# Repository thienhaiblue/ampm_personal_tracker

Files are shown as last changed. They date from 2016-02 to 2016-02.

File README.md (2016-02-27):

# ampm_personal_tracker
Security and safety is an essential feature for this product.Hence, it is extremely
critical to ensure the unit is able to make the SOS call and send the timely and
accurate GPS location to the dedicated party.
.
The GPS tracker shall be able to send GPS location, making emergency voice call
by pressing SOS button. In order to provide quick and accurate GPS location, cell
ID and AGPS technology is incorporated in this device. The data (GPS location,
remaining battery capacity etc.) shall be sent by both GPRS and SMS (the choice
will be determined in the detail logic flow and MMI document).
GSM frequency. Quad band 850/900/1800/1900.
GPRS type – Class 10, TCP/IP build in
GPS sensitivity - 159 dBm

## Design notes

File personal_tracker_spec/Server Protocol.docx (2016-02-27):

Protocol

Command first byte is D, like DRPT / DOPT mean is Device sent data to Server

Command first byte is S, like SRPT / SOPT mean is Server sent data to Device

Command Table

Comment | Description | Remarks
DLGI | Device send “LOG IN” request to Server
DRPT | Tracker Log with GPS / AGPS fixed | Status Report (GPS / AGPS fixed)
SRPT | Server responses, confirms Tracker log in, setup Report frequency & Power Saving Mode
DDPT | Tracker responses, confirms log in OK, wait for OTA
SOPT | Server set out OTA comment to Tracker
DOPT | Tracker confirms receipt of OTA comment
DLBS | Status Report | Status Report (GPS / AGPS not fixed)
DCHK | Tracker Log without GPS / AGPS fixed, Send out Cell ID location
SNOW | Find Device Command | Tracker sent out Status Report after receipt of command
SSVR | Server inform Device to change IP / TCP setting
DSVR | Device responses IP / TCP port to Server
SGFS | Geofence Set up to Device
DGFS | Device responses Geofence Setting
SFLO | Forced Device to Logout
SMDS | Man down setting
DMDS | Device responses Man down setting
DFLO | Device Layout responses | Server Maintenance Purpose

Format:ASCLL code

LEAD CODE | COMMAND CODE | CONNECTING SESSION | Total byte check | Parameter
@ 1 byte | CCCC 4 byte | CCC (0..999) 3 byte *Server to Device: An odd accumulation *Device to Server: An even accumulation | Ccc(000..999) 3 byte | (command string ) Please refer to every command.

Function | | Command | Description
Log In Request | Device Power ON / Initialize (Device → Server) | DLGI
| | | e.g. | @DLGI008045352352025153767MPERS_FamilyPal_2053_CMNET_209 @ is LEAD code DIGI is command code 008 is connecting session 045 is Total 85 byte 352352025153767 is IMEI MPERS_FamilyPal_2053_CMNET_209 is firmware Version
Status & GPS Location Report | Status Report Format (Device → Server) | DRPT
| | | e.g. | @DRPT00808535235202515376711120802541222.320729N111.3560030E32100000A000000000000000 @ is LEAD code DRPT is command code 008 is connecting session 085 is Total 85 byte 352352025153767 is IMEI 111208 = 2008/12/11 025412 = UTC time 2:54:12 22.320729N = GPS Latitude 113.560030E = GPS Longitude 000.0 = Speed Over Ground is 0 321 = Course Over Ground ( direction 321°) 00000 = Reserve A = GPS status 000000000000000 = 15 bytes reserve Refers to “Status Report Format”

Function | | Command | Description
| Status Report Format (Server →Device ) | SRPT | HH MM SS Reporting Frequency: Type0-9, Hour(0-99), Minutes (0-59), seconds(0-59)
| | | e.g. | @SRPT009007000030 @ is LEAD code SRPT is command code 009 is connecting session 007 is Total 7 byte 000030 is Report Frequency 30 sec
| Status Report Format (Device → Server) | DDPT | HH MM SS Reporting Frequency: Type0-9, Hour(0-99), Minutes (0-59), seconds(0-59)
| | | e.g. | @DDPT009007352352025153767000030 @ is LEAD code DDPT is command code 009 is connecting session 007 is Total 7 byte 352352025153767 is IMEI 000030 is Report Frequency 30 sec

Function | | Command | Description
Parameter setup | Device Initialization OTA setting (Server →Device ) | SOPT | SMS Setting Password , if you want use SMS to setting any parameter, you must use this password, the password set in Webs Type 0-9, Length = 4 Lone worker 0: OFF 1: ON (default 30 min) Lone worker Active (Min.) 0001~1000 Lone work countdown time 01-30 (Min) No Movement 0: OFF 1: ON (default 720 min) No Movement Active (HR.) 001~720 Auto-answer 0: OFF 1: ON Language 00-08 Mobile Number Type 0-9; Length = no control; Separate by “,”; use “,” to separate; Max. 6 Group
| | | e.g. | @SOPT014069000010030301720100+886289673211,+886289672515,+886968123456,+886,+886,+886 @ is LEAD code SOPT is command code 014 is connecting session 069 is Total 69 byte 0000 is SMS Setting Password 1 is Lone worker on 0030 is Lone worker Active at 30 min. 30 is Lone work countdown time (1-30min) 1 is No Movement on 720 is No Movement Active at 720 HR. 1 is auto answer on 00 is voice Language English Mobile phone number is +886289673211,+886289672515,+886968123456,+886,+886,+886,

Function | | Command | Description
Parameter setup | Device Initialization OTA setting (Device → Server) | DOPT | SMS Setting Password , if you want use SMS to setting any parameter, you must use this password, the password set in Webs Type 0-9, Length = 4 Lone worker 0: OFF 1: ON (default 30 min) Lone worker Active (Min.) 0001~1000 Lone work countdown time 01-30 (Min) No Movement 0: OFF 1: ON (default 720 min) No Movement Active (HR.) 001~720 Auto-answer 0: OFF 1: ON Language 00-08 Mobile Number Type 0-9; Length = no control; Separate by “,”; use “,” to separate; Max. 6 Group
| | | e.g. | @DOPT014069352352025153767000010030301720100+886289673211,+886289672515,+886968123456,+886,+886,+886 @ is LEAD code SOPT is command code 014 is connecting session 069 is Total 69 byte 352352025153767 is IMEI 0000 is SMS Setting Password 1 is Lone worker on 0030 is Lone worker Active at 30 min. 30 is Lone work countdown time (1-30min) 1 is No Movement on 720 is No Movement Active at 720 hr. 1 is auto answer on 00 is voice Language English Mobile phone number is +886289673211,+886289672515,+886968123456,+886,+886,+886,

Function | | Command | Description
Status & Cell ID Location Report (GPS no fix) | Status Report Format (Device → Server) | DLBS
| | | e.g. | @DLBS00808535235202515376711120802541222.320729N113.560030E000.032100000V000000000000000 @ is LEAD code DLBS is command code 008 is connecting session 085 is Total 85 byte 352352025153767 is IMEI 111208 =2008/12/11 025412= UTC time 2:54:12 22.320729N = Cell ID Latitude 113.560030E = Cell ID Longitude 000.0 = Speed Over Ground is 0 321 = Course Over Ground ( direction 321°) 00000 = Reserve V = without =GPS 000000000000000 = 15 bytes reserve Refers to “Status Report Format”
| Check Connection (Device → Server) | DCHK | IMEI NO. Type 0-9 , Length 15
| | | e.g. | @DCHK004015352352025153767 @ is LEAD code DCHK is command code 004 is connecting session 015 is Total 15 byte 352352025153767 is IMEI

Function | | Command | Description
| Find Device (Server -> Device) | SNOW | IMEI No. Type 0-9, Length 15
| | | e.g. | @SNOW004015352352025153767 @ is LEAD code SNOW is command code 004 is connecting session 015 is Total 15 byte 352352025153767 is IME
| Server Domain / Port Setup (Server -> Device) | SSVR | Change Server Domain & Port
| | | e.g. | @SSVR018016seniorcare.vicp.hk:6868 @ is LEAD code SSVR is command code 018 is connecting session 016 is total 16 byte seniorcare.vicp.hk is Domain 686 8 is Port
| Server Domain / Port Responses (Device -> Server) | DSVR | Server Domain & Port
| | | e.g. | @DSVR018016352352025153767seniorcare.vicp.hk:6868 @ is LEAD code DSVR is command code 018 is connecting session 016 is total 16 byte 352352025153767 is IME seniorcare.vicp.hk is Domain 686 8 is Port

Function | | Command | Description
| Geo fence Setup (Server → Device) | SGFS | Geo fence Center point / Longitude / Latitude / Radius (Meter)/Time(Min) All “Zero” if the Geo fence is turn OFF. Time : 00 ~ 59 Min.
| | | e.g. | @SGFS01901825.040701,121.815928,50,10 @ is LEAD code SGFS is command code 019 is connecting session 018 is total 18 byte 25.040701 is Latitude 121.815928 is Longitude 50 is radius (Meter) 10 is time (Min)
| Geo fence Setup Format (Device → Server) | DGFS | Geo fence Center point / Longitude / Latitude / Radius (Meter)/Time(Min) All “Zero” if the Geo fence is turn OFF. Time : 00 ~ 59 Min.
| | | e.g. | @DGFS01901835235202515376725.040701,121.815928,50,10 @ is LEAD code SGFS is command code 019 is connecting session 018 is total 18 byte 352352025153767 is IME 25.040701 is Latitude 121.815928 is Longitude 50 is radius (Meter) 10 is time (Min)

Function | | Command | Description
| Man down Setup (Server → Device) | SMDS | Man down 0 : OFF 1: ON Man down time 00~59 (min)
| | | e.g. | @SMDS020003001 @ is LEAD code SMDS is command code 020 is connecting session 018 is total 18 byte 0 is Man down off 01 is time (Min)
| Man down Setup Format (Device → Server) | DMDS | Man down 0 : OFF 1: ON Man down time 00~59 (min)
| | | e.g. | @SMDS020003352352025153767001 @ is LEAD code SMDS is command code 020 is connecting session 018 is total 18 byte 352352025153767 is IME 0 is Man down off 01 is time (Min)

Function | | Command | Description
| Forced Logout (Server → Device) | SFLO | IMEI No. Type 0-9, Length 15 This command to be used when Server Maintenance or abnormal operation was found
| | | e.g. | @SFLO004015352352025153767 @ is LEAD code SFLO is command code 004 is connecting session 015 is Total 15 byte 352352025153767 is IMEI
| Logout Responses (Device → Server) | DFLO | IMEI No. Type 0-9, Length 15 This command to be used when Power off device.
| | | e.g. | @DFLO004015352352025153767 @ is LEAD code DFLO is command code 004 is connecting session 015 is Total 15 byte 352352025153767 is IMEI

Status Report Format : (Total 70 Characters)

IMEI | Greenwich Date | Greenwich Time | Latitude | N/S | Longitude | E/W | Speed | Direction | Distance | GPS Fix | Status Alert
Xxxxxxxxx xxxxx | nnnnnn | nnnnnn | nn.nnnnnn | C | nn.nnnnnn | C | nnn.n | nnn | nnnnn | C | CCCCCCCCCCCCCCC
| DDMMYY | HHMMSS | nn.nnnnnn degree | N:NL S:SL | nn.nnnnnn degree | E:EL W:WL | (NM) | (degree) | (Meter) | Realtime: A:Fix OK V:Fix NG | Format refers to (P1)
15 | 6 | 6 | 9 | 1 | 10 | 1 | 5 | 3 | 5 | 1 | 15

(P1) Status Alert

Column | 1 | 2 | 3/4 | 5/6/7 | 8 | 9 | 10 | 11 | 12 | 13 | 14 | 15
Content | 0 | 0 | 00 | 000 | 0 | 0 | 0 | 0 | 0 | 0 | 0 | 0
Status | Check | Geo fence Check | GSM signal Check | Battery Voltage Check | Charging Check | Battery Low Check | Reserved | Man Down Check | Lone worker Check | No Movement Check | Reserved | Reserved

Status Alert Details

[1] 1st byte Detection SOS button
Value | Description
0 | Default, ( SOS off )
1 | SOS Key on
2 | SOS Key off
3 | Lone worker SOS
4 | Man Down

[2] Geo fence Check
Value | Description
0 | Default, No report on Geo fence
1 | Exclusion zone
2 | Inclusion zone

[3/4] GPRS Check
Value | Description
0~99 | CSQ : 0~99
| 4> CSQ = 99 | No signal
| 4 < CSQ <10 | Level 1
| 10 < CSQ <16 | Level 2
| 16 <CSQ <22 | Level 3
| 22 < CSQ <28 | Level 4
| 28 < CSQ | Level 5

[5/6/7] Battery Voltage Check
Value | Description
000~999 | Voltage with 2 decimal points (e,g. 4.15V >> 415)

[2] Geo fence Check
Value | Description
0 | Default, No report on Geo fence
1 | Exclusion zone
2 | Inclusion zone

[8] Charging Check
Value | Description
0 | Default, Not under Charging
1 | Under Charging

[9] Low Battery Check
Value | Description
0 | Default, Battery normal
1 | Low Battery, below 25%
2 | No Battery, 5% remained

[10] Reserved

[11] Man Down Check
Value | Description
0 | Default, No report
1 | Man down Active

[12] Lone worker Check
Value | Description
0 | Default, no report
1 | Lone worker Alert Active (Server set time reached)

[13] No Movement Check
Value | Description
0 | Default, no report
1 | No Movement Alert Active (Server set time reached)

[14] Reserved

[15] Reserved

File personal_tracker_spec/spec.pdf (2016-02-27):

Product Features

Security and safety is an essential feature for this product. Hence, it is extremely critical to ensure the unit is able to make the SOS call and send the timely and accurate GPS location to the dedicated party.
The GPS tracker shall be able to send GPS location, making emergency voice call by pressing SOS button. In order to provide quick and accurate GPS location, cell ID and AGPS technology is incorporated in this device. The data (GPS location, remaining battery capacity etc.) shall be sent by both GPRS and SMS (the choice will be determined in the detail logic flow and MMI document).

GSM frequency. Quad band 850/900/1800/1900.
GPRS type – Class 10, TCP/IP build in
GPS sensitivity - 159 dBm

## Industrial Design

## Physical Specifications

Item | Description | Specifications
Dimension ( Products) | Length | 66 mm
| Width | 43mm
| Thickness | 20 mm
Antenna | GPS | Internal
| GSM/GPRS | Internal

## Handset

Item | Description | Specification
Case Material | | PC
Dimensions | Handset | 66x43x20mm.
Weight | Handset | < 60 g
Water Resistance | Handset | IP57

## Environmental Specifications

Item | Description | Specification
Temperature | Operating range | -10 °C to 55 °C
| Storage range | -20 °C to 80 °C

Humidity | up to 95%

## Charging Cradle Specifications

Item | Description | Specification
Charging Cradle | SentryPal Speaker and Logo must be visible when in charging cradle. We have a concern that the base needs to have a bigger size so that it will not tip over easily when the person is putting the hand-held unit into the charger. | Uses standard AC Wall adaptor.
AC Adaptor | Standard AC Wall Adaptor | Tip _____ 110/220 Volts at 500 mA
Battery Charging | Via two metal prongs that make contact to Charging Station
Charging time – estimated from dead battery | | 2 hours

## Detail feature list

Physical dimension
1. Size (outside dimension include plastic) : 66x43x20mm (maximum)
2. Water proof and dust proof standard: IP57. The unit shall be robust enough for sudden impact (fall down action by end customer).
3. 4 pin connector for data
4. 1 button for SOS call, and 1 small button for other functions (e.g. power on/off, cancel)
5. Separate standalone charger for device.

Volume level. The device shall be set at maximum level. Speakerphone mode is automatic when the device is connected. It shall be over 90dB at 0.1m from speaker.

LED indication
1 for battery, 1 for GSM, 1 for
GPS Power specification
1. Talk time : continuous not less than 2 hours (base on 700mAH Li-Polymer or Li-ION battery. We continuously finding higher capacity battery e.g. 800mAH Li-Ion)
2. Battery life for GPS sending data (location / battery level) every 15 mins. : not less than 4 days in sleeping mode. Not less than 1 day in standby mode.
3. GPRS Data amount in 30 days base on GPS sending data (location / battery level) every 15 mins. : not more than 5M byte
4. Total charging time : 2 hours

5. Charging circuit. Protection circuit for battery and for the device shall be included. This is to ensure that there will not be over-charging, or not able to charge when the device is not charged for long period of time.

GPS
1. GPS Time to first fix – cold start (autonomous) 36 sec, warm start (autonomous) 36 sec, hot start (autonomous) < 1 sec.
2. Cell ID and AGPS technology shall also be integrated. During in-door condition where GPS is not obtainable, the last valid GPS location or cell ID location (whichever is more accurate) will be sent.
3. Geo-fencing

Voice prompt
1. Voice prompt provided for different application
2. DTMF detection for answering machine

User case / server control
1. During SOS emergency call, when connected, the device will be in speakerphone mode automatically. Sound level for speakerphone : 90dB in 0.1m from device
2. OTA command from dedicated server and dedicated SMS number, in particular sending configuration.
3. Motion sensor (3 axis accelerometer) is employed for detecting no motion in order to save power, as well as man down detection

Initial set up

See MMI below.

Appendix 5 Technical specification

## GSM/GPRS Specifications

Item | Description | specification
Air Interface | GSM or GPRS Quad Band | GSM 850 / 900 / 1800 / 1900 MHz class 4 (2 W) for 850/900 bands class 1 (1 W) for 1800/1900 bands
| GPRS | Class 10 (4 downlink, 2 uplink, max. 5) Mobile Station Class B PBCCH supported CS 1…CS 4 supported
| Power Consumption | Power Off - < 90 μA Idle Mode - <1.6 mA

| | Telephony GSM - < 300mA GPRS class 10 - 410 mA
GSM Sensitivity | 850/900 MHz | -110 dBm
| 1800/1900 MHz | -109 dBm
Messaging | SMS | PDU / Text mode / Cell broadcast
| AT Commands | 3GPP 27.005, 3GPP 27.007 3GPP 27.010 MUX Protocol

## GPS Specifications

Parameter | Description | Specification
GPS Tracking | Tracking location | Handset MUST be ON in order to be tracked (MCU and GSM must be ON in order to receive OTA command from server)
| Tracking ON/OFF Factory setting OFF | Controlled by Web Dashboard/User
Time between Pings | This is the time between each ping of the location. | This is a variable set by the user on the web dashboard. The web dashboard will send the variable minutes between pings.
Chipset | U-blox | AMY-6M
Receiver type | 50 Channels GPS L1 frequency, C/A Code SBAS: WAAS, EGNOS, MSAS
Time-To-First-Fix2 | Cold Start (Autonomous) | <36 sec.
| Hot Start (Autonomous) | <36 sec.
Data packet size - GPS update | | 128 bytes of data per transmission re: eo-locating
Sensitivity4 | Tracking & Navigation | -159 dBm
| Reacquisition | -159 dBm
| Cold Start (Autonomous) | -146 dBm
Maximum Navigation update rate | | 5Hz
Accuracy | Position | 2.5 m CEP - Circular Error Probability
| SBAS - Satellite-Based Augmentation Systems | 2.0 m CEP - Circular Error Probability
Time pulse frequency range | Configurable | 0.1 Hz to 1 kHz
Operational Limits | Dynamics | ≤ 4 g
| Altitude6 | 50,000 m
| Velocity6 | 500 m/s

Appendix 6 MMI

## Input

Item | Description | Specification
Mic
4 pin connector | Update firmware Debug message
EMERGENCY button Recessed into case to help prevent accidental pushes | Hold for 1 second SentryPal must be ON to initiate EMERGENCY call | Initiate Emergency call: Voice Prompt [EMERGENCY call is being placed - please stand by] prompt 3.1, 3.2 Prompt played 1 time
| Hold for 1 second during incoming call/ringing. | Answering Incoming Call
Small Dark Gray button | Hold for 1 second – during an active call | Ends call and resets the handset Voice Prompt [Hanging UP] prompt 3.3
| Hold for 4 seconds – when phone is ON Hold for 4 sec. – when phone is OFF | Turn SentryPal OFF Voice prompt [Power OFF] prompt 1.2 Turn SentryPal ON Voice prompt [Power ON] prompt 1.1
Hold for 1-4 seconds – when | System Check:
phone is ON | Announce battery status
| [Battery OK] prompt 2.1
| > 25% battery capacity
| [Recharge Battery Soon]
| prompt 2.2
| < 25% battery capacity
| [Lone Worker ON]
| prompt 5.3
| IF - Lone Worker option is
| set (This option is
| controlled via the web and
| OTA programming)
| [No Service Coverage]
| prompt 2.4
| IF - No GSM Service
| Signal
| [No Current GPS Fix]
| prompt 2.5
| If - Not able to track GPS
| satellites [Version # X]
| prompt 6.7

To announce software
version during system
check
Hold for 1 second | Reset Lone Worker Alarm
| Lone Worker is a special use
Lone Worker is a feature used | feature that uses the 3 axis
when someone is working in a | accelerometer to measure NO
remote area by themselves. The | movement. If movement is not
handset watches for movement | detected in n period of time, an
(normal activity of the person), if | alarm in the handset sounds – if
no movement is detected in some | the alarm is not reset with the Test
period of time an alarm is | button ( How many sec.? n period
sounded. If the person does not | is selected via the web dashboard
manually reset the alarm, it is | and OTA programming )
assumed an accident has | the SentryPal will automatically
happened and the handset | initiate an EMERGENCY call and
automatically places an | reporting current position via
Emergency call. The Lone | SMS.
Worker feature is controlled via | During charging? same
the Web dashboard then settings
are OTA to the handset

## LED Outputs

Item | Description | Specification
| BATTERY - RED LED | Off: When battery is > 25% capacity Blinking: 0.3 seconds On – 2 seconds off When battery is < 25% capacity Charging – when in cradle: Sinusoidal Pattern - On/Off/On (1 second from Off to Full Brightness, 1 second from Full Brightness to Off): Solid– when in cradle: When battery is fully charged
| GPS - BLUE LED Only ON during: During Emergency call | Solid: SOS to activate GPS, and GPS signal is OK Blinking: 0.3 seconds On – 0.3 seconds Off When SentryPal is

acquiring GPS signal or
NO GPS signal is
available.
GPS will be sent via SMS during Emergency Call
Handset will send last
known position right away, then send current position as soon as it is updated
GSM – GREEN / yellow LED | Flashing Green (0.3 sec. ON + 0.3
| sec. OFF) x 2 cycles for every 5
GSM LED will be on anytime the | sec:
phone is powered ON. This will | Anytime the SentryPal has a GSM
allow the user to know that they | connection
have GSM service coverage with
just a quick glance | Flashing Yellow (0.3 sec. ON + 0.3
| sec. OFF) x 2 cycles for every 5
| sec:
| When SentryPal is acquiring GSM
| service signal or NO GSM service
| available

## SPEAKER - Voice Announcements

Item | Description | Specification
Speaker | RING TONE | We will supply WAV file. Will be more a traditional mechanical ring sound rather than electronic
| Speaker Volume | Always set to maximum
| Voice Announcements: Power: 1.1 - Power ON 1.2 - Power OFF 1.3 - Version X 1.4 - Lone Worker ON System Check: 2.1 - Battery OK | The handset will have flash memory large enough to store 4 minutes of voice prompts –this will include Spanish and French languages Languages will be selected via Web and OTA Turning SentryPal On Turning SentryPal OFF Announces software version Confirms Lone Worker features is ON Battery > than 25% capacity

2.2 -Rech arg e Batt ery
| Soon | Battery < than 25% capacity
2.3 - Warning Tone | #1 | Low battery alarm?
2.4 - No Service Coverage | No GSM Service/Signal
2.5 - No current GPS Fix | Not able to track GPS satellites

EMERGENCY SentryPal Call:
3.1 - EMERGENCY call is being placed | Unit is starting the EMERGENCY call
3.2 - Please stand by | Standby
3.3 - Hanging Up | Ending the call process
3.4 - Hanging up & dialing next number | Call was not successful, moving to next
EMERGENCY FamilyPal Call: | number
3.1 - EMERGENCY call is being placed | Unit is starting the EMERGENCY call
3.2 - Please stand by | Standby
3.3 - Hanging Up | Ending the call process
4.5 - Dialing 911 | Dialing local 911
4.6 - Please wait for call back | Prompt played during wait for call back

Lone Worker:
5.1 - Are you OK? – Press test button | Lone Worker timer expiration warning
5.2 - Warning Tone #1 | Tone played between warning voice
| prompts
5.3 Lone Worker ON | Announces the Lone Worker feature is ON

Misc:
6.1 - . - Point | Point to separate numbers
6.2 - Ringing tone | Ring for incoming tone – Will be a
| traditional mechanical ring sound rather
6.3 - Beep tone #1 | than electronic
6.4 - Failed to connect – trying again
6.5 - Call unsuccessful
6.6 – Dialing
6.7 – Version # | The version number is the software revision
| that is currently installed in the handset.
Numbers: | The number is manually increased each
1A – One | time the software is changed – to help tech
2A – Two | support differentiate different software
3A – Three | versions in the field.
4A – Four | During system check.
5A – Five
6A – Six
7A – Seven
8A – Eight
9A – Nine
0A - Zero

## Power Specifications

Item | Description | Specification
Battery | Replaceable Industry | 3.7 V, 700 mAh Li-Ion
| Standard
Battery Charging | Via two metal prongs that
| make contact to Charging
| Station on bottom side so that
| logo is facing up.
Power consumption | Operation mode (GSM) | 130mA~ 270mA
| Standby mode (GPS On) | 70±5mA
| Power saving mode (GPS | 7mA
| Off)
Talk Time | Around 2 Hours talk time on | GPS off
| full charge (GPS off)
Standby Time | In Sleep mode – with | Handset standby time when
| everything off. How many | GPS is transmitting every:
Sleeping mode = MCU ON, GSM OFF, | days will battery life be? | (GSM OFF)
GPS OFF
| Please tell us the wake-up | 10 minutes = ?
| | 15 minutes = target 1 day
Standby mode = MCU ON, GSM ON, | time for the GSM system? | 30 minutes = ?
GPS OFF | Shall be few sec. | 60 minutes = ?
| Wake up the system from | In sleeping mode,
| sleep mode: | (GSM ON).
| EMERGENCY button? | 10 minutes = ?
| Test button? | 15 minutes = ? ~ 4 days
| Shall be few sec. | 30 minutes = ?
| | 60 minutes = ?
Low Battery Alerts | When Battery < 25%. | Announce battery status -Voice prompt 1 time: [Recharge Battery Soon] prompt 2.2 RED LED starts Blinking Low battery message is sent via GPRS

## 3-Axis Accelerometer Specifications

Parameter | Description | Specification
Fall Detector | Not in this generation
We will use the accelerometer sensor to detect movement. | Unit has not moved at – accelerometer detects NO motion SentryPal MUST be ON for it to monitor motion. If SentryPal is OFF – NO inactivity messages will be sent | If more than X hours of no movement - an inactivity message is sent via GPRS. X hours interval is set through the web dashboard. If Lone Worker feature is set: If movement is not detected in n minutes of time, an alarm in the handset sounds – if the alarm is not reset with the Test button the SentryPal will automatically initiate an EMERGENCY call and reporting current position via GPRS or SMS.
| Accelerometer has detected movement but GPS has not | No inactivity messages are sent

## Programmable Phone Variables & Features

## (Programmed via the Web Dashboard)

Parameter | Description | Specification
Time Between GPS Pings | The user can customize how often the unit will wake-up and get a new location and send it out. | Can be set to as low as 1 minute -will typically be 15 minute or 30
No Movement -Accelerometer | The user will be able to set X time of “no movement at all” before the phone will then send an inactivity message via GPRS | Can be set to as low as 1 minute -will typically be 12 hours.
| EMERGENCY call Lone Worker factory setting is OFF but selectable via OTA

mi
nut
e
int
erv
al. | RC command
Lone Worker | This is a variation on the No Movement | When Lone Worker alarm is
| feature. When n time (1-1000 minutes – | triggered for x minutes (1-30 minutes
| controlled on Dashboard) of inactivity is | controlled on Dashboard), the unit
| reached – the phone will beep for x minutes | stops the beeping and an
| (1-30 minutes controlled on Dashboard) – | EMERGENCY call is initiated –
| and if the user has not pushed the gray test | location being sent via GPRS or
| to reset – the phone will initiate an | SMS.
GSM ON or | The user will have the choice of having the | Set via the Web Dashboard.
STANDBY | GSM be off – and only come on when the
| EMERGENCY button is pushed. Or, of | Each time the handset is put into the
| having the GSM on all the time to take | charging cradle, the GSM will
| incoming calls as well. | automatically turn ON to check for
| When EMERGENCY button is pushed – | OTA changes and updates
| with GSM either ON or in Standby, the
| EMERGENCY call is initiated
SentryPal – Central | The Central Station will use the Caller ID | The SentryPal will have 2 telephone
Station version: | information from the SentryPal to access the | numbers (The second number is a
Telephone Numbers | customer profile and account information. It | back-up number in case the call
& Account Code | will be a variation of the Elevator Line. | cannot go through to the first
| | number).
| | May be preset in factory?
| | No, Controlled via web and OTA
| | All IP address, port no., APN no.,
| | mobile carrier network must be
| | preset in the device at factory.
FamilyPa | The user can program the telephone | The Friends & Family product can
Different software | numbers to be used by the phone via the | learn up to 5 numbers. (4 friends’
versionl | web based dashboard. | numbers and the 911 number).

Programmable via dashboard

## Communication Software Features

1. GPS Communication Protocol: The wireless service providers and others are pass-through networks; they just send packets in any format, they store nothing. The UDP protocol is likely best for accepting the packets. Key point is we get location data via what amounts to an internal LAN with the wireless service providers except when the voice channel is engaged, in which case we send location data as a text message. TCP/IP
2. Alerts & Notifications: These are sent via GPRS or SMS.

## WEB Software Features

This web software is handled by customer. You need to ensure the device can communicate with the server and the server can make all such communication. Format prefer to be XML.

1. WEB Dashboard: Each SentryPal/FamilyPal account has a secure web log-in for the Account Owner where the account ID is an email, and password. Account owner can manage (including change) his name, physical mailing address, email address, office/home/cell phone number, etc.
test account (user name, password, IP address and port no.) will
be provided for testing and development.
2. Account Owner can add his email address(es), and cell phone number(s) for alerts & notifications. Text messages sent to cell phones are sent as SMS
3. Account Owner can add/change/delete other users in the same manner, to receive alerts & notifications.
4. Battery Status: Notifications relating to device battery status go to the Account Owner via SMS
5. Power-on Status: Notifications relating to power On/Off go to the Account Owner via SMS,
6. Device Not Moved Status: Notifications if the handset has not moved substantially (device has a 3-axis accelerometer) go to the Account Owner, via GPRS or SMS, times are customizable on the web dashboard.
7. Lone Worker: This feature is to monitor the activity of the person carrying the device. If the device not having been moved substantially (device has a 3-axis accelerometer) in n minutes/hours, the device sounds an alarm. The user must push the Test button within x (1-30) minutes of the alarm sounding – selectable in the web dashboard. If the alarm is not reset, the device automatically places an EMERGENCY call and reports current position via GPRS or SMS. The length of the n activity timer is selectable in the customers web based dashboard
Lone Worker is controlled via Web and OTA
8. Bread-Crumb Trail. Account Owner can see where the device is based on the most recent successful ping, on a Google Map, date & time-stamped. The last 1,000 data points are stored and visible on the web dashboard. Below the Google Map that displays the ‘dots’ on the screen is a slider that goes from the left at 0 to the right at 14 days. Sliding the slider along this screen will display only those points that are up to that point in time on the slider. Also – the ‘dots’ colored depending on age. The most current dot is the biggest and bright red with a blue ring around it. The other dots have no blue ring – and fade from bright red to gray as time gets older. Holding the mouse over any Dot give the Date and Time stamp as well as the Latitude and Longitude.

The web designer will figure this out

9. Geofences. 1 Geofence can be created and each given an associated label; alerts go to the Account Owner (and any others as listed in the web dashboard) when a boundary has been crossed.
We need to be careful to avoid rapid boundary alerts being sent when the person is traveling close or parallel to a boundary. Messages are to be sent via GPRS
10. Geofence Design & Granularity: Down to | ¼ mile radius | if possible, ideally
circle/square/rectangle or “Draw Your Own.”
Web designer will figure this out and will make it as simple as possible. Handset sends GPS location to web server and the web dashboard makes the boundary calculations and then sends our notification messages.
11. Alerts: Alerts are sent out for the following reasons:
i. Geo-fence boundary crossings. This is only possible when GSM is ON and GPS is ON. When
ii. EMERGENCY button pushed.
12. Notifications: Notifications are sent out for the following reasons:
i. Powered OFF
ii. No Movement in X hours GPS/Accelerometer iii. Battery < 25%
13. FamilyPal: Account Owner can configure a call flow – call a list of 4 friends or family members and/or 911, depending on software set-up on the web dashboard.
14. SentryPal: This model always calls a central station, it is 2-way voice communication between the SentryPal and central station and the central station uses the Caller ID, IMEI or SIM card no. (IMSI) information to access the customers account and profile information. This will be up to the central station to receive this information from the incoming call and access the customer account information.
15. Find Device Now: Account owner can “find device now” which pings without regard to the every “n” minutes ping factory setting, and see a resulting Google map image with a thumbtack saying “device here now” or “cannot get a fix on the device, but it was last here” [show last successful ping, time & date-stamped]. GSM MUST be ON for the “find device now” feature to work.
Find Device feature factory setting is ON – but selectable via OTA programming Factory setting to update position is every 15 minutes.

If the handset is POWER OFF and / or the battery capacity is <25%, the handset will send the GPS location and low battery status message via GPRS. This same message will also be sent when the handset is powered OFF - turning off with the power button or if the battery is completely exhausted. This will help find a misplaced handset as well as notify the user of the low battery status.

## Emergency Call Flow

Answering incoming calls – SentryPal and FamilyPal:
a. The ability to answer incoming calls is controlled on the user’s dashboard. The factory setting will be NO INCOMING calls – as it increases the customer’s monthly costs dramatically. OTA ability to turn incoming calls ON and OFF
b. If the answer feature is enabled there will be 2 answer modes;
i. Automatic Mode – this allows the phone to automatically answer the incoming call without pushing any button. This will be helpful for the family or caregiver to listen in to
what the user is doing without any interaction from them ii. Manual Mode – Incoming calls are allowed but the user will have to manually answer any incoming calls by pushing the Emergency button while the phone is ringing. OTA ability to turn incoming calls On and Off

## SentryPal

(Handset MUST be powered ON before an Emergency Call can be placed)

1. Emergency Button is pushed - voice prompt [Emergency Call is being placed, Please standby] prompt 3.1,3.2
2. SentryPal sends GPS location via GPRS, (if it does not have current location fix, handset will send GPS information via SMS during the Emergency call. The last valid position is sent and then as soon as the current position is fixed, a second SMS GPS location message is sent).
3. SentryPal calls central station via GSM network – Central station phone numbers are programmed via OTA
a. This is a continuous call cycle until one of the 2 numbers
is connected or a total to 9 cycles is completed
4. Central Station receives call – central station receives call and uses Caller ID info to identify customer account and profile. Caller Id information is what the central stations are currently using to identify the incoming call.
5. Central Station operator receives GPS location information – via customer’s server
6. Central Station operator talks with customer – half duplex
(same communication that current mobile phones use)
7. Call is ended by Central Station operator hanging up – SentryPal and the GSM network will automatically detect the call has ended and the handset automatically hangs up and resets
8. SentryPal hangs up and announces the Battery Status – voice prompts [Battery OK or Recharge Battery Soon] prompts 2.1 or 2.2 and returns to standby mode - this is very important for the customer to be reminded what the battery status is every time they use the phone.

## FamilyPal:

(Separate software from SentryPal and E911 compliant) (Handset MUST be powered ON before an Emergency Call can be placed

There are 3 modes of the same FamilyPal version:
1. Friends Only – where is only contacts people on the “friends” list – created on the web dashboard and OTA to the handset
2. Friends + 911 – where all of the friends are contacted via SMS but if no one calls back within 3 minutes the handset automatically calls 911– created on the web dashboard and OTA to the handset
3. 911 Only – where the handset calls 911 immediately after the Emergency button push.
1. Emergency Button is pushed- voice prompt [Emergency Call is being placed, Please standby] prompt 3.1,3.2
2. FamilyPal send an Emergency Text message via SMS “There is an Emergency – Please call xxx-xxx-xxxx immediately” (xxx-xxx-xxxx is the FamilyPal mobile number) to all members on the Contact List – up to 4 contacts. All contacts on this list MUST have the ability to receive Text – SMS messages
3. FamilyPal sends GPS location via GPRS (not SMS) The message is being sent to the customer’s server – both the GPS location and the text messages to be sent to the “friends” list so the “friends” can call back. (if it does not have current location fix, handset will send GPS information via SMS during the Emergency call) to all members on the Contact List. When SOS button is pressed, the device will send the Last valid position to server via SMS. When location is fix, it will send to server via SMS
4. FamilyPal has 3 modes – Friends Only, Friends + 911 and 911 Only (Controlled by the users dashboard):
a. Friends Only
i. The Emergency button is pushed – voice prompt
[Emergency | call | is | being | placed, | Please
standby] prompts 3.1, 3.2
ii. The FamilyPal send out text messages to all numbers on the call list
iii. The handset plays the voice prompt [Please wait for call back] prompt 4.6 every 10 seconds
iv. The handset waits 3 minutes for the call to be returned.
v. If the call is not returned within the 3 minute period another text message is sent to all numbers on the call list – it will make a total of 9 attempts (3 minutes apart) to send text messages to the numbers on the call list
vi. When the call is returned, the handset will automatically answer the incoming call – there is a normal 2-way voice conversation between the caller and the FamilyPal user
vii. As soon as the FamilyPal answers the next incoming call, it sends out SMS messages to all on the Contact List “Emergency Call responded by xxx-xxx-xxxx” (xxx is the phone number of person that first called back)

viii. Call is ended by detecting the far end hanging up, the handset and the GSM network will automatically detect the call has ended, automatically hanging up the handset. The handset performs a the Battery Status – voice prompts [Battery OK or Recharge Battery Soon] prompts 2.1 or

### 2.2 and returns to standby mode

b. Friends + 911
i. The Emergency button is pushed – voice prompt
[Emergency | call | is | being | placed, | Please
standby] prompts 3.1, 3.2
ii. The FamilyPal send out text messages to all numbers on the call list (No text message is sent to 911)
iii. The handset plays the voice prompt [Please wait for call back] prompt 4.6 every 10 seconds
iv. The handset waits 3 minutes for the call to be returned
1. If the call is returned within the 3 minute period, the handset will automatically answer the incoming call – there is a normal 2-way voice conversation between the caller and the FamilyPal user.
2. If the call is not returned within the 3 minute period, the phone automatically calls 911– GPS information is automatically sent during a call to 911 (this is done through cell ID via mobile carrier). Do you want the GPS location also sent to the preset no. by SMS? That means the device will only call the preset no. once, if no answer, it will go straight to 911. This is correct! – it sends the emergency Text message, waits 3 mintues for a call back. If call back is NOT received within 3 minutes, the handset calls 911 directly. The FamilyDial will remain on the 911 call until the handset detects that 911 has hung up.
v. As soon as the FamilyPal answers the incoming call or calls 911, it sends out SMS messages to all on the Contact List “Emergency Call responded by xxx-xxx-xxxx or 911” (xxx is the phone number of person that first called back or 911). vi. Call is ended by detecting the far end hanging up, the handset and the GSM network will automatically detect the call has ended, automatically hanging up the handset. The handset performs a the Battery Status – voice prompts [Battery OK or Recharge Battery Soon] prompts 2.1 or

### 2.2 and returns to standby mode

c. 911 Only
i. The Emergency button is pushed – voice prompt
[Emergency | call | is | being | placed, | Please
standby] prompts 3.1, 3.2.
ii. The FamilyPal calls 911– GPS information is automatically sent during a call to 911 – E911 format (this will be done through cell ID via mobile carrier)
iii. There is a normal 2-way voice conversation between the 911 operator and the FamilyPal user
iv. Call is ended by detecting the far end hanging up, the handset and the GSM network will automatically detect the call has ended, automatically hanging up the handset. The handset performs a the Battery Status – voice prompts [Battery OK or Recharge Battery Soon] prompts 2.1 or 2.2 and returns to standby mode

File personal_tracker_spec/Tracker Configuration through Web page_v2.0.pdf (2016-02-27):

AMBOVN | Dec 8th 2013

# Tracker Configuration through Web page

### 1. Login

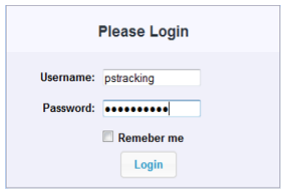
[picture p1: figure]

### 2. Navigate to “Manage” page, select “Manage Devices”

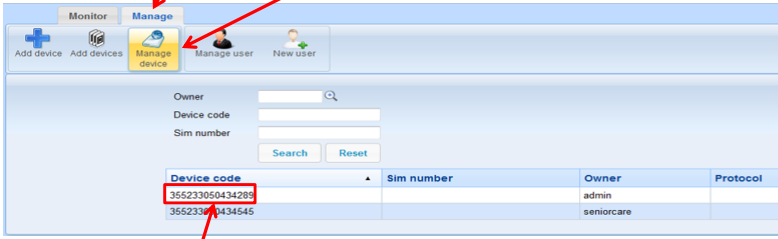
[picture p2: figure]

### 3. Select device IMEI to open Configuration UI

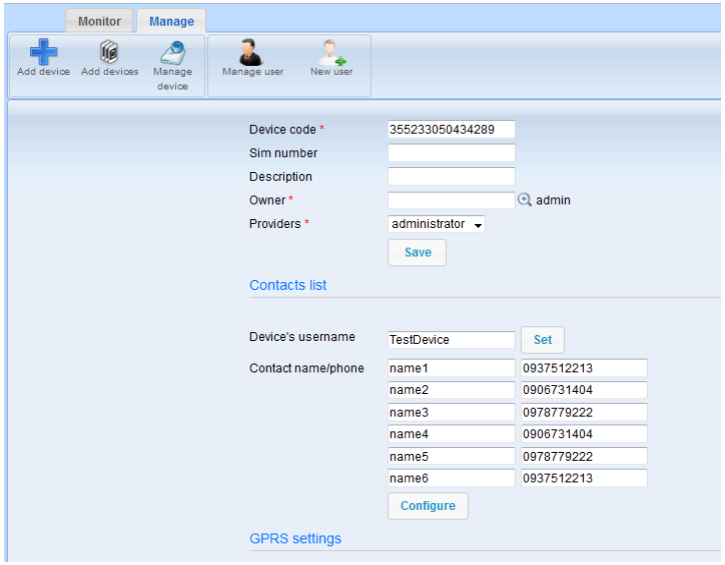
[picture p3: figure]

### 4. Enter the device SIM number/phone number. This is necessary for the web to remote wake up a device, making the device responds for web

commands immediately.

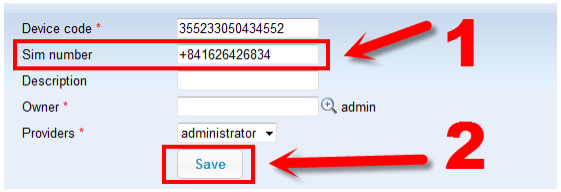
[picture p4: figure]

### 5. Configuration items

### a. Contact list

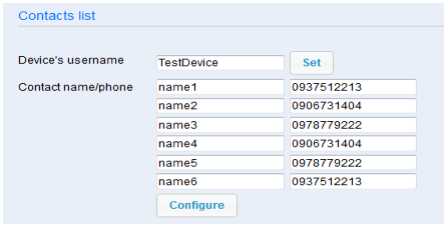
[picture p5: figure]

### b. GPRS settings

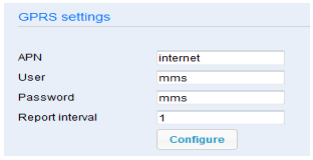
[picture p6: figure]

Report interval unit is minute. Range: [1, 30]

### c. Emergency settings

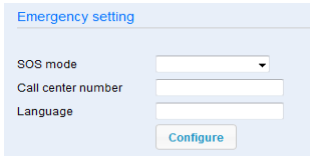
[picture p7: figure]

Language: enter 0 for English, 2 for Chinese

### d. Server parameters

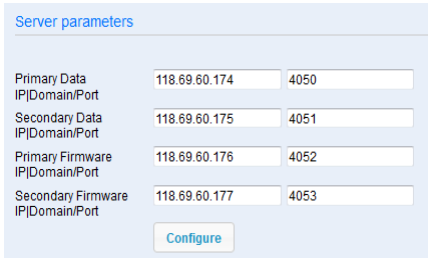
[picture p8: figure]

Each server is configured via 2 text boxes in each row:

- 1

st box: server’s IP or domain
- 2

nd box: port number. Range: [1, 65535]

Primary & secondary servers have to use the same type of address: IP for both, or domain for both. It is impossible to set primary server uses IP & secondary server uses domain (or vice versa).

### e. Feature set

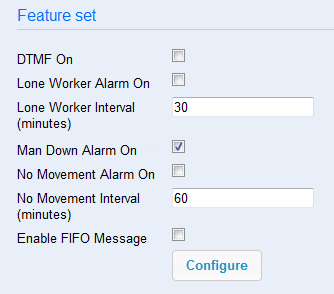
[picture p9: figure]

Lone Worker Interval unit is minute. Range: [1, 1000]

Lone Worker Countdown Time unit is minute. Range: [1, 30]

No Movement Interval unit is minute. Range: [1, 1000]

### f. GEO Fence settings

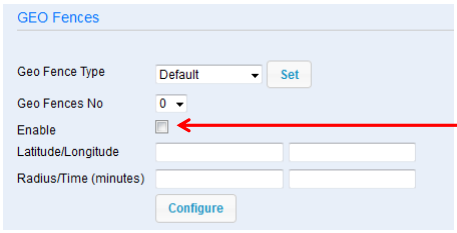
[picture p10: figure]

Radius unit is meter.

Time unit is minutes. Range: [1, 1000]

Select from 0 -> 9

### 6. Upload device configuration to Web page

This section will help you to understand how the device configuration is synchronized with Web page configuration. The configuration synchronization happens in the direction from the device to the Web page.

When the device is connect to a PC through USB cable and Parameter Setup software opened. You can configure any settings of the device through USB interface.

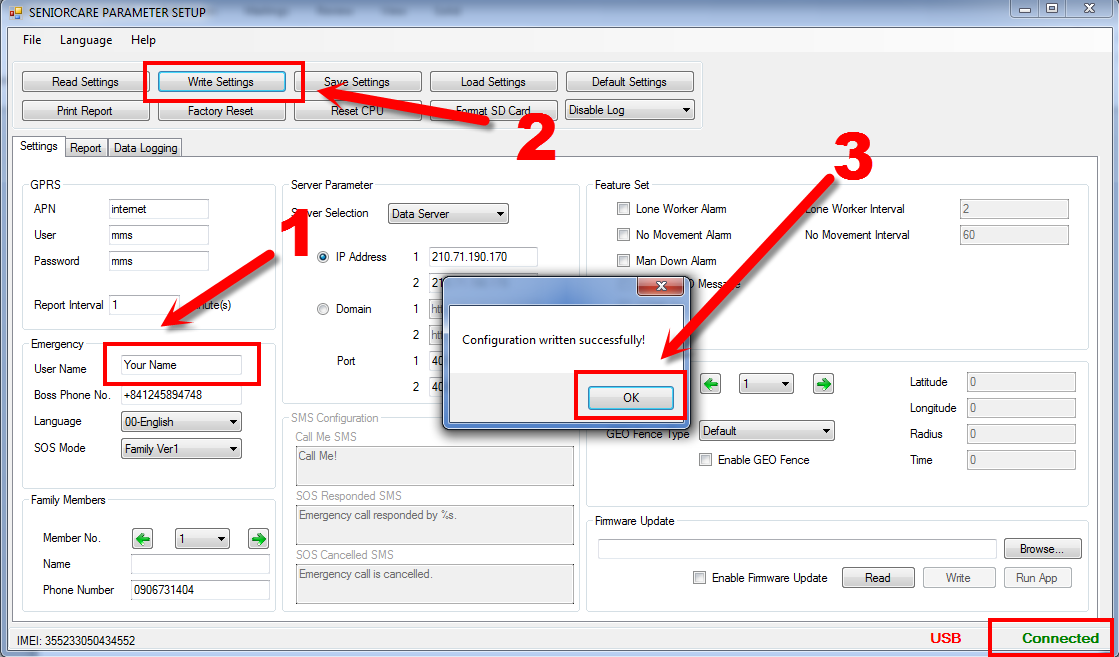
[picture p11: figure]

The device then will try to upload it’s configuration to Web server using GPRS connection. After 3-5 mins, go to Web page, in the Device Configuration, you would see the changes.

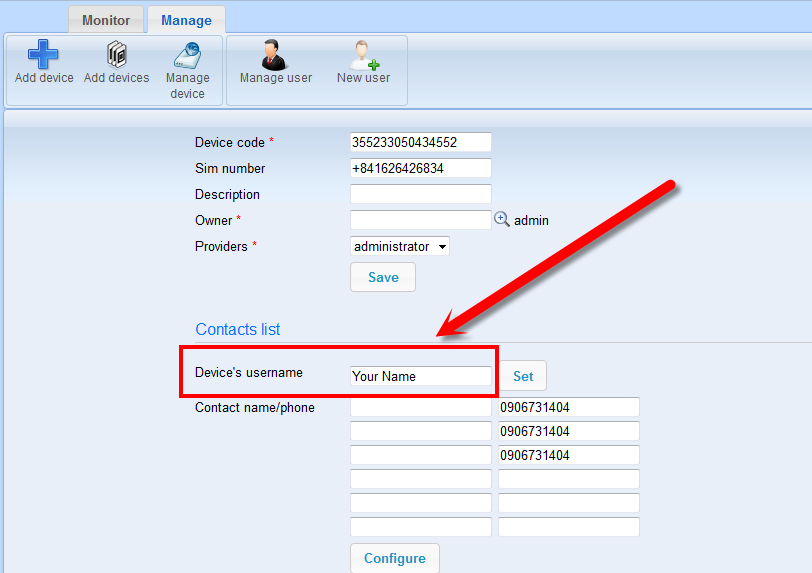
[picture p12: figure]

The synchronization process will be aborted if while uploading, user uses Web page to configure the device (in the previous section).

Only one configuration method is supported at a time.

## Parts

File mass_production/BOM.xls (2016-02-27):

Comment | Designator | Description | Digi-Key Part Number | Footprint | Manufacturer | Manufacturer Part Number | Quantity | Unit Price | Total
100nF-16V-20% | C3, C5, C16, C20, C21, C22, C23, C24, C25 , C26, C27, C28, C37, C38, C40, C73, C74, C75 | CAP CER 0.1UF 16V Y5V 0402 | 311-1047-1-ND | C0402 | Yageo | CC0402ZRY5V7BB104 | 18 | 0.00250 | 0.0450
10uF-6V3-20% | C6 | CAP CER 10UF 6.3V 20% X5R 0603 | 490-3896-1-ND | C0603 | Murata Electronics North America | GRM188R60J106ME47D | 1 | 0.07873 | 0.0787
1uF-6V3-20% | C7, C10, C31, C36, C41, C42, C43, C70 | CAP CER 1UF 6.3V Y5V 0402 | 311-1377-2-ND | C0402 | Yageo | CC0402ZRY5V5BB105 | 8 | 0.00465 | 0.0372
15p-50V-5% | C8 | CAP CER 15PF 50V 5% NPO 0402 | 311-1017-1-ND | C0402 | Yageo | CC0402JRNPO9BN150 | 1 | 0.00270 | 0.0027
33p-50V-5% | C9 | CAP CER 33PF 50V 5% NPO 0402 | 311-1020-1-ND | C0402 | Yageo | CC0402JRNPO9BN330 | 1 | 0.00270 | 0.0027
100u, ceramic | C11 | CAP CER 100UF 10V 20% X5R 1812 | 445-7743-2-ND | C1210 | TDK Corporation | C4532X5R1A107M | 1 | 0.55800 | 0.5580
47p-50V-5% | C12, C13, C17, C18, C19 | CAP CER 47PF 50V 5% NPO 0402 | 311-1021-1-ND | C0402 | Yageo | CC0402JRNPO9BN470 | 5 | 0.00270 | 0.0135
27p-50V-5% | C14, C15 | CAP CER 27PF 50V 5% NPO 0402 | 311-1019-2-ND | C0402 | Yageo | CC0402JRNPO9BN270 | 2 | 0.00270 | 0.0054
22p-50V-5% | C29, C34 | CAP CER 22PF 50V 5% NPO 0402 | 311-1018-2-ND | C0402 | Yageo | CC0402JRNPO9BN220 | 2 | 0.00270 | 0.0054
100p-50V-5% | C35 | CAP CER 100PF 50V 5% NPO 0402 | 311-1024-2-ND | C0402 | Yageo | CC0402JRNPO9BN101 | 1 | 0.00270 | 0.0027
10uF-6V3-20% | C39 | CAP CER 10UF 6.3V 20% X5R 0603 | 311-1448-1-ND | C0402 | Yageo | CC0603MRX5R5BB106 | 1 | 0.06176 | 0.0618
LED BLUE | D1 | LED BLUE CLEAR THIN 0603 SMD | 160-1446-2-ND | LED0603-G | Lite-On Inc | LTST-C191KGKT | 1 | 0.03780 | 0.0378
LED RED | D2 | LED RED CLEAR THIN 0603 SMD | 160-1446-2-ND | LED0603-G | Lite-On Inc | LTST-C191KGKT | 1 | 0.03780 | 0.0378
LED GREEN | D3 | LED GREEN CLEAR THIN 0603 SMD | 160-1446-2-ND | LED0603-G | Lite-On Inc | LTST-C191KGKT | 1 | 0.03780 | 0.0378
BAT43XV2 | D4, D5, D10, D11 | Diode Type SMD | BAT43XV2CT-ND | SOD-523F | Fairchild Semiconductor | BAT43XV2 | 4 | 0.01822 | 0.0729
GSM Antena conecter | E2 | Header, 5-Pin |  | A10343-GSM850/900/1800/1900/WCDMA |  |  | 1 | 0.02 | 0.0200
touch_pin | J4, J5 | Socket |  | TOUCH_PIN |  |  | 2 | 0.01 | 0.0200
12nH-5% | L2 | INDUCTOR 12NH 300MA 0402 | 490-2624-2-ND | R0402 | Murata Electronics North America | LQG15HS12NJ02D | 1 | 0.01872 | 0.0187
1uH | L3 | INDUCTOR 1.0UH 150MA 0603 | 490-4022-2-ND | L0603 | Murata Electronics North America | LQM18FN1R0M00D | 1 | 0.03756 | 0.0376
SIM CARD HOLDER | P3 | SIM _CONNECTOR_410108105011-2LF |  | MICRO_SIM_SOCKET |  |  | 1 | 0.5 | 0.5000
Spk | P6 | Header, 2-Pin |  | SPEAKER-S12A28 |  |  | 1 | 0.3 | 0.3000
Header 3 | P7 | Header, 3-Pin |  | BAT_CON |  |  | 1 | 0.1 | 0.1000
GPS Antena Connecter(NA) | P22 | GPS Antena |  | IPX SMD PCB Plug |  |  | 1 | 0.25 | 0.2500
BSS138 | Q1, Q3, Q8 | MOSFET N-CH 50V 200MA SOT23-3 | BSS138-FDICT-ND | SOT23-3 | Diodes Inc | BSS138-7-F | 3 | 0.06575 | 0.1973
AO3401A | Q2 | MOSFET P-CH -30V -4.3A SOT23 | 785-1001-1-ND | SOT23-3 | Alpha & Omega Semiconductor Inc | AO3401A | 1 | 0.12400 | 0.1240
4k7-5% | R1, R2, R9, R10, R20, R21, R23, R24, R25, R26, R27, R72, R73, R74 | RES 4.7K OHM 1/16W 5% 0402 SMD | 311-4.7KJRCT-ND | R0402 | Yageo | RC0402JR-074K7L | 14 | 0.00178 | 0.0249
10k-5% | R3, R4, R11, R17, R28, R70, R71 | RES 10K OHM 1/16W 5% 0402 SMD | 311-10KJRCT-ND | R0402 | Yageo | RC0402JR-0710KL | 7 | 0.00178 | 0.0125
1k-5% | R5, R6, R7 | RES 1.0K OHM 1/16W 5% 0402 SMD | 311-1.0KJRCT-ND | R0402 | Yageo | RC0402JR-071KL | 3 | 0.00178 | 0.0053
100k-5% | R8, R12, R15, R29, R31, R32 | RES 100K OHM 1/16W 5% 0402 SMD | 311-100KJRCT-ND | R0402 | Yageo | RC0402JR-07100KL | 6 | 0.00171 | 0.0103
22-5% | R13, R14, R16 | RES 22 OHM 1/16W 5% 0402 SMD | 311-22JRCT-ND | R0402 | Yageo | RC0402JR-0722RL | 3 | 0.00178 | 0.0053
47k-5% | R18, R19 | RES 47K OHM 1/16W 5% 0402 SMD | 311-47KJRCT-ND | R0402 | Yageo | RC0402JR-0747KL | 2 | 0.00178 | 0.0036
1k1-5% | R30 | RES 1.1K OHM 1/16W 5% 0402 SMD | 311-1.1KJRCT-ND | R0402 | Yageo | RC0402JR-071K1L | 1 | 0.00207 | 0.0021
SW-DPST | S1, S2 | Double-Pole, Single-Throw Switch |  | BUTTON-TVAF11-025B-R |  |  | 5 | 0.05 | 0.2500
GT1612 | U1 |  |  | GT1612 |  |  | 1 | 6 | 6.0000
XC6209B332MRN_SOT-25 | U2, U9 | XC6209B332MRN_SOT-25 |  | SOT23-5 |  |  | 2 | 0.1 | 0.2000
LEON G100 | U3 |  |  | U-BLOX-G100 |  |  | 1 | 12 | 12.0000
MX25L8005MC-15G_SOP-8L | U4 | MX25L8005MC-15G_SOP-8L |  | SO8-150mil |  |  | 1 | 0.4 | 0.4000
MMA7660FC | U5 | ACCELEROMETER 3X3 DGTL 10-DFN | MMA7660FCT-ND | MMA7660FC | Freescale Semiconductor | MMA7660FCT | 1 | 0.67000 | 0.6700
MKL25Z128VFT4 | U6 | IC ARM CORTEX MCU 128KB 48QFN | MKL25Z128VFT4-ND |  | Freescale Semiconductor | MKL25Z128VFT4 | 1 | 2.14920 | 2.1492
TPA6203A1_DRB_8 | U7 | IC AMP AUDIO PWR 1.25W MONO 8SON | 296-34561-5-ND | DRB8_1P75X1P5 | Texas Instruments | TPA6203A1DRB | 1 | 0.37248 | 0.3725
LCD |  |  |  |  |  |  | 1 | 3 | 3.0000
8.000 MHZ | Y1 | CRYSTAL 8.000 MHZ 18PF SMD | 887-1452-2-ND | SMD CRYSTAL 4 x 2.5 | TXC CORPORATION | 7B-8.000MAAJ-T | 1 | 0.39000 | 0.3900
 |  |  |  |  |  |  |  | PCBA | 1.2000
 |  |  |  |  |  |  |  | housing | 1.0000
 |  |  |  |  |  |  |  |  | 30.2625

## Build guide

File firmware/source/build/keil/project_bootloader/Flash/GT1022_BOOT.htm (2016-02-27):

# Static Call Graph for image .\Flash\GT1022_BOOT.axf

#<CALLGRAPH># ARM Linker, 5.03 [Build 76]: Last Updated: Sun Jul 13 23:26:10 2014

### Maximum Stack Usage = 128 bytes + Unknown(Cycles, Untraceable Function Pointers)

### Call chain for Maximum Stack Depth:

USB_EndPoint2 ⇒ MSC_BulkOut ⇒ MSC_MemoryWrite ⇒ SST25_Write ⇒ _SST25_Write ⇒ SST25__WriteEnable ⇒ SST25__Status ⇒ halSpiWriteByte

### Mutually Recursive functions

- NMI_Handler ⇒ NMI_Handler
- SVC_Handler ⇒ SVC_Handler
- PendSV_Handler ⇒ PendSV_Handler
- SysTick_Handler ⇒ SysTick_Handler
- ADC0_IRQHandler ⇒ ADC0_IRQHandler

### Function Pointers

- ADC0_IRQHandler from startup_mkl25z4.o(.text) referenced from startup_mkl25z4.o(RESET)
- CMP0_IRQHandler from startup_mkl25z4.o(.text) referenced from startup_mkl25z4.o(RESET)
- DAC0_IRQHandler from startup_mkl25z4.o(.text) referenced from startup_mkl25z4.o(RESET)
- DMA0_IRQHandler from startup_mkl25z4.o(.text) referenced from startup_mkl25z4.o(RESET)
- DMA1_IRQHandler from startup_mkl25z4.o(.text) referenced from startup_mkl25z4.o(RESET)
- DMA2_IRQHandler from startup_mkl25z4.o(.text) referenced from startup_mkl25z4.o(RESET)
- DMA3_IRQHandler from startup_mkl25z4.o(.text) referenced from startup_mkl25z4.o(RESET)
- FTFA_IRQHandler from startup_mkl25z4.o(.text) referenced from startup_mkl25z4.o(RESET)
- HardFault_Handler from project_bootloader.o(.text) referenced from startup_mkl25z4.o(RESET)
- I2C0_IRQHandler from startup_mkl25z4.o(.text) referenced from startup_mkl25z4.o(RESET)
- I2C1_IRQHandler from startup_mkl25z4.o(.text) referenced from startup_mkl25z4.o(RESET)
- LLW_IRQHandler from startup_mkl25z4.o(.text) referenced from startup_mkl25z4.o(RESET)
- LPTimer_IRQHandler from project_bootloader.o(.text) referenced from startup_mkl25z4.o(RESET)
- LVD_LVW_IRQHandler from startup_mkl25z4.o(.text) referenced from startup_mkl25z4.o(RESET)
- MCG_IRQHandler from startup_mkl25z4.o(.text) referenced from startup_mkl25z4.o(RESET)
- NMI_Handler from startup_mkl25z4.o(.text) referenced from startup_mkl25z4.o(RESET)
- PIT_IRQHandler from startup_mkl25z4.o(.text) referenced from startup_mkl25z4.o(RESET)
- PORTA_IRQHandler from startup_mkl25z4.o(.text) referenced from startup_mkl25z4.o(RESET)
- PORTD_IRQHandler from startup_mkl25z4.o(.text) referenced from startup_mkl25z4.o(RESET)
- PendSV_Handler from startup_mkl25z4.o(.text) referenced from startup_mkl25z4.o(RESET)
- RTC_IRQHandler from startup_mkl25z4.o(.text) referenced from startup_mkl25z4.o(RESET)
- RTC_Seconds_IRQHandler from startup_mkl25z4.o(.text) referenced from startup_mkl25z4.o(RESET)
- Reserved20_IRQHandler from startup_mkl25z4.o(.text) referenced from startup_mkl25z4.o(RESET)
- Reserved39_IRQHandler from startup_mkl25z4.o(.text) referenced from startup_mkl25z4.o(RESET)
- Reserved45_IRQHandler from startup_mkl25z4.o(.text) referenced from startup_mkl25z4.o(RESET)
- Reset_Handler from startup_mkl25z4.o(.text) referenced from startup_mkl25z4.o(RESET)
- SPI0_IRQHandler from startup_mkl25z4.o(.text) referenced from startup_mkl25z4.o(RESET)
- SPI1_IRQHandler from startup_mkl25z4.o(.text) referenced from startup_mkl25z4.o(RESET)
- SVC_Handler from startup_mkl25z4.o(.text) referenced from startup_mkl25z4.o(RESET)
- SysTick_Handler from startup_mkl25z4.o(.text) referenced from startup_mkl25z4.o(RESET)
- SystemInit from system_mkl25z4.o(.text) referenced from startup_mkl25z4.o(.text)
- TPM0_IRQHandler from startup_mkl25z4.o(.text) referenced from startup_mkl25z4.o(RESET)
- TPM1_IRQHandler from startup_mkl25z4.o(.text) referenced from startup_mkl25z4.o(RESET)
- TPM2_IRQHandler from startup_mkl25z4.o(.text) referenced from startup_mkl25z4.o(RESET)
- TSI0_IRQHandler from startup_mkl25z4.o(.text) referenced from startup_mkl25z4.o(RESET)
- UART0_IRQHandler from startup_mkl25z4.o(.text) referenced from startup_mkl25z4.o(RESET)
- UART1_IRQHandler from startup_mkl25z4.o(.text) referenced from startup_mkl25z4.o(RESET)
- UART2_IRQHandler from startup_mkl25z4.o(.text) referenced from startup_mkl25z4.o(RESET)
- USB0_IRQHandler from usbhw.o(.text) referenced from startup_mkl25z4.o(RESET)
- USB_EndPoint0 from usbcore.o(.text) referenced from usbuser.o(.constdata)
- USB_EndPoint1 from usbuser.o(.text) referenced from usbuser.o(.constdata)
- USB_EndPoint2 from usbuser.o(.text) referenced from usbuser.o(.constdata)
- USB_EndPoint3 from usbuser.o(.text) referenced from usbuser.o(.constdata)
- USB_EndPoint4 from usbuser.o(.text) referenced from usbuser.o(.constdata)
- USB_EndPoint5 from usbuser.o(.text) referenced from usbuser.o(.constdata)
- __main from entry.o(.ARM.Collect$$$$00000000) referenced from startup_mkl25z4.o(.text)
- main from project_bootloader.o(.text) referenced from entry9a.o(.ARM.Collect$$$$0000000B)

### Global Symbols

__main (Thumb, 0 bytes, Stack size unknown bytes, entry.o(.ARM.Collect$$$$00000000))
[Address Reference Count : 1]

- startup_mkl25z4.o(.text)

_main_stk (Thumb, 0 bytes, Stack size unknown bytes, entry2.o(.ARM.Collect$$$$00000001))

_main_scatterload (Thumb, 0 bytes, Stack size unknown bytes, entry5.o(.ARM.Collect$$$$00000004))

[Calls]

- >> __scatterload

__main_after_scatterload (Thumb, 0 bytes, Stack size unknown bytes, entry5.o(.ARM.Collect$$$$00000004))

[Called By]

- >> __scatterload

_main_clock (Thumb, 0 bytes, Stack size unknown bytes, entry7b.o(.ARM.Collect$$$$00000008))

_main_cpp_init (Thumb, 0 bytes, Stack size unknown bytes, entry8b.o(.ARM.Collect$$$$0000000A))

_main_init (Thumb, 0 bytes, Stack size unknown bytes, entry9a.o(.ARM.Collect$$$$0000000B))

__rt_final_cpp (Thumb, 0 bytes, Stack size unknown bytes, entry10a.o(.ARM.Collect$$$$0000000D))

__rt_final_exit (Thumb, 0 bytes, Stack size unknown bytes, entry11a.o(.ARM.Collect$$$$0000000F))

myFMC_Erase (Thumb, 24 bytes, Stack size 8 bytes, flashprog.o(.text))

[Stack]

- Max Depth = 24
- Call Chain = myFMC_Erase ⇒ Flash_SectorErase

[Calls]

- >> Flash_SectorErase
- >> NVIC_SystemReset

[Called By]

- >> main

FMC_ProgramPage (Thumb, 58 bytes, Stack size 16 bytes, flashprog.o(.text))

[Stack]

- Max Depth = 48
- Call Chain = FMC_ProgramPage ⇒ Flash_ByteProgram

[Calls]

- >> Flash_ByteProgram
- >> NVIC_SystemReset

[Called By]

- >> main

HardFault_Handler (Thumb, 4 bytes, Stack size 0 bytes, project_bootloader.o(.text))

[Calls]

- >> NVIC_SystemReset

[Address Reference Count : 1]

- startup_mkl25z4.o(RESET)

SetOutReport (Thumb, 8 bytes, Stack size 0 bytes, project_bootloader.o(.text))

[Called By]

- >> USB_EndPoint3
- >> HID_SetReport

GetInReport (Thumb, 2 bytes, Stack size 0 bytes, project_bootloader.o(.text))

[Called By]

- >> USB_EndPoint3
- >> USB_Configure_Event
- >> HID_GetReport

CfgCalcCheckSum (Thumb, 26 bytes, Stack size 8 bytes, project_bootloader.o(.text))

[Stack]

- Max Depth = 8
- Call Chain = CfgCalcCheckSum

[Called By]

- >> main

execute_user_code (Thumb, 72 bytes, Stack size 8 bytes, project_bootloader.o(.text))

[Stack]

- Max Depth = 8
- Call Chain = execute_user_code

[Calls]

- >> USB_Connect

[Called By]

- >> main

load_boot_code (Thumb, 40 bytes, Stack size 8 bytes, project_bootloader.o(.text), UNUSED)

LPTMR_init (Thumb, 72 bytes, Stack size 16 bytes, project_bootloader.o(.text))

[Stack]

- Max Depth = 24
- Call Chain = LPTMR_init ⇒ NVIC_SetPriority

[Calls]

- >> NVIC_SetPriority

[Called By]

- >> SysInit

LPTimerTask (Thumb, 86 bytes, Stack size 8 bytes, project_bootloader.o(.text))

[Stack]

- Max Depth = 8
- Call Chain = LPTimerTask

[Calls]

- >> NVIC_SystemReset

[Called By]

- >> LPTimer_IRQHandler

LPTimer_IRQHandler (Thumb, 8 bytes, Stack size 8 bytes, project_bootloader.o(.text))

[Stack]

- Max Depth = 16
- Call Chain = LPTimer_IRQHandler ⇒ LPTimerTask

[Calls]

- >> LPTimerTask

[Address Reference Count : 1]

- startup_mkl25z4.o(RESET)

SysInit (Thumb, 34 bytes, Stack size 8 bytes, project_bootloader.o(.text))

[Stack]

- Max Depth = 44
- Call Chain = SysInit ⇒ sysinit ⇒ __aeabi_idivmod ⇒ __aeabi_uidivmod

[Calls]

- >> sysinit
- >> USB_Init
- >> USB_Connect
- >> SST25_Init
- >> LPTMR_init

[Called By]

- >> main

Delay (Thumb, 12 bytes, Stack size 0 bytes, project_bootloader.o(.text), UNUSED)

main (Thumb, 846 bytes, Stack size 16 bytes, project_bootloader.o(.text))

[Stack]

- Max Depth = 64
- Call Chain = main ⇒ FMC_ProgramPage ⇒ Flash_ByteProgram

[Calls]

- >> VCOM_Serial2Usb
- >> VCOM_CheckSerialState
- >> USB_WriteEP
- >> USB_ReadEP
- >> RINGBUF_Init
- >> RINGBUF_Get
- >> Flash_Init
- >> SysInit
- >> execute_user_code
- >> CfgCalcCheckSum
- >> FMC_ProgramPage
- >> myFMC_Erase

[Address Reference Count : 1]

- entry9a.o(.ARM.Collect$$$$0000000B)

SystemInit (Thumb, 170 bytes, Stack size 0 bytes, system_mkl25z4.o(.text))
[Address Reference Count : 1]

- startup_mkl25z4.o(.text)

SystemCoreClockUpdate (Thumb, 310 bytes, Stack size 16 bytes, system_mkl25z4.o(.text), UNUSED)

[Calls]

- >> __ARM_common_switch8
- >> __aeabi_uidivmod

clk_out_init (Thumb, 22 bytes, Stack size 0 bytes, sysinit.o(.text))

[Called By]

- >> sysinit

sysinit (Thumb, 168 bytes, Stack size 8 bytes, sysinit.o(.text))

[Stack]

- Max Depth = 36
- Call Chain = sysinit ⇒ __aeabi_idivmod ⇒ __aeabi_uidivmod

[Calls]

- >> clk_out_init
- >> __aeabi_idivmod
- >> __aeabi_uidivmod

[Called By]

- >> SysInit

enable_abort_button (Thumb, 36 bytes, Stack size 0 bytes, sysinit.o(.text), UNUSED)

Reset_Handler (Thumb, 8 bytes, Stack size 0 bytes, startup_mkl25z4.o(.text))
[Address Reference Count : 1]

- startup_mkl25z4.o(RESET)

NMI_Handler (Thumb, 2 bytes, Stack size 0 bytes, startup_mkl25z4.o(.text))

[Calls]

- >> NMI_Handler

[Called By]

- >> NMI_Handler

[Address Reference Count : 1]

- startup_mkl25z4.o(RESET)

SVC_Handler (Thumb, 2 bytes, Stack size 0 bytes, startup_mkl25z4.o(.text))

[Calls]

- >> SVC_Handler

[Called By]

- >> SVC_Handler

[Address Reference Count : 1]

- startup_mkl25z4.o(RESET)

PendSV_Handler (Thumb, 2 bytes, Stack size 0 bytes, startup_mkl25z4.o(.text))

[Calls]

- >> PendSV_Handler

[Called By]

- >> PendSV_Handler

[Address Reference Count : 1]

- startup_mkl25z4.o(RESET)

SysTick_Handler (Thumb, 2 bytes, Stack size 0 bytes, startup_mkl25z4.o(.text))

[Calls]

- >> SysTick_Handler

[Called By]

- >> SysTick_Handler

[Address Reference Count : 1]

- startup_mkl25z4.o(RESET)

ADC0_IRQHandler (Thumb, 0 bytes, Stack size 0 bytes, startup_mkl25z4.o(.text))

[Calls]

- >> ADC0_IRQHandler

[Called By]

- >> ADC0_IRQHandler

[Address Reference Count : 1]

- startup_mkl25z4.o(RESET)

CMP0_IRQHandler (Thumb, 0 bytes, Stack size 0 bytes, startup_mkl25z4.o(.text))
[Address Reference Count : 1]

- startup_mkl25z4.o(RESET)

DAC0_IRQHandler (Thumb, 0 bytes, Stack size 0 bytes, startup_mkl25z4.o(.text))
[Address Reference Count : 1]

- startup_mkl25z4.o(RESET)

DMA0_IRQHandler (Thumb, 0 bytes, Stack size 0 bytes, startup_mkl25z4.o(.text))
[Address Reference Count : 1]

- startup_mkl25z4.o(RESET)

DMA1_IRQHandler (Thumb, 0 bytes, Stack size 0 bytes, startup_mkl25z4.o(.text))
[Address Reference Count : 1]

- startup_mkl25z4.o(RESET)

DMA2_IRQHandler (Thumb, 0 bytes, Stack size 0 bytes, startup_mkl25z4.o(.text))
[Address Reference Count : 1]

- startup_mkl25z4.o(RESET)

DMA3_IRQHandler (Thumb, 0 bytes, Stack size 0 bytes, startup_mkl25z4.o(.text))
[Address Reference Count : 1]

- startup_mkl25z4.o(RESET)

DefaultISR (Thumb, 0 bytes, Stack size 0 bytes, startup_mkl25z4.o(.text), UNUSED)

FTFA_IRQHandler (Thumb, 0 bytes, Stack size 0 bytes, startup_mkl25z4.o(.text))
[Address Reference Count : 1]

- startup_mkl25z4.o(RESET)

I2C0_IRQHandler (Thumb, 0 bytes, Stack size 0 bytes, startup_mkl25z4.o(.text))
[Address Reference Count : 1]

- startup_mkl25z4.o(RESET)

I2C1_IRQHandler (Thumb, 0 bytes, Stack size 0 bytes, startup_mkl25z4.o(.text))
[Address Reference Count : 1]

- startup_mkl25z4.o(RESET)

LLW_IRQHandler (Thumb, 0 bytes, Stack size 0 bytes, startup_mkl25z4.o(.text))
[Address Reference Count : 1]

- startup_mkl25z4.o(RESET)

LVD_LVW_IRQHandler (Thumb, 0 bytes, Stack size 0 bytes, startup_mkl25z4.o(.text))
[Address Reference Count : 1]

- startup_mkl25z4.o(RESET)

MCG_IRQHandler (Thumb, 0 bytes, Stack size 0 bytes, startup_mkl25z4.o(.text))
[Address Reference Count : 1]

- startup_mkl25z4.o(RESET)

PIT_IRQHandler (Thumb, 0 bytes, Stack size 0 bytes, startup_mkl25z4.o(.text))
[Address Reference Count : 1]

- startup_mkl25z4.o(RESET)

PORTA_IRQHandler (Thumb, 0 bytes, Stack size 0 bytes, startup_mkl25z4.o(.text))
[Address Reference Count : 1]

- startup_mkl25z4.o(RESET)

PORTD_IRQHandler (Thumb, 0 bytes, Stack size 0 bytes, startup_mkl25z4.o(.text))
[Address Reference Count : 1]

- startup_mkl25z4.o(RESET)

RTC_IRQHandler (Thumb, 0 bytes, Stack size 0 bytes, startup_mkl25z4.o(.text))
[Address Reference Count : 1]

- startup_mkl25z4.o(RESET)

RTC_Seconds_IRQHandler (Thumb, 0 bytes, Stack size 0 bytes, startup_mkl25z4.o(.text))
[Address Reference Count : 1]

- startup_mkl25z4.o(RESET)

Reserved20_IRQHandler (Thumb, 0 bytes, Stack size 0 bytes, startup_mkl25z4.o(.text))
[Address Reference Count : 1]

- startup_mkl25z4.o(RESET)

Reserved39_IRQHandler (Thumb, 0 bytes, Stack size 0 bytes, startup_mkl25z4.o(.text))
[Address Reference Count : 1]

- startup_mkl25z4.o(RESET)

Reserved45_IRQHandler (Thumb, 0 bytes, Stack size 0 bytes, startup_mkl25z4.o(.text))
[Address Reference Count : 1]

- startup_mkl25z4.o(RESET)

SPI0_IRQHandler (Thumb, 0 bytes, Stack size 0 bytes, startup_mkl25z4.o(.text))
[Address Reference Count : 1]

- startup_mkl25z4.o(RESET)

SPI1_IRQHandler (Thumb, 0 bytes, Stack size 0 bytes, startup_mkl25z4.o(.text))
[Address Reference Count : 1]

- startup_mkl25z4.o(RESET)

TPM0_IRQHandler (Thumb, 0 bytes, Stack size 0 bytes, startup_mkl25z4.o(.text))
[Address Reference Count : 1]

- startup_mkl25z4.o(RESET)

TPM1_IRQHandler (Thumb, 0 bytes, Stack size 0 bytes, startup_mkl25z4.o(.text))
[Address Reference Count : 1]

- startup_mkl25z4.o(RESET)

TPM2_IRQHandler (Thumb, 0 bytes, Stack size 0 bytes, startup_mkl25z4.o(.text))
[Address Reference Count : 1]

- startup_mkl25z4.o(RESET)

TSI0_IRQHandler (Thumb, 0 bytes, Stack size 0 bytes, startup_mkl25z4.o(.text))
[Address Reference Count : 1]

- startup_mkl25z4.o(RESET)

UART0_IRQHandler (Thumb, 0 bytes, Stack size 0 bytes, startup_mkl25z4.o(.text))
[Address Reference Count : 1]

- startup_mkl25z4.o(RESET)

UART1_IRQHandler (Thumb, 0 bytes, Stack size 0 bytes, startup_mkl25z4.o(.text))
[Address Reference Count : 1]

- startup_mkl25z4.o(RESET)

UART2_IRQHandler (Thumb, 0 bytes, Stack size 0 bytes, startup_mkl25z4.o(.text))
[Address Reference Count : 1]

- startup_mkl25z4.o(RESET)

SPI_Init (Thumb, 146 bytes, Stack size 0 bytes, spi.o(.text))

[Called By]

- >> SST25_Init

halSpiWriteByte (Thumb, 66 bytes, Stack size 8 bytes, spi.o(.text))

[Stack]

- Max Depth = 8
- Call Chain = halSpiWriteByte

[Called By]

- >> SST25_Read
- >> _SST25_Write
- >> SST25_Erase
- >> SST25__GlobalProtect
- >> SST25__WriteEnable
- >> SST25__Status

RINGBUF_Init (Thumb, 34 bytes, Stack size 0 bytes, ringbuf.o(.text))

[Called By]

- >> main

RINGBUF_Put (Thumb, 42 bytes, Stack size 8 bytes, ringbuf.o(.text))

[Stack]

- Max Depth = 8
- Call Chain = RINGBUF_Put

[Called By]

- >> CDC_BulkOut

RINGBUF_Get (Thumb, 46 bytes, Stack size 0 bytes, ringbuf.o(.text))

[Called By]

- >> CDC_BulkIn
- >> main

RINGBUF_GetFill (Thumb, 30 bytes, Stack size 0 bytes, ringbuf.o(.text), UNUSED)

Flash_Init (Thumb, 78 bytes, Stack size 0 bytes, flash_ftfa.o(.text))

[Called By]

- >> main

Flash_SectorErase (Thumb, 138 bytes, Stack size 16 bytes, flash_ftfa.o(.text))

[Stack]

- Max Depth = 16
- Call Chain = Flash_SectorErase

[Calls]

- >> SpSub (via Veneer)

[Called By]

- >> myFMC_Erase

Flash_ByteProgram (Thumb, 190 bytes, Stack size 32 bytes, flash_ftfa.o(.text))

[Stack]

- Max Depth = 32
- Call Chain = Flash_ByteProgram

[Calls]

- >> SpSub (via Veneer)

[Called By]

- >> FMC_ProgramPage

HID_GetReport (Thumb, 40 bytes, Stack size 8 bytes, hiduser.o(.text))

[Stack]

- Max Depth = 8
- Call Chain = HID_GetReport

[Calls]

- >> GetInReport

[Called By]

- >> USB_EndPoint0

HID_SetReport (Thumb, 40 bytes, Stack size 8 bytes, hiduser.o(.text))

[Stack]

- Max Depth = 8
- Call Chain = HID_SetReport

[Calls]

- >> SetOutReport

[Called By]

- >> USB_EndPoint0

HID_GetIdle (Thumb, 16 bytes, Stack size 0 bytes, hiduser.o(.text))

[Called By]

- >> USB_EndPoint0

HID_SetIdle (Thumb, 16 bytes, Stack size 0 bytes, hiduser.o(.text))

[Called By]

- >> USB_EndPoint0

HID_GetProtocol (Thumb, 12 bytes, Stack size 0 bytes, hiduser.o(.text))

[Called By]

- >> USB_EndPoint0

HID_SetProtocol (Thumb, 12 bytes, Stack size 0 bytes, hiduser.o(.text))

[Called By]

- >> USB_EndPoint0

USB_ResetCore (Thumb, 32 bytes, Stack size 0 bytes, usbcore.o(.text))

[Called By]

- >> USB_Suspend_Event
- >> USB_Reset_Event

USB_SetupStage (Thumb, 12 bytes, Stack size 8 bytes, usbcore.o(.text))

[Stack]

- Max Depth = 32
- Call Chain = USB_SetupStage ⇒ USB_ReadEP

[Calls]

- >> USB_ReadEP

[Called By]

- >> USB_EndPoint0

USB_DataInStage (Thumb, 52 bytes, Stack size 8 bytes, usbcore.o(.text))

[Stack]

- Max Depth = 28
- Call Chain = USB_DataInStage ⇒ USB_WriteEP

[Calls]

- >> USB_WriteEP

[Called By]

- >> USB_EndPoint0

USB_DataOutStage (Thumb, 34 bytes, Stack size 8 bytes, usbcore.o(.text))

[Stack]

- Max Depth = 32
- Call Chain = USB_DataOutStage ⇒ USB_ReadEP

[Calls]

- >> USB_ReadEP

[Called By]

- >> USB_EndPoint0

USB_StatusInStage (Thumb, 14 bytes, Stack size 8 bytes, usbcore.o(.text))

[Stack]

- Max Depth = 28
- Call Chain = USB_StatusInStage ⇒ USB_WriteEP

[Calls]

- >> USB_WriteEP

[Called By]

- >> USB_EndPoint0

USB_StatusOutStage (Thumb, 12 bytes, Stack size 8 bytes, usbcore.o(.text))

[Stack]

- Max Depth = 32
- Call Chain = USB_StatusOutStage ⇒ USB_ReadEP

[Calls]

- >> USB_ReadEP

[Called By]

- >> USB_EndPoint0

USB_EndPoint0 (Thumb, 1206 bytes, Stack size 8 bytes, usbcore.o(.text))

[Stack]

- Max Depth = 64
- Call Chain = USB_EndPoint0 ⇒ USB_ReqSetInterface ⇒ USB_ConfigEP

[Calls]

- >> USB_SetStallEP
- >> USB_SetAddress
- >> USB_DirCtrlEP
- >> USB_Configure_Event
- >> USB_ClrStallEP
- >> MSC_Reset
- >> MSC_GetMaxLUN
- >> CDC_SetLineCoding
- >> CDC_SetControlLineState
- >> CDC_SetCommFeature
- >> CDC_SendEncapsulatedCommand
- >> CDC_SendBreak
- >> CDC_GetLineCoding
- >> CDC_GetEncapsulatedResponse
- >> CDC_GetCommFeature
- >> CDC_ClearCommFeature
- >> USB_ReqSetInterface
- >> USB_ReqSetConfiguration
- >> USB_ReqSetClrFeature
- >> USB_ReqGetStatus
- >> USB_ReqGetDescriptor
- >> USB_StatusOutStage
- >> USB_StatusInStage
- >> USB_DataOutStage
- >> USB_DataInStage
- >> USB_SetupStage
- >> HID_SetProtocol
- >> HID_GetProtocol
- >> HID_SetIdle
- >> HID_GetIdle
- >> HID_SetReport
- >> HID_GetReport
- >> __ARM_common_switch8

[Address Reference Count : 1]

- usbuser.o(.constdata)

USB_IntrEna (Thumb, 24 bytes, Stack size 8 bytes, usbhw.o(.text))

[Stack]

- Max Depth = 16
- Call Chain = USB_IntrEna ⇒ NVIC_SetPriority

[Calls]

- >> NVIC_SetPriority

[Called By]

- >> USB_Init

USB_Init (Thumb, 168 bytes, Stack size 8 bytes, usbhw.o(.text))

[Stack]

- Max Depth = 24
- Call Chain = USB_Init ⇒ USB_IntrEna ⇒ NVIC_SetPriority

[Calls]

- >> USB_IntrEna

[Called By]

- >> SysInit

USB_Connect (Thumb, 58 bytes, Stack size 0 bytes, usbhw.o(.text))

[Called By]

- >> SysInit
- >> execute_user_code

USB_Reset (Thumb, 94 bytes, Stack size 0 bytes, usbhw.o(.text))

[Called By]

- >> USB0_IRQHandler

USB_Suspend (Thumb, 18 bytes, Stack size 0 bytes, usbhw.o(.text))

[Called By]

- >> USB0_IRQHandler

USB_Resume (Thumb, 18 bytes, Stack size 0 bytes, usbhw.o(.text))

[Called By]

- >> USB0_IRQHandler

USB_WakeUp (Thumb, 58 bytes, Stack size 0 bytes, usbhw.o(.text), UNUSED)

USB_WakeUpCfg (Thumb, 2 bytes, Stack size 0 bytes, usbhw.o(.text))

[Called By]

- >> USB_ReqSetClrFeature

USB_SetAddress (Thumb, 12 bytes, Stack size 0 bytes, usbhw.o(.text))

[Called By]

- >> USB_EndPoint0

USB_Configure (Thumb, 2 bytes, Stack size 0 bytes, usbhw.o(.text))

[Called By]

- >> USB_ReqSetConfiguration

USB_ResetEP (Thumb, 140 bytes, Stack size 0 bytes, usbhw.o(.text))

[Called By]

- >> USB_ConfigEP
- >> USB_ClrStallEP
- >> USB_ReqSetInterface
- >> USB_ReqSetConfiguration

USB_ConfigEP (Thumb, 36 bytes, Stack size 16 bytes, usbhw.o(.text))

[Stack]

- Max Depth = 16
- Call Chain = USB_ConfigEP

[Calls]

- >> USB_ResetEP

[Called By]

- >> USB_ReqSetInterface
- >> USB_ReqSetConfiguration

USB_DirCtrlEP (Thumb, 2 bytes, Stack size 0 bytes, usbhw.o(.text))

[Called By]

- >> USB_EndPoint0

USB_EnableEP (Thumb, 54 bytes, Stack size 0 bytes, usbhw.o(.text))

[Called By]

- >> USB_ReqSetInterface
- >> USB_ReqSetConfiguration

USB_DisableEP (Thumb, 54 bytes, Stack size 0 bytes, usbhw.o(.text))

[Called By]

- >> USB_ReqSetInterface
- >> USB_ReqSetConfiguration

USB_SetStallEP (Thumb, 26 bytes, Stack size 0 bytes, usbhw.o(.text))

[Called By]

- >> MSC_GetCBW
- >> MSC_TestUnitReady
- >> DataInFormat
- >> MSC_RWSetup
- >> MSC_MemoryVerify
- >> MSC_MemoryWrite
- >> MSC_BulkOut
- >> MSC_BulkIn
- >> USB_ReqSetClrFeature
- >> USB_EndPoint0

USB_ClrStallEP (Thumb, 36 bytes, Stack size 8 bytes, usbhw.o(.text))

[Stack]

- Max Depth = 8
- Call Chain = USB_ClrStallEP

[Calls]

- >> USB_ResetEP

[Called By]

- >> USB_ReqSetClrFeature
- >> USB_EndPoint0

USB_ClearEPBuf (Thumb, 2 bytes, Stack size 0 bytes, usbhw.o(.text), UNUSED)

USB_ReadEP (Thumb, 260 bytes, Stack size 24 bytes, usbhw.o(.text))

[Stack]

- Max Depth = 24
- Call Chain = USB_ReadEP

[Called By]

- >> MSC_BulkOut
- >> CDC_BulkOut
- >> USB_StatusOutStage
- >> USB_DataOutStage
- >> USB_SetupStage
- >> main

USB_WriteEP (Thumb, 94 bytes, Stack size 20 bytes, usbhw.o(.text))

[Stack]

- Max Depth = 20
- Call Chain = USB_WriteEP

[Called By]

- >> DataInTransfer
- >> MSC_SetCSW
- >> MSC_MemoryRead
- >> CDC_NotificationIn
- >> CDC_BulkIn
- >> USB_ReqSetClrFeature
- >> USB_StatusInStage
- >> USB_DataInStage
- >> VCOM_Serial2Usb
- >> main

USB_GetFrame (Thumb, 16 bytes, Stack size 0 bytes, usbhw.o(.text), UNUSED)

USB0_IRQHandler (Thumb, 350 bytes, Stack size 24 bytes, usbhw.o(.text))

[Stack]

- Max Depth = 32
- Call Chain = USB0_IRQHandler ⇒ USB_Reset_Event

[Calls]

- >> USB_Resume_Event
- >> USB_Reset_Event
- >> USB_Resume
- >> USB_Suspend
- >> USB_Reset

[Address Reference Count : 1]

- startup_mkl25z4.o(RESET)

USB_Reset_Event (Thumb, 8 bytes, Stack size 8 bytes, usbuser.o(.text))

[Stack]

- Max Depth = 8
- Call Chain = USB_Reset_Event

[Calls]

- >> USB_ResetCore

[Called By]

- >> USB0_IRQHandler

USB_Suspend_Event (Thumb, 8 bytes, Stack size 8 bytes, usbuser.o(.text), UNUSED)

[Calls]

- >> USB_ResetCore

USB_Resume_Event (Thumb, 2 bytes, Stack size 0 bytes, usbuser.o(.text))

[Called By]

- >> USB0_IRQHandler

USB_Configure_Event (Thumb, 16 bytes, Stack size 8 bytes, usbuser.o(.text))

[Stack]

- Max Depth = 8
- Call Chain = USB_Configure_Event

[Calls]

- >> GetInReport

[Called By]

- >> USB_EndPoint0

USB_EndPoint3 (Thumb, 30 bytes, Stack size 8 bytes, usbuser.o(.text))

[Stack]

- Max Depth = 8
- Call Chain = USB_EndPoint3

[Calls]

- >> GetInReport
- >> SetOutReport

[Address Reference Count : 1]

- usbuser.o(.constdata)

USB_EndPoint2 (Thumb, 30 bytes, Stack size 8 bytes, usbuser.o(.text))

[Stack]

- Max Depth = 128
- Call Chain = USB_EndPoint2 ⇒ MSC_BulkOut ⇒ MSC_MemoryWrite ⇒ SST25_Write ⇒ _SST25_Write ⇒ SST25__WriteEnable ⇒ SST25__Status ⇒ halSpiWriteByte

[Calls]

- >> MSC_BulkOut
- >> MSC_BulkIn

[Address Reference Count : 1]

- usbuser.o(.constdata)

USB_EndPoint1 (Thumb, 36 bytes, Stack size 16 bytes, usbuser.o(.text))

[Stack]

- Max Depth = 44
- Call Chain = USB_EndPoint1 ⇒ CDC_NotificationIn ⇒ USB_WriteEP

[Calls]

- >> CDC_NotificationIn
- >> CDC_GetSerialState

[Address Reference Count : 1]

- usbuser.o(.constdata)

USB_EndPoint4 (Thumb, 30 bytes, Stack size 8 bytes, usbuser.o(.text))

[Stack]

- Max Depth = 128
- Call Chain = USB_EndPoint4 ⇒ MSC_BulkOut ⇒ MSC_MemoryWrite ⇒ SST25_Write ⇒ _SST25_Write ⇒ SST25__WriteEnable ⇒ SST25__Status ⇒ halSpiWriteByte

[Calls]

- >> MSC_BulkOut
- >> MSC_BulkIn

[Address Reference Count : 1]

- usbuser.o(.constdata)

USB_EndPoint5 (Thumb, 30 bytes, Stack size 8 bytes, usbuser.o(.text))

[Stack]

- Max Depth = 48
- Call Chain = USB_EndPoint5 ⇒ CDC_BulkOut ⇒ USB_ReadEP

[Calls]

- >> CDC_BulkOut
- >> CDC_BulkIn

[Address Reference Count : 1]

- usbuser.o(.constdata)

MSC_Reset (Thumb, 10 bytes, Stack size 0 bytes, mscuser.o(.text))

[Called By]

- >> USB_EndPoint0

MSC_GetMaxLUN (Thumb, 10 bytes, Stack size 0 bytes, mscuser.o(.text))

[Called By]

- >> USB_EndPoint0

MSC_MemoryRead (Thumb, 184 bytes, Stack size 8 bytes, mscuser.o(.text))

[Stack]

- Max Depth = 48
- Call Chain = MSC_MemoryRead ⇒ SST25_Read ⇒ SST25__Status ⇒ halSpiWriteByte

[Calls]

- >> SST25_Read
- >> USB_WriteEP
- >> __aeabi_uwrite4
- >> __aeabi_uread4

[Called By]

- >> MSC_GetCBW
- >> MSC_BulkIn

MSC_SetCSW (Thumb, 32 bytes, Stack size 8 bytes, mscuser.o(.text))

[Stack]

- Max Depth = 28
- Call Chain = MSC_SetCSW ⇒ USB_WriteEP

[Calls]

- >> USB_WriteEP
- >> __aeabi_uwrite4

[Called By]

- >> MSC_GetCBW
- >> MSC_TestUnitReady
- >> DataInFormat
- >> MSC_RWSetup
- >> MSC_MemoryVerify
- >> MSC_MemoryWrite
- >> MSC_BulkOut
- >> MSC_BulkIn

MSC_MemoryWrite (Thumb, 580 bytes, Stack size 24 bytes, mscuser.o(.text))

[Stack]

- Max Depth = 112
- Call Chain = MSC_MemoryWrite ⇒ SST25_Write ⇒ _SST25_Write ⇒ SST25__WriteEnable ⇒ SST25__Status ⇒ halSpiWriteByte

[Calls]

- >> SST25_Write
- >> SST25_Read
- >> MSC_SetCSW
- >> USB_SetStallEP
- >> __aeabi_uwrite4
- >> __aeabi_uread4

[Called By]

- >> MSC_BulkOut

MSC_MemoryVerify (Thumb, 160 bytes, Stack size 16 bytes, mscuser.o(.text))

[Stack]

- Max Depth = 44
- Call Chain = MSC_MemoryVerify ⇒ MSC_SetCSW ⇒ USB_WriteEP

[Calls]

- >> MSC_SetCSW
- >> USB_SetStallEP
- >> __aeabi_uwrite4
- >> __aeabi_uread4

[Called By]

- >> MSC_BulkOut

MSC_RWSetup (Thumb, 192 bytes, Stack size 8 bytes, mscuser.o(.text))

[Stack]

- Max Depth = 36
- Call Chain = MSC_RWSetup ⇒ MSC_SetCSW ⇒ USB_WriteEP

[Calls]

- >> MSC_SetCSW
- >> USB_SetStallEP
- >> __aeabi_uread4

[Called By]

- >> MSC_GetCBW

DataInFormat (Thumb, 62 bytes, Stack size 8 bytes, mscuser.o(.text))

[Stack]

- Max Depth = 36
- Call Chain = DataInFormat ⇒ MSC_SetCSW ⇒ USB_WriteEP

[Calls]

- >> MSC_SetCSW
- >> USB_SetStallEP
- >> __aeabi_uread4

[Called By]

- >> MSC_ReadFormatCapacity
- >> MSC_ReadCapacity
- >> MSC_ModeSense10
- >> MSC_ModeSense6
- >> MSC_Inquiry
- >> MSC_RequestSense

DataInTransfer (Thumb, 76 bytes, Stack size 8 bytes, mscuser.o(.text))

[Stack]

- Max Depth = 28
- Call Chain = DataInTransfer ⇒ USB_WriteEP

[Calls]

- >> USB_WriteEP
- >> __aeabi_uwrite4
- >> __aeabi_uread4

[Called By]

- >> MSC_ReadFormatCapacity
- >> MSC_ReadCapacity
- >> MSC_ModeSense10
- >> MSC_ModeSense6
- >> MSC_Inquiry
- >> MSC_RequestSense

MSC_TestUnitReady (Thumb, 50 bytes, Stack size 8 bytes, mscuser.o(.text))

[Stack]

- Max Depth = 36
- Call Chain = MSC_TestUnitReady ⇒ MSC_SetCSW ⇒ USB_WriteEP

[Calls]

- >> MSC_SetCSW
- >> USB_SetStallEP
- >> __aeabi_uread4

[Called By]

- >> MSC_GetCBW

MSC_RequestSense (Thumb, 80 bytes, Stack size 8 bytes, mscuser.o(.text))

[Stack]

- Max Depth = 44
- Call Chain = MSC_RequestSense ⇒ DataInFormat ⇒ MSC_SetCSW ⇒ USB_WriteEP

[Calls]

- >> DataInTransfer
- >> DataInFormat

[Called By]

- >> MSC_GetCBW

MSC_Inquiry (Thumb, 164 bytes, Stack size 8 bytes, mscuser.o(.text))

[Stack]

- Max Depth = 44
- Call Chain = MSC_Inquiry ⇒ DataInFormat ⇒ MSC_SetCSW ⇒ USB_WriteEP

[Calls]

- >> DataInTransfer
- >> DataInFormat

[Called By]

- >> MSC_GetCBW

MSC_ModeSense6 (Thumb, 40 bytes, Stack size 8 bytes, mscuser.o(.text))

[Stack]

- Max Depth = 44
- Call Chain = MSC_ModeSense6 ⇒ DataInFormat ⇒ MSC_SetCSW ⇒ USB_WriteEP

[Calls]

- >> DataInTransfer
- >> DataInFormat

[Called By]

- >> MSC_GetCBW

MSC_ModeSense10 (Thumb, 50 bytes, Stack size 8 bytes, mscuser.o(.text))

[Stack]

- Max Depth = 44
- Call Chain = MSC_ModeSense10 ⇒ DataInFormat ⇒ MSC_SetCSW ⇒ USB_WriteEP

[Calls]

- >> DataInTransfer
- >> DataInFormat

[Called By]

- >> MSC_GetCBW

MSC_ReadCapacity (Thumb, 56 bytes, Stack size 8 bytes, mscuser.o(.text))

[Stack]

- Max Depth = 44
- Call Chain = MSC_ReadCapacity ⇒ DataInFormat ⇒ MSC_SetCSW ⇒ USB_WriteEP

[Calls]

- >> DataInTransfer
- >> DataInFormat

[Called By]

- >> MSC_GetCBW

MSC_ReadFormatCapacity (Thumb, 94 bytes, Stack size 8 bytes, mscuser.o(.text))

[Stack]

- Max Depth = 44
- Call Chain = MSC_ReadFormatCapacity ⇒ DataInFormat ⇒ MSC_SetCSW ⇒ USB_WriteEP

[Calls]

- >> DataInTransfer
- >> DataInFormat

[Called By]

- >> MSC_GetCBW

MSC_GetCBW (Thumb, 462 bytes, Stack size 16 bytes, mscuser.o(.text))

[Stack]

- Max Depth = 64
- Call Chain = MSC_GetCBW ⇒ MSC_MemoryRead ⇒ SST25_Read ⇒ SST25__Status ⇒ halSpiWriteByte

[Calls]

- >> MSC_ReadFormatCapacity
- >> MSC_ReadCapacity
- >> MSC_ModeSense10
- >> MSC_ModeSense6
- >> MSC_Inquiry
- >> MSC_RequestSense
- >> MSC_TestUnitReady
- >> MSC_RWSetup
- >> MSC_SetCSW
- >> MSC_MemoryRead
- >> USB_SetStallEP
- >> __aeabi_uwrite4
- >> __aeabi_uread4

[Called By]

- >> MSC_BulkOut

MSC_BulkIn (Thumb, 72 bytes, Stack size 8 bytes, mscuser.o(.text))

[Stack]

- Max Depth = 56
- Call Chain = MSC_BulkIn ⇒ MSC_MemoryRead ⇒ SST25_Read ⇒ SST25__Status ⇒ halSpiWriteByte

[Calls]

- >> MSC_SetCSW
- >> MSC_MemoryRead
- >> USB_SetStallEP

[Called By]

- >> USB_EndPoint4
- >> USB_EndPoint2

MSC_BulkOut (Thumb, 86 bytes, Stack size 8 bytes, mscuser.o(.text))

[Stack]

- Max Depth = 120
- Call Chain = MSC_BulkOut ⇒ MSC_MemoryWrite ⇒ SST25_Write ⇒ _SST25_Write ⇒ SST25__WriteEnable ⇒ SST25__Status ⇒ halSpiWriteByte

[Calls]

- >> MSC_GetCBW
- >> MSC_MemoryVerify
- >> MSC_MemoryWrite
- >> MSC_SetCSW
- >> USB_SetStallEP
- >> USB_ReadEP

[Called By]

- >> USB_EndPoint4
- >> USB_EndPoint2

CDC_RdOutBuf (Thumb, 58 bytes, Stack size 16 bytes, cdcuser.o(.text), UNUSED)

[Called By]

- >> VCOM_Usb2Serial

CDC_WrOutBuf (Thumb, 44 bytes, Stack size 20 bytes, cdcuser.o(.text), UNUSED)

CDC_OutBufAvailChar (Thumb, 22 bytes, Stack size 0 bytes, cdcuser.o(.text), UNUSED)

[Called By]

- >> VCOM_Usb2Serial

CDC_GetSerialState (Thumb, 146 bytes, Stack size 0 bytes, cdcuser.o(.text))

[Called By]

- >> CDC_Init
- >> USB_EndPoint1
- >> VCOM_CheckSerialState

CDC_Init (Thumb, 28 bytes, Stack size 4 bytes, cdcuser.o(.text), UNUSED)

[Calls]

- >> CDC_GetSerialState

CDC_SendEncapsulatedCommand (Thumb, 4 bytes, Stack size 0 bytes, cdcuser.o(.text))

[Called By]

- >> USB_EndPoint0

CDC_GetEncapsulatedResponse (Thumb, 4 bytes, Stack size 0 bytes, cdcuser.o(.text))

[Called By]

- >> USB_EndPoint0

CDC_SetCommFeature (Thumb, 6 bytes, Stack size 0 bytes, cdcuser.o(.text))

[Called By]

- >> USB_EndPoint0

CDC_GetCommFeature (Thumb, 6 bytes, Stack size 0 bytes, cdcuser.o(.text))

[Called By]

- >> USB_EndPoint0

CDC_ClearCommFeature (Thumb, 6 bytes, Stack size 0 bytes, cdcuser.o(.text))

[Called By]

- >> USB_EndPoint0

CDC_SetLineCoding (Thumb, 116 bytes, Stack size 8 bytes, cdcuser.o(.text))

[Stack]

- Max Depth = 8
- Call Chain = CDC_SetLineCoding

[Calls]

- >> __aeabi_uwrite4

[Called By]

- >> USB_EndPoint0

CDC_GetLineCoding (Thumb, 74 bytes, Stack size 8 bytes, cdcuser.o(.text))

[Stack]

- Max Depth = 8
- Call Chain = CDC_GetLineCoding

[Calls]

- >> __aeabi_uread4

[Called By]

- >> USB_EndPoint0

CDC_SetControlLineState (Thumb, 6 bytes, Stack size 0 bytes, cdcuser.o(.text))

[Called By]

- >> USB_EndPoint0

CDC_SendBreak (Thumb, 6 bytes, Stack size 0 bytes, cdcuser.o(.text))

[Called By]

- >> USB_EndPoint0

CDC_BulkIn (Thumb, 60 bytes, Stack size 16 bytes, cdcuser.o(.text))

[Stack]

- Max Depth = 36
- Call Chain = CDC_BulkIn ⇒ USB_WriteEP

[Calls]

- >> USB_WriteEP
- >> RINGBUF_Get

[Called By]

- >> USB_EndPoint5

CDC_BulkOut (Thumb, 34 bytes, Stack size 16 bytes, cdcuser.o(.text))

[Stack]

- Max Depth = 40
- Call Chain = CDC_BulkOut ⇒ USB_ReadEP

[Calls]

- >> RINGBUF_Put
- >> USB_ReadEP

[Called By]

- >> USB_EndPoint5

CDC_NotificationIn (Thumb, 54 bytes, Stack size 8 bytes, cdcuser.o(.text))

[Stack]

- Max Depth = 28
- Call Chain = CDC_NotificationIn ⇒ USB_WriteEP

[Calls]

- >> USB_WriteEP

[Called By]

- >> USB_EndPoint1
- >> VCOM_CheckSerialState

VCOM_Serial2Usb (Thumb, 30 bytes, Stack size 8 bytes, cdcuser.o(.text))

[Stack]

- Max Depth = 28
- Call Chain = VCOM_Serial2Usb ⇒ USB_WriteEP

[Calls]

- >> USB_WriteEP

[Called By]

- >> main

VCOM_Usb2Serial (Thumb, 48 bytes, Stack size 20 bytes, cdcuser.o(.text), UNUSED)

[Calls]

- >> CDC_OutBufAvailChar
- >> CDC_RdOutBuf

VCOM_CheckSerialState (Thumb, 26 bytes, Stack size 8 bytes, cdcuser.o(.text))

[Stack]

- Max Depth = 36
- Call Chain = VCOM_CheckSerialState ⇒ CDC_NotificationIn ⇒ USB_WriteEP

[Calls]

- >> CDC_NotificationIn
- >> CDC_GetSerialState

[Called By]

- >> main

SST25_Init (Thumb, 10 bytes, Stack size 8 bytes, sst25.o(.text))

[Stack]

- Max Depth = 8
- Call Chain = SST25_Init

[Calls]

- >> SPI_Init

[Called By]

- >> SysInit

SST25_Erase (Thumb, 126 bytes, Stack size 16 bytes, sst25.o(.text))

[Stack]

- Max Depth = 48
- Call Chain = SST25_Erase ⇒ SST25__WriteEnable ⇒ SST25__Status ⇒ halSpiWriteByte

[Calls]

- >> halSpiWriteByte
- >> SST25__WriteEnable

[Called By]

- >> SST25_Write

_SST25_Write (Thumb, 128 bytes, Stack size 32 bytes, sst25.o(.text))

[Stack]

- Max Depth = 64
- Call Chain = _SST25_Write ⇒ SST25__WriteEnable ⇒ SST25__Status ⇒ halSpiWriteByte

[Calls]

- >> halSpiWriteByte
- >> SST25__WriteEnable
- >> SST25__Status

[Called By]

- >> SST25_Write

SST25_Write (Thumb, 82 bytes, Stack size 24 bytes, sst25.o(.text))

[Stack]

- Max Depth = 88
- Call Chain = SST25_Write ⇒ _SST25_Write ⇒ SST25__WriteEnable ⇒ SST25__Status ⇒ halSpiWriteByte

[Calls]

- >> _SST25_Write
- >> SST25_Erase

[Called By]

- >> MSC_MemoryWrite

SST25_Read (Thumb, 112 bytes, Stack size 24 bytes, sst25.o(.text))

[Stack]

- Max Depth = 40
- Call Chain = SST25_Read ⇒ SST25__Status ⇒ halSpiWriteByte

[Calls]

- >> halSpiWriteByte
- >> SST25__Status

[Called By]

- >> MSC_MemoryWrite
- >> MSC_MemoryRead

__aeabi_uidiv (Thumb, 0 bytes, Stack size 12 bytes, uidiv.o(.text), UNUSED)

__aeabi_uidivmod (Thumb, 44 bytes, Stack size 12 bytes, uidiv.o(.text))

[Stack]

- Max Depth = 12
- Call Chain = __aeabi_uidivmod

[Called By]

- >> SystemCoreClockUpdate
- >> sysinit
- >> __aeabi_idivmod

__aeabi_idiv (Thumb, 0 bytes, Stack size 16 bytes, idiv.o(.text), UNUSED)

__aeabi_idivmod (Thumb, 40 bytes, Stack size 16 bytes, idiv.o(.text))

[Stack]

- Max Depth = 28
- Call Chain = __aeabi_idivmod ⇒ __aeabi_uidivmod

[Calls]

- >> __aeabi_uidivmod

[Called By]

- >> sysinit

__aeabi_uread4 (Thumb, 20 bytes, Stack size 0 bytes, uread4.o(.text))

[Called By]

- >> MSC_GetCBW
- >> MSC_TestUnitReady
- >> DataInTransfer
- >> DataInFormat
- >> MSC_RWSetup
- >> MSC_MemoryVerify
- >> MSC_MemoryWrite
- >> MSC_MemoryRead
- >> CDC_GetLineCoding
- >> USB_ReqSetClrFeature

__rt_uread4 (Thumb, 0 bytes, Stack size 0 bytes, uread4.o(.text), UNUSED)

_uread4 (Thumb, 0 bytes, Stack size 0 bytes, uread4.o(.text), UNUSED)

__aeabi_uwrite4 (Thumb, 18 bytes, Stack size 0 bytes, uwrite4.o(.text))

[Called By]

- >> MSC_GetCBW
- >> DataInTransfer
- >> MSC_MemoryVerify
- >> MSC_MemoryWrite
- >> MSC_SetCSW
- >> MSC_MemoryRead
- >> CDC_SetLineCoding

__rt_uwrite4 (Thumb, 0 bytes, Stack size 0 bytes, uwrite4.o(.text), UNUSED)

_uwrite4 (Thumb, 0 bytes, Stack size 0 bytes, uwrite4.o(.text), UNUSED)

__scatterload (Thumb, 28 bytes, Stack size 0 bytes, init.o(.text))

[Calls]

- >> __main_after_scatterload

[Called By]

- >> _main_scatterload

__scatterload_rt2 (Thumb, 0 bytes, Stack size 0 bytes, init.o(.text), UNUSED)

USB_ReqGetDescriptor (Thumb, 252 bytes, Stack size 8 bytes, usbcore.o(i.USB_ReqGetDescriptor))

[Stack]

- Max Depth = 8
- Call Chain = USB_ReqGetDescriptor

[Called By]

- >> USB_EndPoint0

USB_ReqGetStatus (Thumb, 164 bytes, Stack size 0 bytes, usbcore.o(i.USB_ReqGetStatus))

[Called By]

- >> USB_EndPoint0

USB_ReqSetClrFeature (Thumb, 250 bytes, Stack size 16 bytes, usbcore.o(i.USB_ReqSetClrFeature))

[Stack]

- Max Depth = 36
- Call Chain = USB_ReqSetClrFeature ⇒ USB_WriteEP

[Calls]

- >> USB_WakeUpCfg
- >> USB_SetStallEP
- >> USB_ClrStallEP
- >> USB_WriteEP
- >> __aeabi_uread4

[Called By]

- >> USB_EndPoint0

USB_ReqSetConfiguration (Thumb, 402 bytes, Stack size 24 bytes, usbcore.o(i.USB_ReqSetConfiguration))

[Stack]

- Max Depth = 40
- Call Chain = USB_ReqSetConfiguration ⇒ USB_ConfigEP

[Calls]

- >> USB_ResetEP
- >> USB_EnableEP
- >> USB_DisableEP
- >> USB_Configure
- >> USB_ConfigEP

[Called By]

- >> USB_EndPoint0

USB_ReqSetInterface (Thumb, 296 bytes, Stack size 40 bytes, usbcore.o(i.USB_ReqSetInterface))

[Stack]

- Max Depth = 56
- Call Chain = USB_ReqSetInterface ⇒ USB_ConfigEP

[Calls]

- >> USB_ResetEP
- >> USB_EnableEP
- >> USB_DisableEP
- >> USB_ConfigEP

[Called By]

- >> USB_EndPoint0

__ARM_common_switch8 (Thumb, 28 bytes, Stack size 8 bytes, system_mkl25z4.o(i.__ARM_common_switch8))

[Stack]

- Max Depth = 8
- Call Chain = __ARM_common_switch8

[Called By]

- >> USB_EndPoint0
- >> SystemCoreClockUpdate

__scatterload_copy (Thumb, 14 bytes, Stack size unknown bytes, handlers.o(i.__scatterload_copy), UNUSED)

__scatterload_null (Thumb, 2 bytes, Stack size unknown bytes, handlers.o(i.__scatterload_null), UNUSED)

__scatterload_zeroinit (Thumb, 14 bytes, Stack size unknown bytes, handlers.o(i.__scatterload_zeroinit), UNUSED)

SpSub (Thumb, 26 bytes, Stack size 0 bytes, flash_ramfunc.o(.text))

[Called By]

- >> Flash_SectorErase (via Veneer)
- >> Flash_ByteProgram (via Veneer)

### Local Symbols

NVIC_SystemReset (Thumb, 18 bytes, Stack size 0 bytes, flashprog.o(.text))

[Called By]

- >> FMC_ProgramPage
- >> myFMC_Erase

NVIC_SetPriority (Thumb, 110 bytes, Stack size 8 bytes, project_bootloader.o(.text))

[Stack]

- Max Depth = 8
- Call Chain = NVIC_SetPriority

[Called By]

- >> LPTMR_init

NVIC_SystemReset (Thumb, 20 bytes, Stack size 0 bytes, project_bootloader.o(.text))

[Called By]

- >> LPTimerTask
- >> HardFault_Handler

NVIC_SetPriority (Thumb, 110 bytes, Stack size 8 bytes, usbhw.o(.text))

[Stack]

- Max Depth = 8
- Call Chain = NVIC_SetPriority

[Called By]

- >> USB_IntrEna

SST25__Status (Thumb, 44 bytes, Stack size 8 bytes, sst25.o(.text))

[Stack]

- Max Depth = 16
- Call Chain = SST25__Status ⇒ halSpiWriteByte

[Calls]

- >> halSpiWriteByte

[Called By]

- >> SST25_Read
- >> _SST25_Write
- >> SST25__GlobalProtect
- >> SST25__WriteEnable

SST25__WriteEnable (Thumb, 88 bytes, Stack size 16 bytes, sst25.o(.text))

[Stack]

- Max Depth = 32
- Call Chain = SST25__WriteEnable ⇒ SST25__Status ⇒ halSpiWriteByte

[Calls]

- >> halSpiWriteByte
- >> SST25__Status

[Called By]

- >> _SST25_Write
- >> SST25_Erase

SST25__GlobalProtect (Thumb, 106 bytes, Stack size 16 bytes, sst25.o(.text), UNUSED)

[Calls]

- >> halSpiWriteByte
- >> SST25__Status

### Undefined Global Symbols

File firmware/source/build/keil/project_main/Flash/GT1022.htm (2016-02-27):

# Static Call Graph for image .\Flash\GT1022.axf

#<CALLGRAPH># ARM Linker, 5.03 [Build 76]: Last Updated: Sat Feb 27 15:37:38 2016

### Maximum Stack Usage = 776 bytes + Unknown(Cycles, Untraceable Function Pointers)

### Call chain for Maximum Stack Depth:

main ⇒ AppRun ⇒ SysSleep ⇒ TrackerTask ⇒ PedometerTask ⇒ ambo_step_detect ⇒ b2_filter

### Mutually Recursive functions

- UploadConfigTask_WaitRetry ⇒ GprsTask_Stop
- UploadConfigTask_Retry ⇒ GprsTask_Stop
- UploadConfig_Task ⇒ GprsTask_Stop
- SendPowerCmdTask_Retry ⇒ GprsTask_Stop
- SendPowerCmd_GprsTask ⇒ GprsTask_Stop
- SendGpsDataTask_Retry ⇒ GprsTask_Stop
- SendGpsData_GprsTask ⇒ GprsTask_Stop
- Gprs_Task ⇒ GprsTask_Stop
- SVC_Handler ⇒ SVC_Handler
- PendSV_Handler ⇒ PendSV_Handler
- ADC0_IRQHandler ⇒ ADC0_IRQHandler

### Function Pointers

- ADC0_IRQHandler from startup_mkl25z4.o(.text) referenced from startup_mkl25z4.o(RESET)
- CMP0_IRQHandler from startup_mkl25z4.o(.text) referenced from startup_mkl25z4.o(RESET)
- CallBusy from at_command_parser.o(.text) referenced from at_command_parser.o(.constdata)
- CallCancel from at_command_parser.o(.text) referenced from at_command_parser.o(.constdata)
- CallErrorReport from at_command_parser.o(.text) referenced from at_command_parser.o(.constdata)
- CallNoAnswer from at_command_parser.o(.text) referenced from at_command_parser.o(.constdata)
- CallOutProcess from at_command_parser.o(.text) referenced from at_command_parser.o(.constdata)
- CellLocateParser from at_command_parser.o(.text) referenced from at_command_parser.o(.constdata)
- DAC0_IRQHandler from startup_mkl25z4.o(.text) referenced from startup_mkl25z4.o(RESET)
- DMA0_IRQHandler from startup_mkl25z4.o(.text) referenced from startup_mkl25z4.o(RESET)
- DMA1_IRQHandler from startup_mkl25z4.o(.text) referenced from startup_mkl25z4.o(RESET)
- DMA2_IRQHandler from startup_mkl25z4.o(.text) referenced from startup_mkl25z4.o(RESET)
- DMA3_IRQHandler from startup_mkl25z4.o(.text) referenced from startup_mkl25z4.o(RESET)
- FTFA_IRQHandler from startup_mkl25z4.o(.text) referenced from startup_mkl25z4.o(RESET)
- GPGGA_Process from gps.o(.text) referenced from gps.o(.constdata)
- GPGSA_Process from gps.o(.text) referenced from gps.o(.constdata)
- GPGSV_Process from gps.o(.text) referenced from gps.o(.constdata)
- GPRMC_Process from gps.o(.text) referenced from gps.o(.constdata)
- GPRS_CloseSocket from at_command_parser.o(.text) referenced from at_command_parser.o(.constdata)
- GPRS_CloseSocket1 from at_command_parser.o(.text) referenced from at_command_parser.o(.constdata)
- GPRS_CreateSocket from at_command_parser.o(.text) referenced from at_command_parser.o(.constdata)
- GPRS_Deactivation from at_command_parser.o(.text) referenced from at_command_parser.o(.constdata)
- GPRS_GetDNS from at_command_parser.o(.text) referenced from at_command_parser.o(.constdata)
- GPRS_GetData from at_command_parser.o(.text) referenced from at_command_parser.o(.constdata)
- GPRS_GetLength from at_command_parser.o(.text) referenced from at_command_parser.o(.constdata)
- GPRS_SocketControl from at_command_parser.o(.text) referenced from at_command_parser.o(.constdata)
- GetBatteryStatus from at_command_parser.o(.text) referenced from at_command_parser.o(.constdata)
- GetCallerNumber from at_command_parser.o(.text) referenced from at_command_parser.o(.constdata)
- GsmGetTime from at_command_parser.o(.text) referenced from at_command_parser.o(.constdata)
- HardFault_Handler from project_main.o(.text) referenced from startup_mkl25z4.o(RESET)
- I2C0_IRQHandler from startup_mkl25z4.o(.text) referenced from startup_mkl25z4.o(RESET)
- I2C1_IRQHandler from startup_mkl25z4.o(.text) referenced from startup_mkl25z4.o(RESET)
- LLW_IRQHandler from llwu.o(.text) referenced from startup_mkl25z4.o(RESET)
- LPTimer_IRQHandler from tick.o(.text) referenced from startup_mkl25z4.o(RESET)
- LVD_LVW_IRQHandler from startup_mkl25z4.o(.text) referenced from startup_mkl25z4.o(RESET)
- MCG_IRQHandler from startup_mkl25z4.o(.text) referenced from startup_mkl25z4.o(RESET)
- NMI_Handler from nmi_isr_handler.o(.text) referenced from startup_mkl25z4.o(RESET)
- PIT_IRQHandler from startup_mkl25z4.o(.text) referenced from startup_mkl25z4.o(RESET)
- PORTA_IRQHandler from startup_mkl25z4.o(.text) referenced from startup_mkl25z4.o(RESET)
- PORTD_IRQHandler from project_main.o(.text) referenced from startup_mkl25z4.o(RESET)
- PendSV_Handler from startup_mkl25z4.o(.text) referenced from startup_mkl25z4.o(RESET)
- RTC_IRQHandler from startup_mkl25z4.o(.text) referenced from startup_mkl25z4.o(RESET)
- RTC_Seconds_IRQHandler from startup_mkl25z4.o(.text) referenced from startup_mkl25z4.o(RESET)
- Reserved20_IRQHandler from startup_mkl25z4.o(.text) referenced from startup_mkl25z4.o(RESET)
- Reserved39_IRQHandler from startup_mkl25z4.o(.text) referenced from startup_mkl25z4.o(RESET)
- Reserved45_IRQHandler from startup_mkl25z4.o(.text) referenced from startup_mkl25z4.o(RESET)
- Reset_Handler from startup_mkl25z4.o(.text) referenced from startup_mkl25z4.o(RESET)
- RingCallProcess from at_command_parser.o(.text) referenced from at_command_parser.o(.constdata)
- SMS_ModemOk from at_command_parser.o(.text) referenced from at_command_parser.o(.constdata)
- SMS_NewMessage from at_command_parser.o(.text) referenced from at_command_parser.o(.constdata)
- SMS_Process from at_command_parser.o(.text) referenced 3 times from at_command_parser.o(.constdata)
- SMS_ReadMsg from at_command_parser.o(.text) referenced from at_command_parser.o(.constdata)
- SPI0_IRQHandler from startup_mkl25z4.o(.text) referenced from startup_mkl25z4.o(RESET)
- SPI1_IRQHandler from startup_mkl25z4.o(.text) referenced from startup_mkl25z4.o(RESET)
- SVC_Handler from startup_mkl25z4.o(.text) referenced from startup_mkl25z4.o(RESET)
- SysTick_Handler from tick.o(.text) referenced from startup_mkl25z4.o(RESET)
- SystemInit from system_mkl25z4.o(.text) referenced from startup_mkl25z4.o(.text)
- TPM0_IRQHandler from dbg_cfg_app.o(.text) referenced from startup_mkl25z4.o(RESET)
- TPM1_IRQHandler from audio.o(.text) referenced from startup_mkl25z4.o(RESET)
- TPM2_IRQHandler from dtmf_app.o(.text) referenced from startup_mkl25z4.o(RESET)
- TSI0_IRQHandler from startup_mkl25z4.o(.text) referenced from startup_mkl25z4.o(RESET)
- UART0_IRQHandler from uart.o(.text) referenced from startup_mkl25z4.o(RESET)
- UART1_IRQHandler from uart.o(.text) referenced from startup_mkl25z4.o(RESET)
- UART2_IRQHandler from startup_mkl25z4.o(.text) referenced from startup_mkl25z4.o(RESET)
- USB0_IRQHandler from usbhw.o(.text) referenced from startup_mkl25z4.o(RESET)
- USB_EndPoint0 from usbcore.o(.text) referenced from usbuser.o(.constdata)
- USB_EndPoint1 from usbuser.o(.text) referenced from usbuser.o(.constdata)
- __main from entry.o(.ARM.Collect$$$$00000000) referenced from startup_mkl25z4.o(.text)
- _sbackspace from _sgetc.o(.text) referenced 2 times from __0sscanf.o(.text)
- _scanf_char_input from scanf_char.o(.text) referenced from scanf_char.o(.text)
- _sgetc from _sgetc.o(.text) referenced 2 times from __0sscanf.o(.text)
- _sputc from printf8.o(i._sputc) referenced from printf8.o(i.__0sprintf$8)
- _sputc from printfa.o(i._sputc) referenced from printfa.o(i.__0vsprintf)
- isspace from isspace_o.o(.text) referenced 2 times from scanf_char.o(.text)
- main from project_main.o(.text) referenced from entry9a.o(.ARM.Collect$$$$0000000B)

### Global Symbols

__main (Thumb, 0 bytes, Stack size unknown bytes, entry.o(.ARM.Collect$$$$00000000))
[Address Reference Count : 1]

- startup_mkl25z4.o(.text)

_main_stk (Thumb, 0 bytes, Stack size unknown bytes, entry2.o(.ARM.Collect$$$$00000001))

_main_scatterload (Thumb, 0 bytes, Stack size unknown bytes, entry5.o(.ARM.Collect$$$$00000004))

[Calls]

- >> __scatterload

__main_after_scatterload (Thumb, 0 bytes, Stack size unknown bytes, entry5.o(.ARM.Collect$$$$00000004))

[Called By]

- >> __scatterload

_main_clock (Thumb, 0 bytes, Stack size unknown bytes, entry7b.o(.ARM.Collect$$$$00000008))

_main_cpp_init (Thumb, 0 bytes, Stack size unknown bytes, entry8b.o(.ARM.Collect$$$$0000000A))

_main_init (Thumb, 0 bytes, Stack size unknown bytes, entry9a.o(.ARM.Collect$$$$0000000B))

__rt_final_cpp (Thumb, 0 bytes, Stack size unknown bytes, entry10a.o(.ARM.Collect$$$$0000000D))

__rt_final_exit (Thumb, 0 bytes, Stack size unknown bytes, entry11a.o(.ARM.Collect$$$$0000000F))

HardFault_Handler (Thumb, 4 bytes, Stack size 0 bytes, project_main.o(.text))

[Calls]

- >> NVIC_SystemReset

[Address Reference Count : 1]

- startup_mkl25z4.o(RESET)

PIN_InterruptInit (Thumb, 104 bytes, Stack size 8 bytes, project_main.o(.text))

[Stack]

- Max Depth = 20
- Call Chain = PIN_InterruptInit ⇒ llwu_configure

[Calls]

- >> llwu_configure
- >> NVIC_SetPriority
- >> NVIC_EnableIRQ

[Called By]

- >> main
- >> SysSleep
- >> SysPwrOff

PORTD_IRQHandler (Thumb, 82 bytes, Stack size 8 bytes, project_main.o(.text))

[Stack]

- Max Depth = 8
- Call Chain = PORTD_IRQHandler

[Calls]

- >> VoiceCallTask_GetPhase
- >> AudioEnable

[Address Reference Count : 1]

- startup_mkl25z4.o(RESET)

SysPwrOff (Thumb, 126 bytes, Stack size 8 bytes, project_main.o(.text))

[Stack]

- Max Depth = 180
- Call Chain = SysPwrOff ⇒ AudioPlayFile ⇒ SetLowPowerModes ⇒ LowPowerModes ⇒ vlp_clock_config ⇒ PEE_to_BLPE ⇒ atc ⇒ __aeabi_idivmod ⇒ __aeabi_uidivmod

[Calls]

- >> USB_Init
- >> USB_Connect
- >> TPM0_Init
- >> SetLowPowerModes
- >> AudioStopAll
- >> AudioPlayFile
- >> PIN_InterruptInit

[Called By]

- >> main

SysSleep (Thumb, 618 bytes, Stack size 16 bytes, project_main.o(.text))

[Stack]

- Max Depth = 736
- Call Chain = SysSleep ⇒ TrackerTask ⇒ PedometerTask ⇒ ambo_step_detect ⇒ b2_filter

[Calls]

- >> VoiceCallTask_GetPhase
- >> USB_Init
- >> USB_Connect
- >> TrackerTask
- >> TPM0_Init
- >> TPM0_DeInit
- >> SosTask_IsAlarmActivated
- >> SmsTask_GetPhase
- >> SetLowPowerModes
- >> MODEM_SendCommand
- >> InitTimeout
- >> GpsTask_GetPhase
- >> GprsTask_GetPhase
- >> DelayMs
- >> AudioStopAll
- >> AudioEnable
- >> PIN_InterruptInit
- >> __aeabi_uidivmod

[Called By]

- >> AppRun

AppRun (Thumb, 672 bytes, Stack size 32 bytes, project_main.o(.text))

[Stack]

- Max Depth = 768
- Call Chain = AppRun ⇒ SysSleep ⇒ TrackerTask ⇒ PedometerTask ⇒ ambo_step_detect ⇒ b2_filter

[Calls]

- >> VoiceCall_Task
- >> VoiceCallTask_GetPhase
- >> Sos_Task
- >> SosTask_IsAlarmActivated
- >> SosTask_GetPhase
- >> Sms_Task
- >> SmsTask_GetPhase
- >> SetLowPowerModes
- >> SMS_Manage
- >> ModemCmd_Task
- >> ModemCmdTask_IsIdle
- >> MODEM_SendCommand
- >> Io_Task
- >> InitTimeout
- >> Gsm_Task
- >> GsmTask_GetPhase
- >> GpsTask_GetPhase
- >> Gprs_Task
- >> GprsTask_StartTask
- >> GprsTask_GetPhase
- >> CheckTimeout
- >> AudioStopCheck
- >> SysSleep
- >> NVIC_SystemReset
- >> __aeabi_idivmod

[Called By]

- >> main

main (Thumb, 1072 bytes, Stack size 8 bytes, project_main.o(.text))

[Stack]

- Max Depth = 776
- Call Chain = main ⇒ AppRun ⇒ SysSleep ⇒ TrackerTask ⇒ PedometerTask ⇒ ambo_step_detect ⇒ b2_filter

[Calls]

- >> uart_init
- >> uart0_init
- >> start
- >> llwu_configure
- >> VoiceCallTask_Init
- >> USB_Init
- >> USB_Connect
- >> TrackerInit
- >> TPM0_Init
- >> TICK_Init
- >> SosTask_Init
- >> SmsTask_Init
- >> SetLowPowerModes
- >> SST25_Init
- >> PedometerTaskInit
- >> MODEM_SendCommand
- >> MODEM_PowerOff
- >> MODEM_Init
- >> LPTMR_init
- >> Keys_Init
- >> InitTimeout
- >> GsmTask_Init
- >> GpsTask_Init
- >> GprsTask_Init
- >> GPSInit
- >> DelayMs
- >> DB_FlashMemInit
- >> CFG_Load
- >> AudioStopAll
- >> AudioPlayFile
- >> AUDIO_Init
- >> AppRun
- >> SysPwrOff
- >> PIN_InterruptInit
- >> NVIC_EnableIRQ

[Address Reference Count : 1]

- entry9a.o(.ARM.Collect$$$$0000000B)

clockMonitor (Thumb, 32 bytes, Stack size 0 bytes, power_management.o(.text))

[Called By]

- >> LowPowerModes
- >> vlp_clock_config

uart_configure (Thumb, 2 bytes, Stack size 0 bytes, power_management.o(.text))

[Called By]

- >> vlp_clock_config

PEE_to_BLPE (Thumb, 34 bytes, Stack size 8 bytes, power_management.o(.text))

[Stack]

- Max Depth = 108
- Call Chain = PEE_to_BLPE ⇒ atc ⇒ __aeabi_idivmod ⇒ __aeabi_uidivmod

[Calls]

- >> pee_pbe
- >> pbe_blpe
- >> atc

[Called By]

- >> vlp_clock_config

vlp_clock_config (Thumb, 1228 bytes, Stack size 24 bytes, power_management.o(.text))

[Stack]

- Max Depth = 132
- Call Chain = vlp_clock_config ⇒ PEE_to_BLPE ⇒ atc ⇒ __aeabi_idivmod ⇒ __aeabi_uidivmod

[Calls]

- >> what_mcg_mode
- >> pee_pbe
- >> pbe_pee
- >> pbe_fbe
- >> fei_fbi
- >> fei_fbe
- >> fbi_fei
- >> fbi_fbe
- >> fbi_blpi
- >> fbe_pbe
- >> fbe_fbi
- >> fbe_blpe
- >> exit_vlpr
- >> blpi_fbi
- >> blpe_pbe
- >> blpe_fbe
- >> atc
- >> __ARM_common_switch8
- >> PEE_to_BLPE
- >> uart_configure
- >> clockMonitor
- >> __aeabi_idivmod
- >> __aeabi_uidivmod

[Called By]

- >> LowPowerModes

LowPowerModes (Thumb, 350 bytes, Stack size 16 bytes, power_management.o(.text))

[Stack]

- Max Depth = 148
- Call Chain = LowPowerModes ⇒ vlp_clock_config ⇒ PEE_to_BLPE ⇒ atc ⇒ __aeabi_idivmod ⇒ __aeabi_uidivmod

[Calls]

- >> what_mcg_mode
- >> pbe_pee
- >> exit_vlpr
- >> enter_vlpr
- >> enter_lls
- >> __ARM_common_switch8
- >> vlp_clock_config
- >> clockMonitor

[Called By]

- >> SetLowPowerModes

SetLowPowerModes (Thumb, 498 bytes, Stack size 8 bytes, power_management.o(.text))

[Stack]

- Max Depth = 156
- Call Chain = SetLowPowerModes ⇒ LowPowerModes ⇒ vlp_clock_config ⇒ PEE_to_BLPE ⇒ atc ⇒ __aeabi_idivmod ⇒ __aeabi_uidivmod

[Calls]

- >> Flash_Init
- >> LowPowerModes
- >> uart_init
- >> uart0_init
- >> USB_Init
- >> USB_Connect
- >> TPM0_Init
- >> TICK_Init
- >> SST25_Init
- >> AUDIO_Init

[Called By]

- >> Gsm_Task
- >> AudioPlayFile
- >> main
- >> AppRun
- >> SysSleep
- >> SysPwrOff
- >> AudioControler

BLPE_to_PEE (Thumb, 34 bytes, Stack size 8 bytes, power_management.o(.text), UNUSED)

[Calls]

- >> pbe_pee
- >> blpe_pbe

GsmTask_Init (Thumb, 8 bytes, Stack size 0 bytes, gsm_gprs_tasks.o(.text))

[Called By]

- >> UploadConfig_Task
- >> SendPowerCmd_GprsTask
- >> SendGpsData_GprsTask
- >> Sms_Task
- >> ModemCmd_Task
- >> Io_Task
- >> Gprs_Task
- >> main

GprsTask_GetPhase (Thumb, 48 bytes, Stack size 8 bytes, gsm_gprs_tasks.o(.text))

[Stack]

- Max Depth = 8
- Call Chain = GprsTask_GetPhase

[Calls]

- >> UploadConfigTask_GetPhase

[Called By]

- >> GprsTask_StopTask
- >> TrackerTask
- >> Io_Task
- >> AppRun
- >> SysSleep
- >> GsmLedControl

GprsTask_StopTask (Thumb, 102 bytes, Stack size 8 bytes, gsm_gprs_tasks.o(.text))

[Stack]

- Max Depth = 536
- Call Chain = GprsTask_StopTask ⇒ Gprs_Task ⇒ GprsTask_Stop (Cycle)

[Calls]

- >> UploadConfigTask_Stop
- >> ModemCmdTask_Cancel
- >> ModemCmd_Task
- >> InitTimeout
- >> Gprs_Task
- >> GprsTask_GetPhase
- >> CheckTimeout

[Called By]

- >> GprsTask_Stop

GprsTask_Stop (Thumb, 12 bytes, Stack size 8 bytes, gsm_gprs_tasks.o(.text))

[Stack]

- Max Depth = 544
- Call Chain = GprsTask_Stop ⇒ GprsTask_StopTask ⇒ Gprs_Task ⇒ GprsTask_Stop (Cycle)

[Calls]

- >> GprsTask_StopTask

[Called By]

- >> UploadConfigTask_WaitRetry
- >> UploadConfigTask_Retry
- >> UploadConfigTask_Start
- >> VoiceCallTask_EndCall
- >> SosTask_End
- >> UploadConfig_Task
- >> SendPowerCmd_GprsTask
- >> SendPowerCmdTask_Retry
- >> SendGpsData_GprsTask
- >> SendGpsDataTask_Retry
- >> VoiceCall_Task
- >> Gprs_Task

GprsTask_SetPhase (Thumb, 54 bytes, Stack size 8 bytes, gsm_gprs_tasks.o(.text), UNUSED)

[Calls]

- >> UploadConfigTask_SetPhase

GprsTask_WakeUp (Thumb, 84 bytes, Stack size 8 bytes, gsm_gprs_tasks.o(.text), UNUSED)

[Calls]

- >> UploadConfigTask_WakeUp

GprsTask_StartTask (Thumb, 8 bytes, Stack size 0 bytes, gsm_gprs_tasks.o(.text))

[Called By]

- >> SosTask_End
- >> CMD_CfgParse
- >> TrackerTask
- >> Sos_Task
- >> Io_Task
- >> Gprs_Task
- >> AppRun

SendGpsDataTask_Retry (Thumb, 54 bytes, Stack size 8 bytes, gsm_gprs_tasks.o(.text))

[Stack]

- Max Depth = 12 + In Cycle
- Call Chain = SendGpsDataTask_Retry ⇒ GprsTask_Stop (Cycle)

[Calls]

- >> IoTask_IsModemBusy
- >> GprsTask_Stop
- >> SosTask_GetPhase
- >> InitTimeout

[Called By]

- >> SendGpsData_GprsTask

GsmTask_GetPhase (Thumb, 6 bytes, Stack size 0 bytes, gsm_gprs_tasks.o(.text))

[Called By]

- >> UploadConfig_Task
- >> SendPowerCmd_GprsTask
- >> SendGpsData_GprsTask
- >> Sos_Task
- >> Sms_Task
- >> Gprs_Task
- >> AppRun

SendGpsData_GprsTask (Thumb, 2988 bytes, Stack size 48 bytes, gsm_gprs_tasks.o(.text))

[Stack]

- Max Depth = 520 + In Cycle
- Call Chain = SendGpsData_GprsTask ⇒ GprsTask_Stop (Cycle)

[Calls]

- >> uart_putchar
- >> ModemCmdTask_SetCriticalCmd
- >> ModemCmdTask_SendCmd
- >> ModemCmdTask_IsCriticalCmd
- >> ModemCmdTask_GetPhase
- >> MODEM_GetSocket
- >> MODEM_GetCSQ
- >> MODEM_DisconectSocket
- >> MODEM_CheckGPRSDataOut
- >> IsGprsDataPacket
- >> IoTask_IsModemBusy
- >> GetTrackerMsg
- >> GPRS_CmdRecvData
- >> CheckTrackerMsgIsReady
- >> CMD_CfgParse
- >> SendGpsDataTask_Retry
- >> GprsTask_Stop
- >> __ARM_common_switch8
- >> SosTask_GetPhase
- >> ModemCmdTask_IsIdle
- >> MODEM_SendCommand
- >> InitTimeout
- >> GsmTask_Init
- >> GsmTask_GetPhase
- >> DelayMs
- >> CheckTimeout
- >> __aeabi_memcpy

[Called By]

- >> Gprs_Task

SendPowerCmdTask_Retry (Thumb, 162 bytes, Stack size 8 bytes, gsm_gprs_tasks.o(.text))

[Stack]

- Max Depth = 12 + In Cycle
- Call Chain = SendPowerCmdTask_Retry ⇒ GprsTask_Stop (Cycle)

[Calls]

- >> IoTask_IsModemBusy
- >> GprsTask_Stop
- >> InitTimeout

[Called By]

- >> SendPowerCmd_GprsTask

SendPowerCmd_GprsTask (Thumb, 2106 bytes, Stack size 48 bytes, gsm_gprs_tasks.o(.text))

[Stack]

- Max Depth = 520 + In Cycle
- Call Chain = SendPowerCmd_GprsTask ⇒ GprsTask_Stop (Cycle)

[Calls]

- >> uart_putchar
- >> ModemCmdTask_SetCriticalCmd
- >> ModemCmdTask_SendCmd
- >> ModemCmdTask_IsCriticalCmd
- >> ModemCmdTask_GetPhase
- >> MODEM_GetSocket
- >> MODEM_DisconectSocket
- >> MODEM_CheckGPRSDataOut
- >> IsGprsDataPacket
- >> IoTask_IsModemBusy
- >> GPRS_CmdRecvData
- >> DPWO_Add
- >> DPWF_Add
- >> CMD_CfgParse
- >> SendPowerCmdTask_Retry
- >> GprsTask_Stop
- >> __ARM_common_switch8
- >> ModemCmdTask_IsIdle
- >> MODEM_SendCommand
- >> InitTimeout
- >> GsmTask_Init
- >> GsmTask_GetPhase
- >> DelayMs
- >> CheckTimeout
- >> __aeabi_memcpy

[Called By]

- >> Gprs_Task

Gprs_Task (Thumb, 364 bytes, Stack size 8 bytes, gsm_gprs_tasks.o(.text))

[Stack]

- Max Depth = 528 + In Cycle
- Call Chain = Gprs_Task ⇒ GprsTask_Stop (Cycle)

[Calls]

- >> VoiceCallTask_IsIdle
- >> UploadConfig_Task
- >> UploadConfigTask_IsWaitingForRetryTimedOut
- >> UploadConfigTask_IsWaitingForRetry
- >> SmsTask_IsIdle
- >> SendPowerCmd_GprsTask
- >> SendGpsData_GprsTask
- >> GprsTask_Stop
- >> __ARM_common_switch8
- >> SosTask_GetPhase
- >> GsmTask_Init
- >> GsmTask_GetPhase
- >> GprsTask_StartTask

[Called By]

- >> GprsTask_StopTask
- >> AppRun

GprsTask_Init (Thumb, 40 bytes, Stack size 8 bytes, gsm_gprs_tasks.o(.text))

[Stack]

- Max Depth = 20
- Call Chain = GprsTask_Init ⇒ UploadConfigTask_Init ⇒ InitTimeout

[Calls]

- >> UploadConfigTask_Init

[Called By]

- >> Io_Task
- >> main

GprsTask_GetTask (Thumb, 6 bytes, Stack size 0 bytes, gsm_gprs_tasks.o(.text))

[Called By]

- >> Sms_Task

Gsm_Task (Thumb, 1888 bytes, Stack size 24 bytes, gsm_gprs_tasks.o(.text))

[Stack]

- Max Depth = 312
- Call Chain = Gsm_Task ⇒ MODEM_GetCSQ ⇒ __0sscanf ⇒ __vfscanf_char ⇒ __vfscanf ⇒ _scanf_real

[Calls]

- >> uart_putstr
- >> ModemCmdTask_SendCmd
- >> ModemCmdTask_GetPhase
- >> MODEM_GetCSQ
- >> GetIMEI
- >> CFG_Save
- >> __ARM_common_switch8
- >> uart_init
- >> SetLowPowerModes
- >> ModemCmdTask_IsIdle
- >> MODEM_SendCommand
- >> InitTimeout
- >> DelayMs
- >> CheckTimeout
- >> strcpy
- >> strcmp
- >> strlen

[Called By]

- >> AppRun

SosTask_GetPhase (Thumb, 6 bytes, Stack size 0 bytes, sos_tasks.o(.text))

[Called By]

- >> UploadConfigTask_Start
- >> PlayAlarmWarningSound
- >> SendGpsData_GprsTask
- >> SendGpsDataTask_Retry
- >> VoiceCall_Task
- >> Sms_Task
- >> Io_Task
- >> Gprs_Task
- >> AppRun

ResetAllAlarmWarning (Thumb, 50 bytes, Stack size 0 bytes, sos_tasks.o(.text))

[Called By]

- >> SosTask_End
- >> SosTask_Start
- >> SosTask_Reset
- >> Sos_Task

SosTask_Reset (Thumb, 22 bytes, Stack size 4 bytes, sos_tasks.o(.text))

[Stack]

- Max Depth = 4
- Call Chain = SosTask_Reset

[Calls]

- >> ResetAllAlarmWarning

[Called By]

- >> VoiceCall_Task
- >> SosTask_Init
- >> Io_Task

SosTask_Init (Thumb, 20 bytes, Stack size 4 bytes, sos_tasks.o(.text))

[Stack]

- Max Depth = 8
- Call Chain = SosTask_Init ⇒ SosTask_Reset

[Calls]

- >> SosTask_Reset

[Called By]

- >> Io_Task
- >> main

SosTask_InitPromptTimeOut (Thumb, 20 bytes, Stack size 8 bytes, sos_tasks.o(.text))

[Stack]

- Max Depth = 12
- Call Chain = SosTask_InitPromptTimeOut ⇒ InitTimeout

[Calls]

- >> InitTimeout

[Called By]

- >> Sos_Task

SosTask_PromptForWaiting (Thumb, 74 bytes, Stack size 8 bytes, sos_tasks.o(.text))

[Stack]

- Max Depth = 180
- Call Chain = SosTask_PromptForWaiting ⇒ AudioPlayFile ⇒ SetLowPowerModes ⇒ LowPowerModes ⇒ vlp_clock_config ⇒ PEE_to_BLPE ⇒ atc ⇒ __aeabi_idivmod ⇒ __aeabi_uidivmod

[Calls]

- >> InitTimeout
- >> CheckTimeout
- >> AudioPlayFile

[Called By]

- >> Sos_Task

SosTask_Start (Thumb, 124 bytes, Stack size 8 bytes, sos_tasks.o(.text))

[Stack]

- Max Depth = 456
- Call Chain = SosTask_Start ⇒ DSOS_Add ⇒ formatLatLng ⇒ floor ⇒ __aeabi_drsub ⇒ __aeabi_dadd ⇒ _double_epilogue ⇒ _double_round

[Calls]

- >> VoiceCallTask_ClearCallAction
- >> DSOS_Add
- >> ResetAllAlarmWarning

[Called By]

- >> Io_Task

SosTask_End (Thumb, 144 bytes, Stack size 8 bytes, sos_tasks.o(.text))

[Stack]

- Max Depth = 552
- Call Chain = SosTask_End ⇒ GprsTask_Stop ⇒ GprsTask_StopTask ⇒ Gprs_Task ⇒ GprsTask_Stop (Cycle)

[Calls]

- >> VoiceCallTask_ClearCallAction
- >> SmsTask_Stop
- >> DSOS_Add
- >> ResetAllAlarmWarning
- >> GprsTask_Stop
- >> VoiceCallTask_GetPhase
- >> GprsTask_StartTask
- >> AudioStopAll
- >> AudioPlayFile

[Called By]

- >> Io_Task

SosTask_IsCancelCall (Thumb, 22 bytes, Stack size 0 bytes, sos_tasks.o(.text))

[Called By]

- >> VoiceCall_Task

SosTask_IsAlarmActivated (Thumb, 32 bytes, Stack size 0 bytes, sos_tasks.o(.text))

[Called By]

- >> VoiceCall_Task
- >> Io_Task
- >> AppRun
- >> SysSleep

SosTask_IsWaititngForCall (Thumb, 40 bytes, Stack size 0 bytes, sos_tasks.o(.text))

[Called By]

- >> VoiceCall_Task

ComparePhoneNumber (Thumb, 180 bytes, Stack size 40 bytes, sos_tasks.o(.text))

[Stack]

- Max Depth = 40
- Call Chain = ComparePhoneNumber

[Calls]

- >> strlen

[Called By]

- >> VoiceCall_Task
- >> Sos_Task

SosTask_SendSms (Thumb, 54 bytes, Stack size 8 bytes, sos_tasks.o(.text))

[Stack]

- Max Depth = 24
- Call Chain = SosTask_SendSms ⇒ SmsTask_SetMessage

[Calls]

- >> SmsTask_SetMessage
- >> SmsTask_SendSms
- >> SmsTask_ClearAllSms
- >> SmsTask_AddPhoneNo
- >> InitTimeout

[Called By]

- >> Sos_Task

Sos_Task (Thumb, 2714 bytes, Stack size 16 bytes, sos_tasks.o(.text))

[Stack]

- Max Depth = 568
- Call Chain = Sos_Task ⇒ VoiceCallTask_EndCall ⇒ GprsTask_Stop ⇒ GprsTask_StopTask ⇒ Gprs_Task ⇒ GprsTask_Stop (Cycle)

[Calls]

- >> VoiceCallTask_StartCall
- >> VoiceCallTask_IsDtmfKeyPressed
- >> VoiceCallTask_GetCallerPhoneNo
- >> VoiceCallTask_EndCall
- >> VoiceCallTask_DeInitDtmf
- >> VoiceCallTask_ClearEndCallStatus
- >> VoiceCallTask_ClearCallAction
- >> VoiceCallTask_AnswerCall
- >> SmsTask_Stop
- >> SmsTask_SetMessage
- >> SmsTask_SendSms
- >> SmsTask_IsSmsSent
- >> SmsTask_ClearAllSms
- >> SmsTask_AddAllContactPhoneNo
- >> GpsTask_EnableGps
- >> DSOS_Add
- >> SosTask_SendSms
- >> ComparePhoneNumber
- >> SosTask_PromptForWaiting
- >> SosTask_InitPromptTimeOut
- >> ResetAllAlarmWarning
- >> uart_putchar
- >> VoiceCallTask_IsIdle
- >> SmsTask_IsIdle
- >> __ARM_common_switch8
- >> VoiceCallTask_GetPhase
- >> SmsTask_GetPhase
- >> InitTimeout
- >> GsmTask_GetPhase
- >> GprsTask_StartTask
- >> CheckTimeout
- >> AudioStopAll
- >> AudioPlayFile
- >> __2sprintf
- >> __aeabi_memcpy

[Called By]

- >> AppRun

PlayBatteryStatus (Thumb, 30 bytes, Stack size 8 bytes, io_tasks.o(.text))

[Stack]

- Max Depth = 180
- Call Chain = PlayBatteryStatus ⇒ AudioPlayFile ⇒ SetLowPowerModes ⇒ LowPowerModes ⇒ vlp_clock_config ⇒ PEE_to_BLPE ⇒ atc ⇒ __aeabi_idivmod ⇒ __aeabi_uidivmod

[Calls]

- >> AudioPlayFile

[Called By]

- >> VoiceCall_Task

VoiceCallTask_GetPhase (Thumb, 6 bytes, Stack size 0 bytes, io_tasks.o(.text))

[Called By]

- >> PlayAlarmWarningSound
- >> SosTask_End
- >> Sos_Task
- >> Sms_Task
- >> Io_Task
- >> AppRun
- >> SysSleep
- >> PORTD_IRQHandler
- >> LPTimerTask

PlayAlarmWarningSound (Thumb, 40 bytes, Stack size 8 bytes, io_tasks.o(.text))

[Stack]

- Max Depth = 8
- Call Chain = PlayAlarmWarningSound

[Calls]

- >> VoiceCallTask_GetPhase
- >> SosTask_GetPhase

[Called By]

- >> LPTimerTask

Keys_Init (Thumb, 32 bytes, Stack size 0 bytes, io_tasks.o(.text))

[Called By]

- >> IoTask_Init
- >> main
- >> KeyTask_Control

IoTask_Init (Thumb, 18 bytes, Stack size 4 bytes, io_tasks.o(.text))

[Stack]

- Max Depth = 4
- Call Chain = IoTask_Init

[Calls]

- >> Keys_Init

[Called By]

- >> Io_Task

VoiceCallTask_AnswerCall (Thumb, 46 bytes, Stack size 8 bytes, io_tasks.o(.text))

[Stack]

- Max Depth = 12
- Call Chain = VoiceCallTask_AnswerCall ⇒ InitTimeout

[Calls]

- >> InitTimeout

[Called By]

- >> VoiceCall_Task
- >> Sos_Task
- >> Io_Task

VoiceCallTask_EndCall (Thumb, 128 bytes, Stack size 8 bytes, io_tasks.o(.text))

[Stack]

- Max Depth = 552
- Call Chain = VoiceCallTask_EndCall ⇒ GprsTask_Stop ⇒ GprsTask_StopTask ⇒ Gprs_Task ⇒ GprsTask_Stop (Cycle)

[Calls]

- >> GprsTask_Stop
- >> InitTimeout

[Called By]

- >> VoiceCall_Task
- >> Sos_Task
- >> Io_Task

VoiceCallTask_Init (Thumb, 60 bytes, Stack size 0 bytes, io_tasks.o(.text))

[Called By]

- >> Io_Task
- >> main

Io_Task (Thumb, 1090 bytes, Stack size 8 bytes, io_tasks.o(.text))

[Stack]

- Max Depth = 560
- Call Chain = Io_Task ⇒ VoiceCallTask_EndCall ⇒ GprsTask_Stop ⇒ GprsTask_StopTask ⇒ Gprs_Task ⇒ GprsTask_Stop (Cycle)

[Calls]

- >> PlayVersion
- >> IoTask_Init
- >> VoiceCallTask_EndCall
- >> VoiceCallTask_AnswerCall
- >> GpsTask_EnableGps
- >> SosTask_End
- >> SosTask_Start
- >> SosTask_Reset
- >> VoiceCallTask_Init
- >> VoiceCallTask_GetPhase
- >> USB_Init
- >> USB_Connect
- >> SosTask_IsAlarmActivated
- >> SosTask_Init
- >> SosTask_GetPhase
- >> InitTimeout
- >> GsmTask_Init
- >> GprsTask_StartTask
- >> GprsTask_Init
- >> GprsTask_GetPhase
- >> DelayMs
- >> CheckTimeout
- >> AudioStopAll
- >> AudioPlayFile

[Called By]

- >> AppRun

VoiceCallTask_InitDtmf (Thumb, 40 bytes, Stack size 8 bytes, io_tasks.o(.text))

[Stack]

- Max Depth = 44
- Call Chain = VoiceCallTask_InitDtmf ⇒ DTMF_Init ⇒ TPM2_Init ⇒ __aeabi_uidivmod

[Calls]

- >> DTMF_Init

[Called By]

- >> VoiceCall_Task

VoiceCallTask_DeInitDtmf (Thumb, 14 bytes, Stack size 8 bytes, io_tasks.o(.text))

[Stack]

- Max Depth = 12
- Call Chain = VoiceCallTask_DeInitDtmf ⇒ DTMF_DeInit

[Calls]

- >> DTMF_DeInit

[Called By]

- >> Sos_Task

GetDtmfKey (Thumb, 32 bytes, Stack size 16 bytes, io_tasks.o(.text))

[Stack]

- Max Depth = 16
- Call Chain = GetDtmfKey

[Calls]

- >> RINGBUF_Get

[Called By]

- >> VoiceCall_Task

VoiceCallTask_IsDtmfKeyPressed (Thumb, 6 bytes, Stack size 0 bytes, io_tasks.o(.text))

[Called By]

- >> Sos_Task

VoiceCallTask_ClearEndCallStatus (Thumb, 42 bytes, Stack size 4 bytes, io_tasks.o(.text))

[Stack]

- Max Depth = 12
- Call Chain = VoiceCallTask_ClearEndCallStatus ⇒ __ARM_common_switch8

[Calls]

- >> __ARM_common_switch8

[Called By]

- >> VoiceCallTask_StartCall
- >> VoiceCallTask_ClearCallAction
- >> Sos_Task

VoiceCallTask_IsIdle (Thumb, 52 bytes, Stack size 0 bytes, io_tasks.o(.text))

[Called By]

- >> VoiceCallTask_StartCall
- >> Sos_Task
- >> Sms_Task
- >> Gprs_Task

VoiceCallTask_StartCall (Thumb, 108 bytes, Stack size 16 bytes, io_tasks.o(.text))

[Stack]

- Max Depth = 28
- Call Chain = VoiceCallTask_StartCall ⇒ VoiceCallTask_ClearEndCallStatus ⇒ __ARM_common_switch8

[Calls]

- >> VoiceCallTask_ClearEndCallStatus
- >> VoiceCallTask_IsIdle
- >> InitTimeout
- >> strcpy

[Called By]

- >> Sos_Task

VoiceCallTask_GetCallerPhoneNo (Thumb, 22 bytes, Stack size 0 bytes, io_tasks.o(.text))

[Called By]

- >> VoiceCall_Task
- >> Sos_Task

VoiceCallTask_IsModemBusy (Thumb, 40 bytes, Stack size 0 bytes, io_tasks.o(.text))

[Called By]

- >> IoTask_IsModemBusy

VoiceCallTask_ClearCallAction (Thumb, 22 bytes, Stack size 4 bytes, io_tasks.o(.text))

[Stack]

- Max Depth = 16
- Call Chain = VoiceCallTask_ClearCallAction ⇒ VoiceCallTask_ClearEndCallStatus ⇒ __ARM_common_switch8

[Calls]

- >> VoiceCallTask_ClearEndCallStatus

[Called By]

- >> SosTask_End
- >> SosTask_Start
- >> Sos_Task

SmsTask_SendSms (Thumb, 24 bytes, Stack size 0 bytes, io_tasks.o(.text))

[Called By]

- >> SosTask_SendSms
- >> Sos_Task
- >> Sms_Task

SmsTask_SetSosGGLinkMessage (Thumb, 60 bytes, Stack size 16 bytes, io_tasks.o(.text))

[Stack]

- Max Depth = 40
- Call Chain = SmsTask_SetSosGGLinkMessage ⇒ __2sprintf

[Calls]

- >> __2sprintf

[Called By]

- >> Sms_Task

SmsTask_AddAllContactPhoneNo (Thumb, 78 bytes, Stack size 8 bytes, io_tasks.o(.text))

[Stack]

- Max Depth = 8
- Call Chain = SmsTask_AddAllContactPhoneNo

[Calls]

- >> strcpy

[Called By]

- >> Sos_Task
- >> Sms_Task

SmsTask_ClearAllSms (Thumb, 76 bytes, Stack size 8 bytes, io_tasks.o(.text))

[Stack]

- Max Depth = 8
- Call Chain = SmsTask_ClearAllSms

[Calls]

- >> TICK_Get
- >> uart_putchar
- >> __aeabi_memclr

[Called By]

- >> SosTask_SendSms
- >> Sos_Task
- >> Sms_Task
- >> SmsTask_Init

SmsTask_SetSosAddressMessage (Thumb, 446 bytes, Stack size 56 bytes, io_tasks.o(.text))

[Stack]

- Max Depth = 80
- Call Chain = SmsTask_SetSosAddressMessage ⇒ __2sprintf

[Calls]

- >> __ARM_common_switch8
- >> __2sprintf

[Called By]

- >> Sms_Task

Sms_Task (Thumb, 1324 bytes, Stack size 16 bytes, io_tasks.o(.text))

[Stack]

- Max Depth = 96
- Call Chain = Sms_Task ⇒ SmsTask_SetSosAddressMessage ⇒ __2sprintf

[Calls]

- >> ModemCmdTask_SetWait
- >> SmsTask_SetSosAddressMessage
- >> SmsTask_SetSosGGLinkMessage
- >> SmsTask_SendSms
- >> SmsTask_ClearAllSms
- >> SmsTask_AddAllContactPhoneNo
- >> uart_putstr
- >> uart_putchar
- >> VoiceCallTask_IsIdle
- >> ModemCmdTask_GetPhase
- >> GprsTask_GetTask
- >> __ARM_common_switch8
- >> VoiceCallTask_GetPhase
- >> SosTask_GetPhase
- >> ModemCmdTask_IsIdle
- >> MODEM_SendCommand
- >> InitTimeout
- >> GsmTask_Init
- >> GsmTask_GetPhase
- >> DelayMs
- >> CheckTimeout
- >> __2sprintf
- >> __aeabi_memclr

[Called By]

- >> SmsTask_Pause
- >> AppRun

SmsTask_Pause (Thumb, 122 bytes, Stack size 8 bytes, io_tasks.o(.text))

[Stack]

- Max Depth = 104
- Call Chain = SmsTask_Pause ⇒ Sms_Task ⇒ SmsTask_SetSosAddressMessage ⇒ __2sprintf

[Calls]

- >> uart_putchar
- >> Sms_Task
- >> ModemCmd_Task
- >> InitTimeout
- >> CheckTimeout

[Called By]

- >> VoiceCall_Task

VoiceCall_Task (Thumb, 2326 bytes, Stack size 16 bytes, io_tasks.o(.text))

[Stack]

- Max Depth = 568
- Call Chain = VoiceCall_Task ⇒ VoiceCallTask_EndCall ⇒ GprsTask_Stop ⇒ GprsTask_StopTask ⇒ Gprs_Task ⇒ GprsTask_Stop (Cycle)

[Calls]

- >> VoiceSetup
- >> SmsTask_Pause
- >> GetDtmfKey
- >> VoiceCallTask_InitDtmf
- >> PlayBatteryStatus
- >> VoiceCallTask_GetCallerPhoneNo
- >> VoiceCallTask_EndCall
- >> VoiceCallTask_AnswerCall
- >> ComparePhoneNumber
- >> SosTask_IsWaititngForCall
- >> SosTask_IsCancelCall
- >> SosTask_Reset
- >> uart_putchar
- >> ModemCmdTask_SendCmd
- >> ModemCmdTask_GetPhase
- >> GprsTask_Stop
- >> __ARM_common_switch8
- >> SosTask_IsAlarmActivated
- >> SosTask_GetPhase
- >> ModemCmdTask_IsIdle
- >> InitTimeout
- >> DelayMs
- >> CheckTimeout
- >> AudioStopAll
- >> AudioPlayFile
- >> __aeabi_memclr
- >> __aeabi_memcpy

[Called By]

- >> AppRun

SmsTask_Init (Thumb, 44 bytes, Stack size 8 bytes, io_tasks.o(.text))

[Stack]

- Max Depth = 32
- Call Chain = SmsTask_Init ⇒ __2sprintf

[Calls]

- >> SmsTask_ClearAllSms
- >> __2sprintf

[Called By]

- >> main

SmsTask_AddPhoneNo (Thumb, 64 bytes, Stack size 16 bytes, io_tasks.o(.text))

[Stack]

- Max Depth = 16
- Call Chain = SmsTask_AddPhoneNo

[Calls]

- >> strcpy

[Called By]

- >> SosTask_SendSms

SmsTask_SetMessage (Thumb, 50 bytes, Stack size 16 bytes, io_tasks.o(.text))

[Stack]

- Max Depth = 16
- Call Chain = SmsTask_SetMessage

[Calls]

- >> strlen
- >> __aeabi_memcpy

[Called By]

- >> SosTask_SendSms
- >> Sos_Task

SmsTask_IsIdle (Thumb, 24 bytes, Stack size 0 bytes, io_tasks.o(.text))

[Called By]

- >> Sos_Task
- >> Gprs_Task

SmsTask_IsModemBusy (Thumb, 32 bytes, Stack size 0 bytes, io_tasks.o(.text))

[Called By]

- >> SmsTask_Stop
- >> IoTask_IsModemBusy

IoTask_IsModemBusy (Thumb, 26 bytes, Stack size 4 bytes, io_tasks.o(.text))

[Stack]

- Max Depth = 4
- Call Chain = IoTask_IsModemBusy

[Calls]

- >> SmsTask_IsModemBusy
- >> VoiceCallTask_IsModemBusy

[Called By]

- >> UploadConfigTask_Retry
- >> UploadConfig_Task
- >> SendPowerCmd_GprsTask
- >> SendPowerCmdTask_Retry
- >> SendGpsData_GprsTask
- >> SendGpsDataTask_Retry

SmsTask_IsSmsSent (Thumb, 22 bytes, Stack size 0 bytes, io_tasks.o(.text))

[Called By]

- >> Sos_Task

SmsTask_GetPhase (Thumb, 6 bytes, Stack size 0 bytes, io_tasks.o(.text))

[Called By]

- >> Sos_Task
- >> AppRun
- >> SysSleep

SmsTask_Stop (Thumb, 26 bytes, Stack size 8 bytes, io_tasks.o(.text))

[Stack]

- Max Depth = 8
- Call Chain = SmsTask_Stop

[Calls]

- >> SmsTask_IsModemBusy
- >> uart_putchar

[Called By]

- >> SosTask_End
- >> Sos_Task

UploadConfigTask_Init (Thumb, 80 bytes, Stack size 8 bytes, upload_config_task.o(.text))

[Stack]

- Max Depth = 12
- Call Chain = UploadConfigTask_Init ⇒ InitTimeout

[Calls]

- >> InitTimeout

[Called By]

- >> UploadConfigTask_WaitRetry
- >> UploadConfigTask_StopAll
- >> UploadConfigTask_Start
- >> GprsTask_Init

UploadConfigTask_Start (Thumb, 88 bytes, Stack size 8 bytes, upload_config_task.o(.text), UNUSED)

[Calls]

- >> UploadConfigTask_Init
- >> GprsTask_Stop
- >> SosTask_GetPhase
- >> CheckTimeout

UploadConfigTask_IsWaitingForRetry (Thumb, 6 bytes, Stack size 0 bytes, upload_config_task.o(.text))

[Called By]

- >> Gprs_Task

UploadConfigTask_IsWaitingForRetryTimedOut (Thumb, 20 bytes, Stack size 8 bytes, upload_config_task.o(.text))

[Stack]

- Max Depth = 24
- Call Chain = UploadConfigTask_IsWaitingForRetryTimedOut ⇒ CheckTimeout

[Calls]

- >> CheckTimeout

[Called By]

- >> Gprs_Task

UploadConfigTask_GetPhase (Thumb, 6 bytes, Stack size 0 bytes, upload_config_task.o(.text))

[Called By]

- >> GprsTask_GetPhase

UploadConfigTask_SetPhase (Thumb, 6 bytes, Stack size 0 bytes, upload_config_task.o(.text), UNUSED)

[Called By]

- >> GprsTask_SetPhase

UploadConfigTask_WakeUp (Thumb, 16 bytes, Stack size 0 bytes, upload_config_task.o(.text), UNUSED)

[Called By]

- >> GprsTask_WakeUp

UploadConfigTask_Retry (Thumb, 40 bytes, Stack size 8 bytes, upload_config_task.o(.text))

[Stack]

- Max Depth = 12 + In Cycle
- Call Chain = UploadConfigTask_Retry ⇒ GprsTask_Stop (Cycle)

[Calls]

- >> IoTask_IsModemBusy
- >> GprsTask_Stop
- >> InitTimeout

[Called By]

- >> UploadConfig_Task

UploadConfigTask_Stop (Thumb, 8 bytes, Stack size 0 bytes, upload_config_task.o(.text))

[Called By]

- >> GprsTask_StopTask

UploadConfigTask_StopAll (Thumb, 14 bytes, Stack size 8 bytes, upload_config_task.o(.text), UNUSED)

[Calls]

- >> UploadConfigTask_Init

UploadConfigTask_WaitRetry (Thumb, 26 bytes, Stack size 8 bytes, upload_config_task.o(.text))

[Stack]

- Max Depth = 20 + In Cycle
- Call Chain = UploadConfigTask_WaitRetry ⇒ GprsTask_Stop (Cycle)

[Calls]

- >> UploadConfigTask_Init
- >> GprsTask_Stop
- >> InitTimeout

[Called By]

- >> UploadConfig_Task

UploadConfig_Task (Thumb, 2772 bytes, Stack size 56 bytes, upload_config_task.o(.text))

[Stack]

- Max Depth = 384 + In Cycle
- Call Chain = UploadConfig_Task ⇒ GprsTask_Stop (Cycle)

[Calls]

- >> DCFG_Parser
- >> DCFG_Add
- >> UploadConfigTask_WaitRetry
- >> UploadConfigTask_Retry
- >> uart_putchar
- >> ModemCmdTask_SetCriticalCmd
- >> ModemCmdTask_SendCmd
- >> ModemCmdTask_IsCriticalCmd
- >> ModemCmdTask_GetPhase
- >> MODEM_GetSocket
- >> MODEM_DisconectSocket
- >> MODEM_CheckGPRSDataOut
- >> IoTask_IsModemBusy
- >> GPRS_CmdRecvData
- >> GprsTask_Stop
- >> ModemCmdTask_IsIdle
- >> MODEM_SendCommand
- >> InitTimeout
- >> GsmTask_Init
- >> GsmTask_GetPhase
- >> DelayMs
- >> CheckTimeout
- >> __aeabi_memcpy

[Called By]

- >> Gprs_Task

GpsTask_Init (Thumb, 26 bytes, Stack size 0 bytes, gps_task.o(.text))

[Called By]

- >> main

GpsTask_GetPhase (Thumb, 6 bytes, Stack size 0 bytes, gps_task.o(.text))

[Called By]

- >> AppRun
- >> SysSleep

GpsTask_EnableGps (Thumb, 14 bytes, Stack size 0 bytes, gps_task.o(.text))

[Called By]

- >> CMD_CfgParse
- >> TrackerTask
- >> Sos_Task
- >> Io_Task

GpsTask_SetPhase (Thumb, 6 bytes, Stack size 0 bytes, gps_task.o(.text), UNUSED)

GpsTask_Control (Thumb, 924 bytes, Stack size 32 bytes, gps_task.o(.text))

[Stack]

- Max Depth = 496
- Call Chain = GpsTask_Control ⇒ GPS_GetInfo ⇒ nmea_parse_GPRMC ⇒ _nmea_parse_time ⇒ nmea_scanf ⇒ nmea_atof ⇒ strtod ⇒ __strtod_int ⇒ _local_sscanf ⇒ _scanf_real

[Calls]

- >> __ARM_common_switch8
- >> nmea_zero_INFO
- >> formatLng
- >> formatLat
- >> __aeabi_f2d
- >> __aeabi_d2f
- >> __aeabi_cdrcmple
- >> __aeabi_cdcmple
- >> __aeabi_cdcmpeq
- >> UpdateRtcTime
- >> TIME_GetSec
- >> TIME_FromGps
- >> GPS_GetInfo
- >> DB_U32Save
- >> DB_FloatToU32
- >> __aeabi_memcpy4

[Called By]

- >> TrackerTask

start (Thumb, 32 bytes, Stack size 8 bytes, start.o(.text))

[Stack]

- Max Depth = 44
- Call Chain = start ⇒ uart_init ⇒ __aeabi_uidivmod

[Calls]

- >> uart_init
- >> sysinit
- >> outSRS

[Called By]

- >> main

cpu_identify (Thumb, 254 bytes, Stack size 4 bytes, start.o(.text), UNUSED)

[Calls]

- >> __ARM_common_switch8

flash_identify (Thumb, 72 bytes, Stack size 0 bytes, start.o(.text), UNUSED)

clk_out_init (Thumb, 22 bytes, Stack size 0 bytes, sysinit.o(.text))

[Called By]

- >> sysinit

sysinit (Thumb, 154 bytes, Stack size 8 bytes, sysinit.o(.text))

[Stack]

- Max Depth = 36
- Call Chain = sysinit ⇒ __aeabi_idivmod ⇒ __aeabi_uidivmod

[Calls]

- >> clk_out_init
- >> __aeabi_idivmod
- >> __aeabi_uidivmod

[Called By]

- >> start

enable_abort_button (Thumb, 36 bytes, Stack size 0 bytes, sysinit.o(.text), UNUSED)

SystemInit (Thumb, 170 bytes, Stack size 0 bytes, system_mkl25z4.o(.text))
[Address Reference Count : 1]

- startup_mkl25z4.o(.text)

SystemCoreClockUpdate (Thumb, 310 bytes, Stack size 16 bytes, system_mkl25z4.o(.text), UNUSED)

[Calls]

- >> __ARM_common_switch8
- >> __aeabi_uidivmod

NMI_Handler (Thumb, 66 bytes, Stack size 0 bytes, nmi_isr_handler.o(.text))
[Address Reference Count : 1]

- startup_mkl25z4.o(RESET)

enable_NMI_button (Thumb, 8 bytes, Stack size 0 bytes, nmi_isr_handler.o(.text), UNUSED)

Reset_Handler (Thumb, 8 bytes, Stack size 0 bytes, startup_mkl25z4.o(.text))
[Address Reference Count : 1]

- startup_mkl25z4.o(RESET)

SVC_Handler (Thumb, 2 bytes, Stack size 0 bytes, startup_mkl25z4.o(.text))

[Calls]

- >> SVC_Handler

[Called By]

- >> SVC_Handler

[Address Reference Count : 1]

- startup_mkl25z4.o(RESET)

PendSV_Handler (Thumb, 2 bytes, Stack size 0 bytes, startup_mkl25z4.o(.text))

[Calls]

- >> PendSV_Handler

[Called By]

- >> PendSV_Handler

[Address Reference Count : 1]

- startup_mkl25z4.o(RESET)

ADC0_IRQHandler (Thumb, 0 bytes, Stack size 0 bytes, startup_mkl25z4.o(.text))

[Calls]

- >> ADC0_IRQHandler

[Called By]

- >> ADC0_IRQHandler

[Address Reference Count : 1]

- startup_mkl25z4.o(RESET)

CMP0_IRQHandler (Thumb, 0 bytes, Stack size 0 bytes, startup_mkl25z4.o(.text))
[Address Reference Count : 1]

- startup_mkl25z4.o(RESET)

DAC0_IRQHandler (Thumb, 0 bytes, Stack size 0 bytes, startup_mkl25z4.o(.text))
[Address Reference Count : 1]

- startup_mkl25z4.o(RESET)

DMA0_IRQHandler (Thumb, 0 bytes, Stack size 0 bytes, startup_mkl25z4.o(.text))
[Address Reference Count : 1]

- startup_mkl25z4.o(RESET)

DMA1_IRQHandler (Thumb, 0 bytes, Stack size 0 bytes, startup_mkl25z4.o(.text))
[Address Reference Count : 1]

- startup_mkl25z4.o(RESET)

DMA2_IRQHandler (Thumb, 0 bytes, Stack size 0 bytes, startup_mkl25z4.o(.text))
[Address Reference Count : 1]

- startup_mkl25z4.o(RESET)

DMA3_IRQHandler (Thumb, 0 bytes, Stack size 0 bytes, startup_mkl25z4.o(.text))
[Address Reference Count : 1]

- startup_mkl25z4.o(RESET)

DefaultISR (Thumb, 0 bytes, Stack size 0 bytes, startup_mkl25z4.o(.text), UNUSED)

FTFA_IRQHandler (Thumb, 0 bytes, Stack size 0 bytes, startup_mkl25z4.o(.text))
[Address Reference Count : 1]

- startup_mkl25z4.o(RESET)

I2C0_IRQHandler (Thumb, 0 bytes, Stack size 0 bytes, startup_mkl25z4.o(.text))
[Address Reference Count : 1]

- startup_mkl25z4.o(RESET)

I2C1_IRQHandler (Thumb, 0 bytes, Stack size 0 bytes, startup_mkl25z4.o(.text))
[Address Reference Count : 1]

- startup_mkl25z4.o(RESET)

LVD_LVW_IRQHandler (Thumb, 0 bytes, Stack size 0 bytes, startup_mkl25z4.o(.text))
[Address Reference Count : 1]

- startup_mkl25z4.o(RESET)

MCG_IRQHandler (Thumb, 0 bytes, Stack size 0 bytes, startup_mkl25z4.o(.text))
[Address Reference Count : 1]

- startup_mkl25z4.o(RESET)

PIT_IRQHandler (Thumb, 0 bytes, Stack size 0 bytes, startup_mkl25z4.o(.text))
[Address Reference Count : 1]

- startup_mkl25z4.o(RESET)

PORTA_IRQHandler (Thumb, 0 bytes, Stack size 0 bytes, startup_mkl25z4.o(.text))
[Address Reference Count : 1]

- startup_mkl25z4.o(RESET)

RTC_IRQHandler (Thumb, 0 bytes, Stack size 0 bytes, startup_mkl25z4.o(.text))
[Address Reference Count : 1]

- startup_mkl25z4.o(RESET)

RTC_Seconds_IRQHandler (Thumb, 0 bytes, Stack size 0 bytes, startup_mkl25z4.o(.text))
[Address Reference Count : 1]

- startup_mkl25z4.o(RESET)

Reserved20_IRQHandler (Thumb, 0 bytes, Stack size 0 bytes, startup_mkl25z4.o(.text))
[Address Reference Count : 1]

- startup_mkl25z4.o(RESET)

Reserved39_IRQHandler (Thumb, 0 bytes, Stack size 0 bytes, startup_mkl25z4.o(.text))
[Address Reference Count : 1]

- startup_mkl25z4.o(RESET)

Reserved45_IRQHandler (Thumb, 0 bytes, Stack size 0 bytes, startup_mkl25z4.o(.text))
[Address Reference Count : 1]

- startup_mkl25z4.o(RESET)

SPI0_IRQHandler (Thumb, 0 bytes, Stack size 0 bytes, startup_mkl25z4.o(.text))
[Address Reference Count : 1]

- startup_mkl25z4.o(RESET)

SPI1_IRQHandler (Thumb, 0 bytes, Stack size 0 bytes, startup_mkl25z4.o(.text))
[Address Reference Count : 1]

- startup_mkl25z4.o(RESET)

TSI0_IRQHandler (Thumb, 0 bytes, Stack size 0 bytes, startup_mkl25z4.o(.text))
[Address Reference Count : 1]

- startup_mkl25z4.o(RESET)

UART2_IRQHandler (Thumb, 0 bytes, Stack size 0 bytes, startup_mkl25z4.o(.text))
[Address Reference Count : 1]

- startup_mkl25z4.o(RESET)

llwu_configure (Thumb, 348 bytes, Stack size 12 bytes, llwu.o(.text))

[Stack]

- Max Depth = 12
- Call Chain = llwu_configure

[Called By]

- >> main
- >> PIN_InterruptInit

llwu_configure_filter (Thumb, 70 bytes, Stack size 12 bytes, llwu.o(.text), UNUSED)

LLW_IRQHandler (Thumb, 458 bytes, Stack size 8 bytes, llwu.o(.text))

[Stack]

- Max Depth = 40
- Call Chain = LLW_IRQHandler ⇒ LPTimerTask ⇒ LedControl ⇒ GsmLedControl ⇒ GprsTask_GetPhase

[Calls]

- >> LPTimerTask

[Address Reference Count : 1]

- startup_mkl25z4.o(RESET)

pll_init (Thumb, 714 bytes, Stack size 56 bytes, mcg.o(.text), UNUSED)

[Calls]

- >> __aeabi_idivmod

new_pll_freq (Thumb, 488 bytes, Stack size 48 bytes, mcg.o(.text), UNUSED)

[Calls]

- >> __aeabi_idivmod

pee_pbe (Thumb, 108 bytes, Stack size 0 bytes, mcg.o(.text))

[Called By]

- >> vlp_clock_config
- >> PEE_to_BLPE

pbe_pee (Thumb, 194 bytes, Stack size 24 bytes, mcg.o(.text))

[Stack]

- Max Depth = 52
- Call Chain = pbe_pee ⇒ __aeabi_idivmod ⇒ __aeabi_uidivmod

[Calls]

- >> __aeabi_idivmod

[Called By]

- >> BLPE_to_PEE
- >> LowPowerModes
- >> vlp_clock_config

pbe_fbe (Thumb, 110 bytes, Stack size 0 bytes, mcg.o(.text))

[Called By]

- >> vlp_clock_config

fbe_pbe (Thumb, 282 bytes, Stack size 40 bytes, mcg.o(.text))

[Stack]

- Max Depth = 68
- Call Chain = fbe_pbe ⇒ __aeabi_idivmod ⇒ __aeabi_uidivmod

[Calls]

- >> __aeabi_idivmod

[Called By]

- >> vlp_clock_config

pbe_blpe (Thumb, 66 bytes, Stack size 0 bytes, mcg.o(.text))

[Called By]

- >> PEE_to_BLPE

blpe_pbe (Thumb, 268 bytes, Stack size 32 bytes, mcg.o(.text))

[Stack]

- Max Depth = 60
- Call Chain = blpe_pbe ⇒ __aeabi_idivmod ⇒ __aeabi_uidivmod

[Calls]

- >> __aeabi_idivmod

[Called By]

- >> BLPE_to_PEE
- >> vlp_clock_config

blpe_fbe (Thumb, 112 bytes, Stack size 0 bytes, mcg.o(.text))

[Called By]

- >> vlp_clock_config

fbe_blpe (Thumb, 66 bytes, Stack size 0 bytes, mcg.o(.text))

[Called By]

- >> vlp_clock_config

fll_freq (Thumb, 326 bytes, Stack size 0 bytes, mcg.o(.text))

[Called By]

- >> fbi_fei
- >> fee_fei
- >> fei_fee
- >> fbi_fee
- >> fbe_fee
- >> fbe_fei

fbe_fei (Thumb, 212 bytes, Stack size 20 bytes, mcg.o(.text), UNUSED)

[Calls]

- >> fll_freq

fei_fbe (Thumb, 474 bytes, Stack size 20 bytes, mcg.o(.text))

[Stack]

- Max Depth = 20
- Call Chain = fei_fbe

[Called By]

- >> vlp_clock_config

fbe_fee (Thumb, 194 bytes, Stack size 24 bytes, mcg.o(.text), UNUSED)

[Calls]

- >> fll_freq
- >> __aeabi_idivmod

fee_fbe (Thumb, 106 bytes, Stack size 0 bytes, mcg.o(.text), UNUSED)

fbe_fbi (Thumb, 376 bytes, Stack size 24 bytes, mcg.o(.text))

[Stack]

- Max Depth = 52
- Call Chain = fbe_fbi ⇒ __aeabi_idivmod ⇒ __aeabi_uidivmod

[Calls]

- >> __aeabi_idivmod

[Called By]

- >> vlp_clock_config

fbi_fbe (Thumb, 462 bytes, Stack size 20 bytes, mcg.o(.text))

[Stack]

- Max Depth = 20
- Call Chain = fbi_fbe

[Called By]

- >> vlp_clock_config

fbi_blpi (Thumb, 80 bytes, Stack size 16 bytes, mcg.o(.text))

[Stack]

- Max Depth = 44
- Call Chain = fbi_blpi ⇒ __aeabi_idivmod ⇒ __aeabi_uidivmod

[Calls]

- >> __aeabi_idivmod

[Called By]

- >> vlp_clock_config

blpi_fbi (Thumb, 100 bytes, Stack size 16 bytes, mcg.o(.text))

[Stack]

- Max Depth = 44
- Call Chain = blpi_fbi ⇒ __aeabi_idivmod ⇒ __aeabi_uidivmod

[Calls]

- >> __aeabi_idivmod

[Called By]

- >> vlp_clock_config

fbi_fee (Thumb, 546 bytes, Stack size 40 bytes, mcg.o(.text), UNUSED)

[Calls]

- >> fll_freq
- >> __aeabi_idivmod

fee_fbi (Thumb, 354 bytes, Stack size 24 bytes, mcg.o(.text), UNUSED)

[Calls]

- >> __aeabi_idivmod

fbi_fei (Thumb, 202 bytes, Stack size 20 bytes, mcg.o(.text))

[Stack]

- Max Depth = 20
- Call Chain = fbi_fei

[Calls]

- >> fll_freq

[Called By]

- >> vlp_clock_config

fei_fbi (Thumb, 308 bytes, Stack size 24 bytes, mcg.o(.text))

[Stack]

- Max Depth = 52
- Call Chain = fei_fbi ⇒ __aeabi_idivmod ⇒ __aeabi_uidivmod

[Calls]

- >> __aeabi_idivmod

[Called By]

- >> vlp_clock_config

fei_fee (Thumb, 466 bytes, Stack size 48 bytes, mcg.o(.text), UNUSED)

[Calls]

- >> fll_freq
- >> __aeabi_idivmod

fee_fei (Thumb, 144 bytes, Stack size 16 bytes, mcg.o(.text), UNUSED)

[Calls]

- >> fll_freq

what_mcg_mode (Thumb, 344 bytes, Stack size 0 bytes, mcg.o(.text))

[Called By]

- >> atc
- >> LowPowerModes
- >> vlp_clock_config

atc (Thumb, 488 bytes, Stack size 72 bytes, mcg.o(.text))

[Stack]

- Max Depth = 100
- Call Chain = atc ⇒ __aeabi_idivmod ⇒ __aeabi_uidivmod

[Calls]

- >> what_mcg_mode
- >> __aeabi_i2f
- >> __aeabi_fmul
- >> __aeabi_fdiv
- >> __aeabi_f2uiz
- >> __aeabi_idivmod
- >> __aeabi_uidivmod

[Called By]

- >> vlp_clock_config
- >> PEE_to_BLPE

clk_monitor_0 (Thumb, 32 bytes, Stack size 0 bytes, mcg.o(.text), UNUSED)

chk_for_resistor (Thumb, 202 bytes, Stack size 8 bytes, mcg.o(.text), UNUSED)

outSRS (Thumb, 2 bytes, Stack size 0 bytes, rcm.o(.text))

[Called By]

- >> start

sleep (Thumb, 16 bytes, Stack size 0 bytes, smc.o(.text), UNUSED)

deepsleep (Thumb, 16 bytes, Stack size 0 bytes, smc.o(.text), UNUSED)

enter_wait (Thumb, 16 bytes, Stack size 0 bytes, smc.o(.text), UNUSED)

enter_stop (Thumb, 62 bytes, Stack size 0 bytes, smc.o(.text), UNUSED)

enter_vlpr (Thumb, 104 bytes, Stack size 0 bytes, smc.o(.text))

[Called By]

- >> LowPowerModes

exit_vlpr (Thumb, 64 bytes, Stack size 0 bytes, smc.o(.text))

[Called By]

- >> LowPowerModes
- >> vlp_clock_config

enter_vlps (Thumb, 58 bytes, Stack size 8 bytes, smc.o(.text), UNUSED)

enter_lls (Thumb, 58 bytes, Stack size 8 bytes, smc.o(.text))

[Stack]

- Max Depth = 8
- Call Chain = enter_lls

[Called By]

- >> LowPowerModes

enter_vlls3 (Thumb, 62 bytes, Stack size 8 bytes, smc.o(.text), UNUSED)

enter_vlls2 (Thumb, 62 bytes, Stack size 8 bytes, smc.o(.text), UNUSED)

enter_vlls1 (Thumb, 62 bytes, Stack size 8 bytes, smc.o(.text), UNUSED)

enter_vlls0 (Thumb, 136 bytes, Stack size 0 bytes, smc.o(.text), UNUSED)

enter_vlls0_nopor (Thumb, 124 bytes, Stack size 8 bytes, smc.o(.text), UNUSED)

uart_init (Thumb, 152 bytes, Stack size 24 bytes, uart.o(.text))

[Stack]

- Max Depth = 36
- Call Chain = uart_init ⇒ __aeabi_uidivmod

[Calls]

- >> RINGBUF_Init
- >> NVIC_DisableIRQ
- >> NVIC_EnableIRQ
- >> NVIC_SetPriority
- >> __aeabi_uidivmod

[Called By]

- >> start
- >> SetLowPowerModes
- >> MODEM_Init
- >> Gsm_Task
- >> main

uart_getchar (Thumb, 16 bytes, Stack size 0 bytes, uart.o(.text), UNUSED)

uart_putchar (Thumb, 14 bytes, Stack size 0 bytes, uart.o(.text))

[Called By]

- >> SmsTask_Pause
- >> SmsTask_Stop
- >> SmsTask_ClearAllSms
- >> uart_putstr
- >> UploadConfig_Task
- >> ModemCmdTask_Cancel
- >> SendPowerCmd_GprsTask
- >> SendGpsData_GprsTask
- >> VoiceCall_Task
- >> Sos_Task
- >> Sms_Task
- >> MODEM_SendCommand
- >> SendSMS

uart_putstr (Thumb, 26 bytes, Stack size 12 bytes, uart.o(.text))

[Stack]

- Max Depth = 12
- Call Chain = uart_putstr

[Calls]

- >> uart_putchar

[Called By]

- >> MODEM_GetCSQ
- >> MODEM_CheckGPRSDataOut
- >> GetIMEI
- >> GPRS_CmdRecvData
- >> Sms_Task
- >> SMS_Manage
- >> ModemCmd_Task
- >> MODEM_SendCommand
- >> Gsm_Task
- >> SendSMS
- >> MODEM_CloseSocket

uart_getchar_present (Thumb, 10 bytes, Stack size 0 bytes, uart.o(.text), UNUSED)

uart0_init (Thumb, 404 bytes, Stack size 56 bytes, uart.o(.text))

[Stack]

- Max Depth = 68
- Call Chain = uart0_init ⇒ __aeabi_uidivmod

[Calls]

- >> RINGBUF_Init
- >> NVIC_DisableIRQ
- >> NVIC_EnableIRQ
- >> NVIC_SetPriority
- >> __aeabi_uidivmod

[Called By]

- >> SetLowPowerModes
- >> main

uart0_getchar (Thumb, 16 bytes, Stack size 0 bytes, uart.o(.text), UNUSED)

uart0_putchar (Thumb, 14 bytes, Stack size 0 bytes, uart.o(.text), UNUSED)

[Called By]

- >> uart0_putstr

uart0_putstr (Thumb, 26 bytes, Stack size 12 bytes, uart.o(.text), UNUSED)

[Calls]

- >> uart0_putchar

uart0_getchar_present (Thumb, 10 bytes, Stack size 0 bytes, uart.o(.text), UNUSED)

UART0_IRQHandler (Thumb, 106 bytes, Stack size 8 bytes, uart.o(.text))

[Stack]

- Max Depth = 24
- Call Chain = UART0_IRQHandler ⇒ GPS_ComnandParser

[Calls]

- >> RINGBUF_Put
- >> GPS_ComnandParser

[Address Reference Count : 1]

- startup_mkl25z4.o(RESET)

UART1_IRQHandler (Thumb, 168 bytes, Stack size 8 bytes, uart.o(.text))

[Stack]

- Max Depth = 72
- Call Chain = UART1_IRQHandler ⇒ AT_ComnandParser ⇒ StrComnandParser ⇒ StrParserCtl

[Calls]

- >> RINGBUF_Put
- >> AT_ComnandParser

[Address Reference Count : 1]

- startup_mkl25z4.o(RESET)

SPI_Init (Thumb, 146 bytes, Stack size 0 bytes, spi.o(.text))

[Called By]

- >> SST25_Init
- >> PedometerTaskInit

halSpiWriteByte (Thumb, 66 bytes, Stack size 8 bytes, spi.o(.text))

[Stack]

- Max Depth = 8
- Call Chain = halSpiWriteByte

[Called By]

- >> SST25_Read
- >> _SST25_Write
- >> SST25_Erase
- >> SST25__GlobalProtect
- >> SST25__WriteEnable
- >> SST25__Status
- >> xl362FifoRead
- >> xl362Read
- >> xl362Write

Flash_Init (Thumb, 78 bytes, Stack size 0 bytes, flash_ftfa.o(.text))

[Called By]

- >> SetLowPowerModes
- >> CFG_Load

Flash_SectorErase (Thumb, 138 bytes, Stack size 16 bytes, flash_ftfa.o(.text))

[Stack]

- Max Depth = 16
- Call Chain = Flash_SectorErase

[Calls]

- >> SpSub (via Veneer)

[Called By]

- >> CFG_Save
- >> CFG_Write

Flash_ByteProgram (Thumb, 190 bytes, Stack size 32 bytes, flash_ftfa.o(.text))

[Stack]

- Max Depth = 32
- Call Chain = Flash_ByteProgram

[Calls]

- >> SpSub (via Veneer)

[Called By]

- >> CFG_Save
- >> CFG_Write

USB_ResetCore (Thumb, 32 bytes, Stack size 0 bytes, usbcore.o(.text))

[Called By]

- >> USB_Suspend_Event
- >> USB_Reset_Event

USB_SetupStage (Thumb, 12 bytes, Stack size 8 bytes, usbcore.o(.text))

[Stack]

- Max Depth = 32
- Call Chain = USB_SetupStage ⇒ USB_ReadEP

[Calls]

- >> USB_ReadEP

[Called By]

- >> USB_EndPoint0

USB_DataInStage (Thumb, 52 bytes, Stack size 8 bytes, usbcore.o(.text))

[Stack]

- Max Depth = 28
- Call Chain = USB_DataInStage ⇒ USB_WriteEP

[Calls]

- >> USB_WriteEP

[Called By]

- >> USB_EndPoint0

USB_DataOutStage (Thumb, 34 bytes, Stack size 8 bytes, usbcore.o(.text))

[Stack]

- Max Depth = 32
- Call Chain = USB_DataOutStage ⇒ USB_ReadEP

[Calls]

- >> USB_ReadEP

[Called By]

- >> USB_EndPoint0

USB_StatusInStage (Thumb, 14 bytes, Stack size 8 bytes, usbcore.o(.text))

[Stack]

- Max Depth = 28
- Call Chain = USB_StatusInStage ⇒ USB_WriteEP

[Calls]

- >> USB_WriteEP

[Called By]

- >> USB_EndPoint0

USB_StatusOutStage (Thumb, 12 bytes, Stack size 8 bytes, usbcore.o(.text))

[Stack]

- Max Depth = 32
- Call Chain = USB_StatusOutStage ⇒ USB_ReadEP

[Calls]

- >> USB_ReadEP

[Called By]

- >> USB_EndPoint0

USB_EndPoint0 (Thumb, 756 bytes, Stack size 8 bytes, usbcore.o(.text))

[Stack]

- Max Depth = 120
- Call Chain = USB_EndPoint0 ⇒ HID_SetReport ⇒ SetOutReport ⇒ USB_ReadEP

[Calls]

- >> __ARM_common_switch8
- >> USB_SetStallEP
- >> USB_SetAddress
- >> USB_DirCtrlEP
- >> USB_Configure_Event
- >> USB_ClrStallEP
- >> HID_SetReport
- >> HID_SetProtocol
- >> HID_SetIdle
- >> HID_GetReport
- >> HID_GetProtocol
- >> HID_GetIdle
- >> USB_ReqSetInterface
- >> USB_ReqSetConfiguration
- >> USB_ReqSetClrFeature
- >> USB_ReqGetStatus
- >> USB_ReqGetDescriptor
- >> USB_StatusOutStage
- >> USB_StatusInStage
- >> USB_DataOutStage
- >> USB_DataInStage
- >> USB_SetupStage

[Address Reference Count : 1]

- usbuser.o(.constdata)

USB_IntrEna (Thumb, 24 bytes, Stack size 8 bytes, usbhw.o(.text))

[Stack]

- Max Depth = 16
- Call Chain = USB_IntrEna ⇒ NVIC_SetPriority

[Calls]

- >> NVIC_SetPriority

[Called By]

- >> USB_Init

USB_Init (Thumb, 168 bytes, Stack size 8 bytes, usbhw.o(.text))

[Stack]

- Max Depth = 24
- Call Chain = USB_Init ⇒ USB_IntrEna ⇒ NVIC_SetPriority

[Calls]

- >> USB_IntrEna

[Called By]

- >> SetLowPowerModes
- >> Io_Task
- >> main
- >> SysSleep
- >> SysPwrOff

USB_Connect (Thumb, 58 bytes, Stack size 0 bytes, usbhw.o(.text))

[Called By]

- >> SetLowPowerModes
- >> Io_Task
- >> main
- >> SysSleep
- >> SysPwrOff

USB_Reset (Thumb, 94 bytes, Stack size 0 bytes, usbhw.o(.text))

[Called By]

- >> USB0_IRQHandler

USB_Suspend (Thumb, 18 bytes, Stack size 0 bytes, usbhw.o(.text))

[Called By]

- >> USB0_IRQHandler

USB_Resume (Thumb, 18 bytes, Stack size 0 bytes, usbhw.o(.text))

[Called By]

- >> USB0_IRQHandler

USB_WakeUp (Thumb, 58 bytes, Stack size 0 bytes, usbhw.o(.text), UNUSED)

USB_WakeUpCfg (Thumb, 2 bytes, Stack size 0 bytes, usbhw.o(.text))

[Called By]

- >> USB_ReqSetClrFeature

USB_SetAddress (Thumb, 12 bytes, Stack size 0 bytes, usbhw.o(.text))

[Called By]

- >> USB_EndPoint0

USB_Configure (Thumb, 2 bytes, Stack size 0 bytes, usbhw.o(.text))

[Called By]

- >> USB_ReqSetConfiguration

USB_ResetEP (Thumb, 140 bytes, Stack size 0 bytes, usbhw.o(.text))

[Called By]

- >> USB_ConfigEP
- >> USB_ClrStallEP
- >> USB_ReqSetInterface
- >> USB_ReqSetConfiguration

USB_ConfigEP (Thumb, 36 bytes, Stack size 16 bytes, usbhw.o(.text))

[Stack]

- Max Depth = 16
- Call Chain = USB_ConfigEP

[Calls]

- >> USB_ResetEP

[Called By]

- >> USB_ReqSetInterface
- >> USB_ReqSetConfiguration

USB_DirCtrlEP (Thumb, 2 bytes, Stack size 0 bytes, usbhw.o(.text))

[Called By]

- >> USB_EndPoint0

USB_EnableEP (Thumb, 54 bytes, Stack size 0 bytes, usbhw.o(.text))

[Called By]

- >> USB_ReqSetInterface
- >> USB_ReqSetConfiguration

USB_DisableEP (Thumb, 54 bytes, Stack size 0 bytes, usbhw.o(.text))

[Called By]

- >> USB_ReqSetInterface
- >> USB_ReqSetConfiguration

USB_SetStallEP (Thumb, 26 bytes, Stack size 0 bytes, usbhw.o(.text))

[Called By]

- >> USB_ReqSetClrFeature
- >> USB_EndPoint0

USB_ClrStallEP (Thumb, 36 bytes, Stack size 8 bytes, usbhw.o(.text))

[Stack]

- Max Depth = 8
- Call Chain = USB_ClrStallEP

[Calls]

- >> USB_ResetEP

[Called By]

- >> USB_ReqSetClrFeature
- >> USB_EndPoint0

USB_ClearEPBuf (Thumb, 2 bytes, Stack size 0 bytes, usbhw.o(.text), UNUSED)

USB_ReadEP (Thumb, 260 bytes, Stack size 24 bytes, usbhw.o(.text))

[Stack]

- Max Depth = 24
- Call Chain = USB_ReadEP

[Called By]

- >> SetOutReport
- >> USB_StatusOutStage
- >> USB_DataOutStage
- >> USB_SetupStage

USB_WriteEP (Thumb, 94 bytes, Stack size 20 bytes, usbhw.o(.text))

[Stack]

- Max Depth = 20
- Call Chain = USB_WriteEP

[Called By]

- >> GetInReport
- >> USB_StatusInStage
- >> USB_DataInStage
- >> vHID_Task

USB_GetFrame (Thumb, 16 bytes, Stack size 0 bytes, usbhw.o(.text), UNUSED)

USB0_IRQHandler (Thumb, 350 bytes, Stack size 24 bytes, usbhw.o(.text))

[Stack]

- Max Depth = 32
- Call Chain = USB0_IRQHandler ⇒ USB_Reset_Event

[Calls]

- >> USB_Resume_Event
- >> USB_Reset_Event
- >> USB_Resume
- >> USB_Suspend
- >> USB_Reset

[Address Reference Count : 1]

- startup_mkl25z4.o(RESET)

USB_Reset_Event (Thumb, 8 bytes, Stack size 8 bytes, usbuser.o(.text))

[Stack]

- Max Depth = 8
- Call Chain = USB_Reset_Event

[Calls]

- >> USB_ResetCore

[Called By]

- >> USB0_IRQHandler

USB_Suspend_Event (Thumb, 8 bytes, Stack size 8 bytes, usbuser.o(.text), UNUSED)

[Calls]

- >> USB_ResetCore

USB_Resume_Event (Thumb, 2 bytes, Stack size 0 bytes, usbuser.o(.text))

[Called By]

- >> USB0_IRQHandler

USB_Configure_Event (Thumb, 16 bytes, Stack size 8 bytes, usbuser.o(.text))

[Stack]

- Max Depth = 108
- Call Chain = USB_Configure_Event ⇒ GetInReport ⇒ USB_WriteEP

[Calls]

- >> GetInReport

[Called By]

- >> USB_EndPoint0

USB_EndPoint1 (Thumb, 30 bytes, Stack size 8 bytes, usbuser.o(.text))

[Stack]

- Max Depth = 112
- Call Chain = USB_EndPoint1 ⇒ SetOutReport ⇒ USB_ReadEP

[Calls]

- >> SetOutReport
- >> GetInReport

[Address Reference Count : 1]

- usbuser.o(.constdata)

RINGBUF_Init (Thumb, 34 bytes, Stack size 0 bytes, ringbuf.o(.text))

[Called By]

- >> DTMF_Init
- >> uart_init
- >> uart0_init
- >> TPM0_Init
- >> AUDIO_Init
- >> AT_CmdProcessInit

RINGBUF_Put (Thumb, 42 bytes, Stack size 8 bytes, ringbuf.o(.text))

[Stack]

- Max Depth = 8
- Call Chain = RINGBUF_Put

[Called By]

- >> SetOutReport
- >> UART1_IRQHandler
- >> UART0_IRQHandler
- >> DTMF_Task
- >> AudioControler
- >> CfgUSBSendData
- >> DbgCfgPrintf
- >> GPRS_GetLength
- >> SMS_Process

RINGBUF_Get (Thumb, 46 bytes, Stack size 0 bytes, ringbuf.o(.text))

[Called By]

- >> GetDtmfKey
- >> MODEM_GetCSQ
- >> MODEM_CheckGPRSDataOut
- >> GPRS_CmdRecvData
- >> SMS_Manage
- >> ModemCmd_Task
- >> MODEM_SendCommand
- >> GetInReport
- >> TPM1_IRQHandler
- >> vHID_Task
- >> CfgProcessData
- >> MODEM_Gets
- >> MODEM_CheckResponse
- >> MODEM_CloseSocket
- >> MODEM_FlushBuffer

RINGBUF_GetFill (Thumb, 30 bytes, Stack size 0 bytes, ringbuf.o(.text))

[Called By]

- >> GPRS_CmdRecvData
- >> SMS_Manage

SetOutReport (Thumb, 38 bytes, Stack size 80 bytes, hiduser.o(.text))

[Stack]

- Max Depth = 104
- Call Chain = SetOutReport ⇒ USB_ReadEP

[Calls]

- >> USB_ReadEP
- >> RINGBUF_Put

[Called By]

- >> USB_EndPoint1
- >> HID_SetReport

GetInReport (Thumb, 64 bytes, Stack size 80 bytes, hiduser.o(.text))

[Stack]

- Max Depth = 100
- Call Chain = GetInReport ⇒ USB_WriteEP

[Calls]

- >> RINGBUF_Get
- >> USB_WriteEP

[Called By]

- >> USB_EndPoint1
- >> USB_Configure_Event
- >> HID_GetReport

HID_GetReport (Thumb, 40 bytes, Stack size 8 bytes, hiduser.o(.text))

[Stack]

- Max Depth = 108
- Call Chain = HID_GetReport ⇒ GetInReport ⇒ USB_WriteEP

[Calls]

- >> GetInReport

[Called By]

- >> USB_EndPoint0

HID_SetReport (Thumb, 40 bytes, Stack size 8 bytes, hiduser.o(.text))

[Stack]

- Max Depth = 112
- Call Chain = HID_SetReport ⇒ SetOutReport ⇒ USB_ReadEP

[Calls]

- >> SetOutReport

[Called By]

- >> USB_EndPoint0

HID_GetIdle (Thumb, 16 bytes, Stack size 0 bytes, hiduser.o(.text))

[Called By]

- >> USB_EndPoint0

HID_SetIdle (Thumb, 16 bytes, Stack size 0 bytes, hiduser.o(.text))

[Called By]

- >> USB_EndPoint0

HID_GetProtocol (Thumb, 12 bytes, Stack size 0 bytes, hiduser.o(.text))

[Called By]

- >> USB_EndPoint0

HID_SetProtocol (Thumb, 12 bytes, Stack size 0 bytes, hiduser.o(.text))

[Called By]

- >> USB_EndPoint0

SST25_Init (Thumb, 10 bytes, Stack size 8 bytes, sst25.o(.text))

[Stack]

- Max Depth = 8
- Call Chain = SST25_Init

[Calls]

- >> SPI_Init

[Called By]

- >> SetLowPowerModes
- >> main

SST25_Erase (Thumb, 126 bytes, Stack size 16 bytes, sst25.o(.text))

[Stack]

- Max Depth = 48
- Call Chain = SST25_Erase ⇒ SST25__WriteEnable ⇒ SST25__Status ⇒ halSpiWriteByte

[Calls]

- >> SST25__WriteEnable
- >> halSpiWriteByte

[Called By]

- >> CMD_CfgParse
- >> SST25_Write
- >> CfgProcessData
- >> DB_SaveDataLog
- >> DB_LogRingSave
- >> DB_ResetCntSave
- >> DB_MileageSave

_SST25_Write (Thumb, 128 bytes, Stack size 32 bytes, sst25.o(.text))

[Stack]

- Max Depth = 64
- Call Chain = _SST25_Write ⇒ SST25__WriteEnable ⇒ SST25__Status ⇒ halSpiWriteByte

[Calls]

- >> SST25__WriteEnable
- >> SST25__Status
- >> halSpiWriteByte

[Called By]

- >> SST25_Write

SST25_Write (Thumb, 82 bytes, Stack size 24 bytes, sst25.o(.text))

[Stack]

- Max Depth = 88
- Call Chain = SST25_Write ⇒ _SST25_Write ⇒ SST25__WriteEnable ⇒ SST25__Status ⇒ halSpiWriteByte

[Calls]

- >> _SST25_Write
- >> SST25_Erase

[Called By]

- >> DB_U32Save
- >> SST25_disk_write
- >> FlashReadWriteCtrl
- >> DB_SaveDataLog
- >> DB_LogRingSave
- >> DB_ResetCntSave
- >> DB_MileageSave

SST25_Read (Thumb, 112 bytes, Stack size 24 bytes, sst25.o(.text))

[Stack]

- Max Depth = 40
- Call Chain = SST25_Read ⇒ SST25__Status ⇒ halSpiWriteByte

[Calls]

- >> SST25__Status
- >> halSpiWriteByte

[Called By]

- >> DB_U32Save
- >> SST25_disk_read
- >> FlashReadWriteCtrl
- >> CfgProcessData
- >> DB_LoadDataLogTail
- >> DB_LoadDataInfo
- >> DB_InitLog
- >> DB_U32Load
- >> DB_ResetCntLoad
- >> DB_MileageLoad

ModemCmdTask_IsCriticalCmd (Thumb, 6 bytes, Stack size 0 bytes, modem.o(.text))

[Called By]

- >> UploadConfig_Task
- >> SendPowerCmd_GprsTask
- >> SendGpsData_GprsTask

MODEM_FlushBuffer (Thumb, 18 bytes, Stack size 8 bytes, modem.o(.text))

[Stack]

- Max Depth = 8
- Call Chain = MODEM_FlushBuffer

[Calls]

- >> RINGBUF_Get

[Called By]

- >> ModemCmdTask_SendCmd
- >> MODEM_GetCSQ
- >> MODEM_CheckGPRSDataOut
- >> GetIMEI
- >> ModemCmd_Task
- >> MODEM_SendCommand
- >> MODEM_Init
- >> SendSMS
- >> MODEM_CloseSocket

MODEM_SendCommand (Thumb, 168 bytes, Stack size 56 bytes, modem.o(.text))

[Stack]

- Max Depth = 80
- Call Chain = MODEM_SendCommand ⇒ __c89vsprintf

[Calls]

- >> RINGBUF_Get
- >> uart_putstr
- >> uart_putchar
- >> InitTimeout
- >> DelayMs
- >> CheckTimeout
- >> InitFindData
- >> FindData
- >> MODEM_FlushBuffer
- >> __c89vsprintf

[Called By]

- >> VoiceSetup
- >> UploadConfig_Task
- >> SendPowerCmd_GprsTask
- >> SendGpsData_GprsTask
- >> Sms_Task
- >> MODEM_PowerOff
- >> MODEM_Init
- >> Gsm_Task
- >> main
- >> AppRun
- >> SysSleep

MODEM_Init (Thumb, 200 bytes, Stack size 8 bytes, modem.o(.text))

[Stack]

- Max Depth = 88
- Call Chain = MODEM_Init ⇒ MODEM_SendCommand ⇒ __c89vsprintf

[Calls]

- >> uart_init
- >> MODEM_SendCommand
- >> DelayMs
- >> MODEM_FlushBuffer

[Called By]

- >> MODEM_PowerOff
- >> main

MODEM_PowerOff (Thumb, 46 bytes, Stack size 8 bytes, modem.o(.text))

[Stack]

- Max Depth = 96
- Call Chain = MODEM_PowerOff ⇒ MODEM_Init ⇒ MODEM_SendCommand ⇒ __c89vsprintf

[Calls]

- >> MODEM_SendCommand
- >> MODEM_Init

[Called By]

- >> main

ModemCmdTask_SetCriticalCmd (Thumb, 16 bytes, Stack size 0 bytes, modem.o(.text))

[Called By]

- >> UploadConfig_Task
- >> SendPowerCmd_GprsTask
- >> SendGpsData_GprsTask

ModemCmdTask_IsIdle (Thumb, 30 bytes, Stack size 0 bytes, modem.o(.text))

[Called By]

- >> ModemCmdTask_SetWait
- >> UploadConfig_Task
- >> ModemCmdTask_SendCmd
- >> SendPowerCmd_GprsTask
- >> SendGpsData_GprsTask
- >> VoiceCall_Task
- >> Sms_Task
- >> Gsm_Task
- >> AppRun

ModemCmdTask_SendCmd (Thumb, 128 bytes, Stack size 40 bytes, modem.o(.text))

[Stack]

- Max Depth = 64
- Call Chain = ModemCmdTask_SendCmd ⇒ __c89vsprintf

[Calls]

- >> ModemCmdTask_IsIdle
- >> InitTimeout
- >> InitFindData
- >> MODEM_FlushBuffer
- >> __c89vsprintf
- >> strcpy

[Called By]

- >> UploadConfig_Task
- >> SendPowerCmd_GprsTask
- >> SendGpsData_GprsTask
- >> VoiceCall_Task
- >> Gsm_Task

ModemCmdTask_GetPhase (Thumb, 6 bytes, Stack size 0 bytes, modem.o(.text))

[Called By]

- >> UploadConfig_Task
- >> SendPowerCmd_GprsTask
- >> SendGpsData_GprsTask
- >> VoiceCall_Task
- >> Sms_Task
- >> Gsm_Task

ModemCmdTask_Reset (Thumb, 8 bytes, Stack size 0 bytes, modem.o(.text), UNUSED)

ModemCmdTask_SetWait (Thumb, 70 bytes, Stack size 16 bytes, modem.o(.text))

[Stack]

- Max Depth = 32
- Call Chain = ModemCmdTask_SetWait ⇒ InitFindData

[Calls]

- >> ModemCmdTask_IsIdle
- >> InitTimeout
- >> InitFindData
- >> strcpy

[Called By]

- >> Sms_Task

ModemCmd_Task (Thumb, 514 bytes, Stack size 8 bytes, modem.o(.text))

[Stack]

- Max Depth = 24
- Call Chain = ModemCmd_Task ⇒ CheckTimeout

[Calls]

- >> RINGBUF_Get
- >> uart_putstr
- >> __ARM_common_switch8
- >> InitTimeout
- >> GsmTask_Init
- >> CheckTimeout
- >> FindData
- >> MODEM_FlushBuffer

[Called By]

- >> SmsTask_Pause
- >> ModemCmdTask_Cancel
- >> GprsTask_StopTask
- >> AppRun

ModemCmdTask_Cancel (Thumb, 56 bytes, Stack size 8 bytes, modem.o(.text))

[Stack]

- Max Depth = 32
- Call Chain = ModemCmdTask_Cancel ⇒ ModemCmd_Task ⇒ CheckTimeout

[Calls]

- >> uart_putchar
- >> ModemCmd_Task
- >> InitTimeout
- >> CheckTimeout

[Called By]

- >> GprsTask_StopTask

MODEM_CheckGPRSDataOut (Thumb, 140 bytes, Stack size 72 bytes, modem.o(.text))

[Stack]

- Max Depth = 96
- Call Chain = MODEM_CheckGPRSDataOut ⇒ __2sprintf

[Calls]

- >> RINGBUF_Get
- >> uart_putstr
- >> InitTimeout
- >> DelayMs
- >> CheckTimeout
- >> InitFindData
- >> FindData
- >> MODEM_FlushBuffer
- >> __2sprintf

[Called By]

- >> UploadConfig_Task
- >> SendPowerCmd_GprsTask
- >> SendGpsData_GprsTask

MODEM_CloseSocket (Thumb, 122 bytes, Stack size 72 bytes, modem.o(.text))

[Stack]

- Max Depth = 96
- Call Chain = MODEM_CloseSocket ⇒ __2sprintf

[Calls]

- >> RINGBUF_Get
- >> uart_putstr
- >> InitTimeout
- >> DelayMs
- >> CheckTimeout
- >> InitFindData
- >> FindData
- >> MODEM_FlushBuffer
- >> __2sprintf

[Called By]

- >> MODEM_DisconectSocket

ParserCellLocate (Thumb, 316 bytes, Stack size 152 bytes, modem.o(.text))

[Stack]

- Max Depth = 488
- Call Chain = ParserCellLocate ⇒ nmea_scanf ⇒ nmea_atof ⇒ strtod ⇒ __strtod_int ⇒ _local_sscanf ⇒ _scanf_real

[Calls]

- >> __aeabi_cdrcmple
- >> __aeabi_cdcmple
- >> TIME_GetSec
- >> nmea_scanf
- >> __aeabi_memcpy4

[Called By]

- >> TrackerTask

MODEM_DisconectSocket (Thumb, 14 bytes, Stack size 8 bytes, modem.o(.text))

[Stack]

- Max Depth = 104
- Call Chain = MODEM_DisconectSocket ⇒ MODEM_CloseSocket ⇒ __2sprintf

[Calls]

- >> MODEM_CloseSocket

[Called By]

- >> UploadConfig_Task
- >> SendPowerCmd_GprsTask
- >> SendGpsData_GprsTask

MODEM_GetSocket (Thumb, 68 bytes, Stack size 0 bytes, modem.o(.text))

[Called By]

- >> UploadConfig_Task
- >> SendPowerCmd_GprsTask
- >> SendGpsData_GprsTask

VoiceSetup (Thumb, 166 bytes, Stack size 8 bytes, modem.o(.text))

[Stack]

- Max Depth = 88
- Call Chain = VoiceSetup ⇒ MODEM_SendCommand ⇒ __c89vsprintf

[Calls]

- >> MODEM_SendCommand
- >> DelayMs
- >> AudioEnable

[Called By]

- >> VoiceCall_Task

MODEM_CheckResponse (Thumb, 354 bytes, Stack size 24 bytes, modem.o(.text))

[Stack]

- Max Depth = 40
- Call Chain = MODEM_CheckResponse ⇒ InitFindData

[Calls]

- >> RINGBUF_Get
- >> DelayMs
- >> InitFindData
- >> FindData

[Called By]

- >> MODEM_GetCSQ
- >> GetIMEI
- >> SMS_Manage
- >> SendSMS

MODEM_GetCSQ (Thumb, 282 bytes, Stack size 24 bytes, modem.o(.text))

[Stack]

- Max Depth = 288
- Call Chain = MODEM_GetCSQ ⇒ __0sscanf ⇒ __vfscanf_char ⇒ __vfscanf ⇒ _scanf_real

[Calls]

- >> RINGBUF_Get
- >> uart_putstr
- >> DelayMs
- >> __aeabi_f2uiz
- >> __aeabi_ui2f
- >> __aeabi_cfcmple
- >> __aeabi_cfcmpeq
- >> MODEM_CheckResponse
- >> MODEM_FlushBuffer
- >> __0sscanf

[Called By]

- >> SendGpsData_GprsTask
- >> Gsm_Task

SendSMS (Thumb, 112 bytes, Stack size 48 bytes, modem.o(.text))

[Stack]

- Max Depth = 88
- Call Chain = SendSMS ⇒ MODEM_CheckResponse ⇒ InitFindData

[Calls]

- >> uart_putstr
- >> uart_putchar
- >> DelayMs
- >> MODEM_CheckResponse
- >> MODEM_FlushBuffer
- >> __2sprintf

[Called By]

- >> SMS_Manage

MODEM_Gets (Thumb, 80 bytes, Stack size 24 bytes, modem.o(.text))

[Stack]

- Max Depth = 24
- Call Chain = MODEM_Gets

[Calls]

- >> RINGBUF_Get

[Called By]

- >> GetIMEI

GetIMEI (Thumb, 66 bytes, Stack size 16 bytes, modem.o(.text))

[Stack]

- Max Depth = 56
- Call Chain = GetIMEI ⇒ MODEM_CheckResponse ⇒ InitFindData

[Calls]

- >> uart_putstr
- >> DelayMs
- >> MODEM_Gets
- >> MODEM_CheckResponse
- >> MODEM_FlushBuffer

[Called By]

- >> Gsm_Task

AT_CmdProcessInit (Thumb, 56 bytes, Stack size 8 bytes, at_command_parser.o(.text))

[Stack]

- Max Depth = 20
- Call Chain = AT_CmdProcessInit ⇒ StrParserInit

[Calls]

- >> RINGBUF_Init
- >> StrParserInit

[Called By]

- >> AT_ComnandParser

AT_ComnandParser (Thumb, 36 bytes, Stack size 8 bytes, at_command_parser.o(.text))

[Stack]

- Max Depth = 64
- Call Chain = AT_ComnandParser ⇒ StrComnandParser ⇒ StrParserCtl

[Calls]

- >> StrComnandParser
- >> AT_CmdProcessInit

[Called By]

- >> UART1_IRQHandler

GsmGetTime (Thumb, 460 bytes, Stack size 4 bytes, at_command_parser.o(.text))

[Stack]

- Max Depth = 12
- Call Chain = GsmGetTime ⇒ __ARM_common_switch8

[Calls]

- >> __ARM_common_switch8

[Address Reference Count : 1]

- at_command_parser.o(.constdata)

CallOutProcess (Thumb, 122 bytes, Stack size 0 bytes, at_command_parser.o(.text))
[Address Reference Count : 1]

- at_command_parser.o(.constdata)

CallCancel (Thumb, 12 bytes, Stack size 0 bytes, at_command_parser.o(.text))
[Address Reference Count : 1]

- at_command_parser.o(.constdata)

CallErrorReport (Thumb, 144 bytes, Stack size 0 bytes, at_command_parser.o(.text))
[Address Reference Count : 1]

- at_command_parser.o(.constdata)

CallNoAnswer (Thumb, 12 bytes, Stack size 0 bytes, at_command_parser.o(.text))
[Address Reference Count : 1]

- at_command_parser.o(.constdata)

CallBusy (Thumb, 12 bytes, Stack size 0 bytes, at_command_parser.o(.text))
[Address Reference Count : 1]

- at_command_parser.o(.constdata)

GetBatteryStatus (Thumb, 110 bytes, Stack size 0 bytes, at_command_parser.o(.text))
[Address Reference Count : 1]

- at_command_parser.o(.constdata)

CellLocateParser (Thumb, 144 bytes, Stack size 0 bytes, at_command_parser.o(.text))
[Address Reference Count : 1]

- at_command_parser.o(.constdata)

GetCallerNumber (Thumb, 58 bytes, Stack size 0 bytes, at_command_parser.o(.text))
[Address Reference Count : 1]

- at_command_parser.o(.constdata)

RingCallProcess (Thumb, 26 bytes, Stack size 0 bytes, at_command_parser.o(.text))
[Address Reference Count : 1]

- at_command_parser.o(.constdata)

SMS_ModemOk (Thumb, 12 bytes, Stack size 0 bytes, at_command_parser.o(.text))
[Address Reference Count : 1]

- at_command_parser.o(.constdata)

SMS_NewMessage (Thumb, 12 bytes, Stack size 0 bytes, at_command_parser.o(.text))
[Address Reference Count : 1]

- at_command_parser.o(.constdata)

RemaskSocket (Thumb, 40 bytes, Stack size 0 bytes, at_command_parser.o(.text))

[Called By]

- >> GPRS_GetData
- >> GPRS_GetLength
- >> GPRS_CloseSocket
- >> GPRS_CloseSocket1
- >> GPRS_SocketControl

GPRS_SocketControl (Thumb, 150 bytes, Stack size 8 bytes, at_command_parser.o(.text))

[Stack]

- Max Depth = 16
- Call Chain = GPRS_SocketControl ⇒ __ARM_common_switch8

[Calls]

- >> __ARM_common_switch8
- >> RemaskSocket

[Address Reference Count : 1]

- at_command_parser.o(.constdata)

GPRS_CreateSocket (Thumb, 26 bytes, Stack size 0 bytes, at_command_parser.o(.text))
[Address Reference Count : 1]

- at_command_parser.o(.constdata)

GPRS_CloseSocket1 (Thumb, 32 bytes, Stack size 12 bytes, at_command_parser.o(.text))

[Stack]

- Max Depth = 12
- Call Chain = GPRS_CloseSocket1

[Calls]

- >> RemaskSocket

[Address Reference Count : 1]

- at_command_parser.o(.constdata)

GPRS_CloseSocket (Thumb, 74 bytes, Stack size 8 bytes, at_command_parser.o(.text))

[Stack]

- Max Depth = 8
- Call Chain = GPRS_CloseSocket

[Calls]

- >> RemaskSocket

[Address Reference Count : 1]

- at_command_parser.o(.constdata)

SMS_Process (Thumb, 146 bytes, Stack size 8 bytes, at_command_parser.o(.text))

[Stack]

- Max Depth = 16
- Call Chain = SMS_Process ⇒ RINGBUF_Put

[Calls]

- >> RINGBUF_Put

[Address Reference Count : 1]

- at_command_parser.o(.constdata)

GPRS_Deactivation (Thumb, 12 bytes, Stack size 0 bytes, at_command_parser.o(.text))
[Address Reference Count : 1]

- at_command_parser.o(.constdata)

GPRS_GetLength (Thumb, 164 bytes, Stack size 8 bytes, at_command_parser.o(.text))

[Stack]

- Max Depth = 16
- Call Chain = GPRS_GetLength ⇒ RINGBUF_Put

[Calls]

- >> RINGBUF_Put
- >> RemaskSocket

[Address Reference Count : 1]

- at_command_parser.o(.constdata)

GPRS_CmdRecvData (Thumb, 408 bytes, Stack size 56 bytes, at_command_parser.o(.text))

[Stack]

- Max Depth = 80
- Call Chain = GPRS_CmdRecvData ⇒ __2sprintf

[Calls]

- >> TICK_Get
- >> RINGBUF_Get
- >> uart_putstr
- >> InitTimeout
- >> DelayMs
- >> CheckTimeout
- >> RINGBUF_GetFill
- >> __2sprintf

[Called By]

- >> UploadConfig_Task
- >> SendPowerCmd_GprsTask
- >> SendGpsData_GprsTask

GPRS_GetDNS (Thumb, 82 bytes, Stack size 0 bytes, at_command_parser.o(.text))
[Address Reference Count : 1]

- at_command_parser.o(.constdata)

GPRS_GetData (Thumb, 252 bytes, Stack size 8 bytes, at_command_parser.o(.text))

[Stack]

- Max Depth = 8
- Call Chain = GPRS_GetData

[Calls]

- >> RemaskSocket

[Address Reference Count : 1]

- at_command_parser.o(.constdata)

SMS_ReadMsg (Thumb, 268 bytes, Stack size 0 bytes, at_command_parser.o(.text))
[Address Reference Count : 1]

- at_command_parser.o(.constdata)

CMD_CfgParse (Thumb, 9116 bytes, Stack size 208 bytes, at_command_parser.o(.text))

[Stack]

- Max Depth = 472
- Call Chain = CMD_CfgParse ⇒ __0sscanf ⇒ __vfscanf_char ⇒ __vfscanf ⇒ _scanf_real

[Calls]

- >> GpsTask_EnableGps
- >> CFG_Save
- >> GprsTask_StartTask
- >> CFG_Load
- >> SST25_Erase
- >> __aeabi_cdcmpeq
- >> UpdateRtcTime
- >> TIME_GetSec
- >> __aeabi_cfrcmple
- >> DB_ResetCntSave
- >> DB_ResetCntLoad
- >> DB_MileageSave
- >> DB_MileageLoad
- >> DB_LogRingReset
- >> __aeabi_cfcmple
- >> __0sscanf
- >> __aeabi_uwrite8
- >> __aeabi_uwrite4
- >> __2sprintf
- >> strlen
- >> strstr
- >> __aeabi_memclr
- >> __aeabi_memset
- >> __aeabi_memcpy

[Called By]

- >> SendPowerCmd_GprsTask
- >> SendGpsData_GprsTask
- >> SMS_Manage

SMS_Manage (Thumb, 836 bytes, Stack size 80 bytes, at_command_parser.o(.text))

[Stack]

- Max Depth = 552
- Call Chain = SMS_Manage ⇒ CMD_CfgParse ⇒ __0sscanf ⇒ __vfscanf_char ⇒ __vfscanf ⇒ _scanf_real

[Calls]

- >> RINGBUF_Get
- >> uart_putstr
- >> CMD_CfgParse
- >> InitTimeout
- >> DelayMs
- >> CheckTimeout
- >> AudioStopAll
- >> AudioPlayFile
- >> RINGBUF_GetFill
- >> SendSMS
- >> MODEM_CheckResponse
- >> __2sprintf

[Called By]

- >> AppRun

CFG_Save (Thumb, 216 bytes, Stack size 24 bytes, system_config.o(.text))

[Stack]

- Max Depth = 56
- Call Chain = CFG_Save ⇒ Flash_ByteProgram

[Calls]

- >> Flash_ByteProgram
- >> Flash_SectorErase
- >> NVIC_SystemReset
- >> __aeabi_uwrite4

[Called By]

- >> CMD_CfgParse
- >> Gsm_Task
- >> CFG_Load
- >> CfgProcessData

CFG_Load (Thumb, 1216 bytes, Stack size 24 bytes, system_config.o(.text))

[Stack]

- Max Depth = 80
- Call Chain = CFG_Load ⇒ CFG_Save ⇒ Flash_ByteProgram

[Calls]

- >> CFG_Save
- >> Flash_Init
- >> __aeabi_uwrite8
- >> __aeabi_uwrite4
- >> __aeabi_uread4
- >> strcpy
- >> __aeabi_memset
- >> __aeabi_memcpy

[Called By]

- >> CMD_CfgParse
- >> main

CFG_Check (Thumb, 1282 bytes, Stack size 24 bytes, system_config.o(.text), UNUSED)

[Calls]

- >> __aeabi_uwrite8
- >> __aeabi_uwrite4
- >> __aeabi_uread4
- >> strcpy

CFG_CheckSum (Thumb, 46 bytes, Stack size 24 bytes, system_config.o(.text), UNUSED)

[Calls]

- >> __aeabi_uread4

CFG_Write (Thumb, 114 bytes, Stack size 48 bytes, system_config.o(.text), UNUSED)

[Calls]

- >> Flash_ByteProgram
- >> Flash_SectorErase
- >> NVIC_SystemReset

gmtime_r (Thumb, 368 bytes, Stack size 40 bytes, m_time.o(.text))

[Stack]

- Max Depth = 68
- Call Chain = gmtime_r ⇒ __aeabi_idivmod ⇒ __aeabi_uidivmod

[Calls]

- >> __aeabi_idivmod
- >> __aeabi_uidivmod

[Called By]

- >> TIME_FromGps
- >> TIME_FromSec
- >> TIME_FromGsm
- >> localtime_r

localtime_r (Thumb, 26 bytes, Stack size 16 bytes, m_time.o(.text), UNUSED)

[Calls]

- >> gmtime_r

mktime (Thumb, 1144 bytes, Stack size 56 bytes, m_time.o(.text))

[Stack]

- Max Depth = 84
- Call Chain = mktime ⇒ __aeabi_idivmod ⇒ __aeabi_uidivmod

[Calls]

- >> __aeabi_idivmod

[Called By]

- >> TIME_GetSec
- >> TIME_FromGps
- >> TIME_FromGsm

TIME_FromGsm (Thumb, 208 bytes, Stack size 64 bytes, sys_time.o(.text))

[Stack]

- Max Depth = 148
- Call Chain = TIME_FromGsm ⇒ mktime ⇒ __aeabi_idivmod ⇒ __aeabi_uidivmod

[Calls]

- >> mktime
- >> gmtime_r

[Called By]

- >> TrackerTask

TIME_FromGps (Thumb, 114 bytes, Stack size 64 bytes, sys_time.o(.text))

[Stack]

- Max Depth = 148
- Call Chain = TIME_FromGps ⇒ mktime ⇒ __aeabi_idivmod ⇒ __aeabi_uidivmod

[Calls]

- >> mktime
- >> gmtime_r

[Called By]

- >> GpsTask_Control

TIME_GetSec (Thumb, 146 bytes, Stack size 56 bytes, sys_time.o(.text))

[Stack]

- Max Depth = 140
- Call Chain = TIME_GetSec ⇒ mktime ⇒ __aeabi_idivmod ⇒ __aeabi_uidivmod

[Calls]

- >> mktime

[Called By]

- >> DSOS_Add
- >> CMD_CfgParse
- >> TrackerTask
- >> GpsTask_Control
- >> TPM0_IRQHandler
- >> TIME_AddSec
- >> ParserCellLocate

TIME_FromSec (Thumb, 84 bytes, Stack size 64 bytes, sys_time.o(.text))

[Stack]

- Max Depth = 132
- Call Chain = TIME_FromSec ⇒ gmtime_r ⇒ __aeabi_idivmod ⇒ __aeabi_uidivmod

[Calls]

- >> gmtime_r

[Called By]

- >> DSOS_Add
- >> TrackerTask
- >> UpdateRtcTime
- >> TIME_AddSec

TIME_AddSec (Thumb, 42 bytes, Stack size 16 bytes, sys_time.o(.text), UNUSED)

[Calls]

- >> TIME_GetSec
- >> TIME_FromSec

StrParserInit (Thumb, 42 bytes, Stack size 12 bytes, string_parser.o(.text))

[Stack]

- Max Depth = 12
- Call Chain = StrParserInit

[Called By]

- >> AT_CmdProcessInit

StrParserCtl (Thumb, 70 bytes, Stack size 16 bytes, string_parser.o(.text))

[Stack]

- Max Depth = 16
- Call Chain = StrParserCtl

[Calls]

- >> TICK_Get

[Called By]

- >> StrComnandParser

StrComnandParser (Thumb, 226 bytes, Stack size 40 bytes, string_parser.o(.text))

[Stack]

- Max Depth = 56
- Call Chain = StrComnandParser ⇒ StrParserCtl

[Calls]

- >> StrParserCtl

[Called By]

- >> AT_ComnandParser

DbCalcCheckSum (Thumb, 26 bytes, Stack size 8 bytes, db.o(.text))

[Stack]

- Max Depth = 8
- Call Chain = DbCalcCheckSum

[Called By]

- >> DB_U32Save
- >> DB_SaveDataLog
- >> DB_LoadDataLogTail
- >> DB_LoadDataInfo
- >> DB_InitLog
- >> DB_LogRingSave
- >> DB_U32Load
- >> DB_ResetCntSave
- >> DB_ResetCntLoad
- >> DB_MileageSave
- >> DB_MileageLoad

DB_U32Load (Thumb, 84 bytes, Stack size 32 bytes, db.o(.text))

[Stack]

- Max Depth = 72
- Call Chain = DB_U32Load ⇒ SST25_Read ⇒ SST25__Status ⇒ halSpiWriteByte

[Calls]

- >> SST25_Read
- >> DbCalcCheckSum

[Called By]

- >> DB_FlashMemInit

DB_ResetCntSave (Thumb, 108 bytes, Stack size 16 bytes, db.o(.text))

[Stack]

- Max Depth = 104
- Call Chain = DB_ResetCntSave ⇒ SST25_Write ⇒ _SST25_Write ⇒ SST25__WriteEnable ⇒ SST25__Status ⇒ halSpiWriteByte

[Calls]

- >> SST25_Write
- >> SST25_Erase
- >> DbCalcCheckSum

[Called By]

- >> CMD_CfgParse
- >> DB_FlashMemInit
- >> CfgProcessData

DB_ResetCntLoad (Thumb, 86 bytes, Stack size 24 bytes, db.o(.text))

[Stack]

- Max Depth = 64
- Call Chain = DB_ResetCntLoad ⇒ SST25_Read ⇒ SST25__Status ⇒ halSpiWriteByte

[Calls]

- >> SST25_Read
- >> DbCalcCheckSum

[Called By]

- >> CMD_CfgParse
- >> DB_FlashMemInit
- >> CfgProcessData

DB_MileageLoad (Thumb, 86 bytes, Stack size 24 bytes, db.o(.text))

[Stack]

- Max Depth = 64
- Call Chain = DB_MileageLoad ⇒ SST25_Read ⇒ SST25__Status ⇒ halSpiWriteByte

[Calls]

- >> SST25_Read
- >> DbCalcCheckSum

[Called By]

- >> CMD_CfgParse
- >> DB_FlashMemInit
- >> CfgProcessData

DB_LogRingSave (Thumb, 280 bytes, Stack size 24 bytes, db.o(.text))

[Stack]

- Max Depth = 112
- Call Chain = DB_LogRingSave ⇒ SST25_Write ⇒ _SST25_Write ⇒ SST25__WriteEnable ⇒ SST25__Status ⇒ halSpiWriteByte

[Calls]

- >> SST25_Write
- >> SST25_Erase
- >> DbCalcCheckSum
- >> __aeabi_uwrite4
- >> __aeabi_uread4
- >> __aeabi_uidivmod

[Called By]

- >> DB_SaveDataLog
- >> DB_LoadDataLogTail
- >> DB_LogRingReset

DB_LogRingReset (Thumb, 28 bytes, Stack size 8 bytes, db.o(.text))

[Stack]

- Max Depth = 120
- Call Chain = DB_LogRingReset ⇒ DB_LogRingSave ⇒ SST25_Write ⇒ _SST25_Write ⇒ SST25__WriteEnable ⇒ SST25__Status ⇒ halSpiWriteByte

[Calls]

- >> DB_LogRingSave
- >> __aeabi_uwrite4

[Called By]

- >> CMD_CfgParse
- >> CfgProcessData
- >> DB_InitLog

DB_InitLog (Thumb, 332 bytes, Stack size 64 bytes, db.o(.text))

[Stack]

- Max Depth = 184
- Call Chain = DB_InitLog ⇒ DB_LogRingReset ⇒ DB_LogRingSave ⇒ SST25_Write ⇒ _SST25_Write ⇒ SST25__WriteEnable ⇒ SST25__Status ⇒ halSpiWriteByte

[Calls]

- >> SST25_Read
- >> DbCalcCheckSum
- >> DB_LogRingReset
- >> __aeabi_uwrite4
- >> __aeabi_uread4
- >> __aeabi_memcpy
- >> __aeabi_uidivmod

[Called By]

- >> DB_FlashMemInit

DB_FlashMemInit (Thumb, 646 bytes, Stack size 32 bytes, db.o(.text))

[Stack]

- Max Depth = 216
- Call Chain = DB_FlashMemInit ⇒ DB_InitLog ⇒ DB_LogRingReset ⇒ DB_LogRingSave ⇒ SST25_Write ⇒ _SST25_Write ⇒ SST25__WriteEnable ⇒ SST25__Status ⇒ halSpiWriteByte

[Calls]

- >> __aeabi_f2d
- >> __aeabi_cdrcmple
- >> __aeabi_cdcmple
- >> neamFormatLatLng
- >> DB_InitLog
- >> DB_U32Load
- >> DB_ResetCntSave
- >> DB_ResetCntLoad
- >> DB_MileageLoad
- >> __aeabi_cfcmple

[Called By]

- >> main

DB_MileageSave (Thumb, 96 bytes, Stack size 16 bytes, db.o(.text))

[Stack]

- Max Depth = 104
- Call Chain = DB_MileageSave ⇒ SST25_Write ⇒ _SST25_Write ⇒ SST25__WriteEnable ⇒ SST25__Status ⇒ halSpiWriteByte

[Calls]

- >> SST25_Write
- >> SST25_Erase
- >> DbCalcCheckSum

[Called By]

- >> CMD_CfgParse
- >> CfgProcessData

DB_FloatToU32 (Thumb, 24 bytes, Stack size 24 bytes, db.o(.text))

[Stack]

- Max Depth = 32
- Call Chain = DB_FloatToU32 ⇒ __aeabi_d2f

[Calls]

- >> __aeabi_d2f

[Called By]

- >> TrackerTask
- >> GpsTask_Control

DB_U32ToFloat (Thumb, 8 bytes, Stack size 0 bytes, db.o(.text), UNUSED)

DB_U32Save (Thumb, 140 bytes, Stack size 32 bytes, db.o(.text))

[Stack]

- Max Depth = 120
- Call Chain = DB_U32Save ⇒ SST25_Write ⇒ _SST25_Write ⇒ SST25__WriteEnable ⇒ SST25__Status ⇒ halSpiWriteByte

[Calls]

- >> SST25_Read
- >> SST25_Write
- >> DbCalcCheckSum
- >> memcmp

[Called By]

- >> TrackerTask
- >> GpsTask_Control

DB_DataLogFill (Thumb, 86 bytes, Stack size 24 bytes, db.o(.text), UNUSED)

[Calls]

- >> __aeabi_uread4
- >> __aeabi_uidivmod

[Called By]

- >> CheckTrackerMsgFill

DB_LoadDataInfo (Thumb, 290 bytes, Stack size 40 bytes, db.o(.text), UNUSED)

[Calls]

- >> SST25_Read
- >> DbCalcCheckSum
- >> __aeabi_uread4
- >> __aeabi_uidivmod

DB_LoadDataLogTail (Thumb, 192 bytes, Stack size 32 bytes, db.o(.text))

[Stack]

- Max Depth = 144
- Call Chain = DB_LoadDataLogTail ⇒ DB_LogRingSave ⇒ SST25_Write ⇒ _SST25_Write ⇒ SST25__WriteEnable ⇒ SST25__Status ⇒ halSpiWriteByte

[Calls]

- >> SST25_Read
- >> DB_LogRingSave
- >> DbCalcCheckSum
- >> __aeabi_uwrite4
- >> __aeabi_uread4
- >> __aeabi_uidivmod

[Called By]

- >> TrackerTask
- >> TPM0_IRQHandler

DB_SaveDataLog (Thumb, 412 bytes, Stack size 48 bytes, db.o(.text))

[Stack]

- Max Depth = 160
- Call Chain = DB_SaveDataLog ⇒ DB_LogRingSave ⇒ SST25_Write ⇒ _SST25_Write ⇒ SST25__WriteEnable ⇒ SST25__Status ⇒ halSpiWriteByte

[Calls]

- >> SST25_Write
- >> SST25_Erase
- >> DB_LogRingSave
- >> DbCalcCheckSum
- >> __aeabi_uwrite4
- >> __aeabi_uread4
- >> __aeabi_uidivmod

[Called By]

- >> TrackerTask

TrackerInit (Thumb, 12 bytes, Stack size 0 bytes, tracker.o(.text))

[Called By]

- >> main

TrackerTask (Thumb, 1580 bytes, Stack size 32 bytes, tracker.o(.text))

[Stack]

- Max Depth = 720
- Call Chain = TrackerTask ⇒ PedometerTask ⇒ ambo_step_detect ⇒ b2_filter

[Calls]

- >> GpsTask_EnableGps
- >> GprsTask_StartTask
- >> GprsTask_GetPhase
- >> AudioStopCheck
- >> __aeabi_f2uiz
- >> __aeabi_d2f
- >> __aeabi_cdrcmple
- >> __aeabi_cdcmple
- >> __aeabi_cdcmpeq
- >> UpdateRtcTime
- >> TIME_GetSec
- >> DB_U32Save
- >> DB_FloatToU32
- >> GpsTask_Control
- >> PedometerTask
- >> neamFormatLatLng
- >> DB_SaveDataLog
- >> DB_LoadDataLogTail
- >> TIME_FromSec
- >> TIME_FromGsm
- >> ParserCellLocate
- >> __aeabi_uwrite8
- >> __aeabi_uwrite4
- >> __aeabi_uread4
- >> __aeabi_memcpy
- >> __aeabi_uidivmod

[Called By]

- >> SysSleep
- >> TPM0_IRQHandler

PrintTrackerInfo (Thumb, 2 bytes, Stack size 0 bytes, tracker.o(.text), UNUSED)

CheckTrackerMsgFill (Thumb, 10 bytes, Stack size 8 bytes, tracker.o(.text), UNUSED)

[Calls]

- >> DB_DataLogFill

CheckTrackerMsgIsReady (Thumb, 24 bytes, Stack size 0 bytes, tracker.o(.text))

[Called By]

- >> SendGpsData_GprsTask

GetLastTrackerMsg (Thumb, 44 bytes, Stack size 16 bytes, tracker.o(.text), UNUSED)

[Calls]

- >> DGPS_Add

GetTrackerMsg (Thumb, 162 bytes, Stack size 16 bytes, tracker.o(.text))

[Stack]

- Max Depth = 432
- Call Chain = GetTrackerMsg ⇒ DGPS_Add ⇒ formatLatLng ⇒ floor ⇒ __aeabi_drsub ⇒ __aeabi_dadd ⇒ _double_epilogue ⇒ _double_round

[Calls]

- >> DGPS_Add
- >> DCLI_Add
- >> __aeabi_memcpy

[Called By]

- >> SendGpsData_GprsTask

DCFG_Add (Thumb, 130 bytes, Stack size 40 bytes, gprs_cmd_ctrl.o(.text))

[Stack]

- Max Depth = 64
- Call Chain = DCFG_Add ⇒ __2sprintf

[Calls]

- >> __2sprintf

[Called By]

- >> UploadConfig_Task

SCFG_Add (Thumb, 102 bytes, Stack size 40 bytes, gprs_cmd_ctrl.o(.text), UNUSED)

[Calls]

- >> __2sprintf

DCFG_Parser (Thumb, 132 bytes, Stack size 64 bytes, gprs_cmd_ctrl.o(.text))

[Stack]

- Max Depth = 328
- Call Chain = DCFG_Parser ⇒ __0sscanf ⇒ __vfscanf_char ⇒ __vfscanf ⇒ _scanf_real

[Calls]

- >> __0sscanf
- >> strcmp

[Called By]

- >> UploadConfig_Task

IsGprsDataPacket (Thumb, 36 bytes, Stack size 16 bytes, gprs_cmd_ctrl.o(.text))

[Stack]

- Max Depth = 16
- Call Chain = IsGprsDataPacket

[Called By]

- >> SendPowerCmd_GprsTask
- >> SendGpsData_GprsTask

DPWF_Add (Thumb, 124 bytes, Stack size 184 bytes, gprs_cmd_ctrl.o(.text))

[Stack]

- Max Depth = 208
- Call Chain = DPWF_Add ⇒ __2sprintf

[Calls]

- >> __2sprintf
- >> strlen
- >> strcat

[Called By]

- >> SendPowerCmd_GprsTask

DPWO_Add (Thumb, 124 bytes, Stack size 184 bytes, gprs_cmd_ctrl.o(.text))

[Stack]

- Max Depth = 208
- Call Chain = DPWO_Add ⇒ __2sprintf

[Calls]

- >> __2sprintf
- >> strlen
- >> strcat

[Called By]

- >> SendPowerCmd_GprsTask

DCLI_Add (Thumb, 1148 bytes, Stack size 240 bytes, gprs_cmd_ctrl.o(.text))

[Stack]

- Max Depth = 416
- Call Chain = DCLI_Add ⇒ formatLatLng ⇒ floor ⇒ __aeabi_drsub ⇒ __aeabi_dadd ⇒ _double_epilogue ⇒ _double_round

[Calls]

- >> __aeabi_fmul
- >> __aeabi_fdiv
- >> __aeabi_f2uiz
- >> __aeabi_f2d
- >> formatLatLng
- >> __aeabi_ui2d
- >> __aeabi_frsub
- >> __aeabi_drsub
- >> __aeabi_dmul
- >> __aeabi_d2uiz
- >> __aeabi_ui2f
- >> __aeabi_uread8
- >> __aeabi_uread4
- >> __2sprintf
- >> strlen
- >> strcat
- >> __aeabi_idivmod

[Called By]

- >> GetTrackerMsg

DGPS_Add (Thumb, 1066 bytes, Stack size 240 bytes, gprs_cmd_ctrl.o(.text))

[Stack]

- Max Depth = 416
- Call Chain = DGPS_Add ⇒ formatLatLng ⇒ floor ⇒ __aeabi_drsub ⇒ __aeabi_dadd ⇒ _double_epilogue ⇒ _double_round

[Calls]

- >> __aeabi_fmul
- >> __aeabi_fdiv
- >> __aeabi_f2uiz
- >> __aeabi_f2d
- >> formatLatLng
- >> __aeabi_ui2d
- >> __aeabi_frsub
- >> __aeabi_drsub
- >> __aeabi_dmul
- >> __aeabi_d2uiz
- >> __aeabi_ui2f
- >> __aeabi_uread8
- >> __aeabi_uread4
- >> __2sprintf
- >> strlen
- >> strcat
- >> __aeabi_idivmod

[Called By]

- >> GetTrackerMsg
- >> GetLastTrackerMsg

DSOS_Add (Thumb, 1356 bytes, Stack size 272 bytes, gprs_cmd_ctrl.o(.text))

[Stack]

- Max Depth = 448
- Call Chain = DSOS_Add ⇒ formatLatLng ⇒ floor ⇒ __aeabi_drsub ⇒ __aeabi_dadd ⇒ _double_epilogue ⇒ _double_round

[Calls]

- >> __aeabi_cdrcmple
- >> __aeabi_cdcmple
- >> __aeabi_cdcmpeq
- >> TIME_GetSec
- >> formatLatLng
- >> __aeabi_ui2d
- >> __aeabi_drsub
- >> __aeabi_dmul
- >> __aeabi_d2uiz
- >> neamFormatLatLng
- >> TIME_FromSec
- >> __2sprintf
- >> strlen
- >> strcat
- >> __aeabi_idivmod

[Called By]

- >> SosTask_End
- >> SosTask_Start
- >> Sos_Task

GPRMC_Process (Thumb, 180 bytes, Stack size 0 bytes, gps.o(.text))
[Address Reference Count : 1]

- gps.o(.constdata)

GPGGA_Process (Thumb, 180 bytes, Stack size 0 bytes, gps.o(.text))
[Address Reference Count : 1]

- gps.o(.constdata)

GPGSA_Process (Thumb, 180 bytes, Stack size 0 bytes, gps.o(.text))
[Address Reference Count : 1]

- gps.o(.constdata)

GPGSV_Process (Thumb, 180 bytes, Stack size 0 bytes, gps.o(.text))
[Address Reference Count : 1]

- gps.o(.constdata)

GPS_ComnandParser (Thumb, 348 bytes, Stack size 16 bytes, gps.o(.text))

[Stack]

- Max Depth = 16
- Call Chain = GPS_ComnandParser

[Called By]

- >> UART0_IRQHandler

neamFormatLatLng (Thumb, 90 bytes, Stack size 40 bytes, gps.o(.text))

[Stack]

- Max Depth = 168
- Call Chain = neamFormatLatLng ⇒ __aeabi_dmul ⇒ _double_epilogue ⇒ _double_round

[Calls]

- >> __aeabi_dadd
- >> __aeabi_ui2d
- >> __aeabi_drsub
- >> __aeabi_dmul
- >> __aeabi_d2uiz

[Called By]

- >> DSOS_Add
- >> TrackerTask
- >> DB_FlashMemInit

formatLat (Thumb, 132 bytes, Stack size 48 bytes, gps.o(.text))

[Stack]

- Max Depth = 184
- Call Chain = formatLat ⇒ floor ⇒ __aeabi_drsub ⇒ __aeabi_dadd ⇒ _double_epilogue ⇒ _double_round

[Calls]

- >> __aeabi_ddiv
- >> __aeabi_dadd
- >> __aeabi_drsub
- >> __aeabi_dmul
- >> floor

[Called By]

- >> GpsTask_Control

formatLng (Thumb, 132 bytes, Stack size 48 bytes, gps.o(.text))

[Stack]

- Max Depth = 184
- Call Chain = formatLng ⇒ floor ⇒ __aeabi_drsub ⇒ __aeabi_dadd ⇒ _double_epilogue ⇒ _double_round

[Calls]

- >> __aeabi_ddiv
- >> __aeabi_dadd
- >> __aeabi_drsub
- >> __aeabi_dmul
- >> floor

[Called By]

- >> GpsTask_Control

formatLatLng (Thumb, 88 bytes, Stack size 40 bytes, gps.o(.text))

[Stack]

- Max Depth = 176
- Call Chain = formatLatLng ⇒ floor ⇒ __aeabi_drsub ⇒ __aeabi_dadd ⇒ _double_epilogue ⇒ _double_round

[Calls]

- >> __aeabi_ddiv
- >> __aeabi_dadd
- >> __aeabi_drsub
- >> __aeabi_dmul
- >> floor

[Called By]

- >> DSOS_Add
- >> DGPS_Add
- >> DCLI_Add

GpsGetInfo (Thumb, 62 bytes, Stack size 24 bytes, gps.o(.text), UNUSED)

[Calls]

- >> InitTimeout
- >> CheckTimeout
- >> __aeabi_memcpy4

nmea_zero_INFO (Thumb, 22 bytes, Stack size 8 bytes, gps.o(.text))

[Stack]

- Max Depth = 8
- Call Chain = nmea_zero_INFO

[Calls]

- >> __aeabi_memclr4

[Called By]

- >> GPSInit
- >> GpsTask_Control

GPSInit (Thumb, 10 bytes, Stack size 8 bytes, gps.o(.text))

[Stack]

- Max Depth = 16
- Call Chain = GPSInit ⇒ nmea_zero_INFO

[Calls]

- >> nmea_zero_INFO

[Called By]

- >> main

nmea_GPGSV2info (Thumb, 10 bytes, Stack size 0 bytes, gps.o(.text))

[Called By]

- >> GPS_GetInfo

nmea_atoi (Thumb, 50 bytes, Stack size 56 bytes, gps.o(.text))

[Stack]

- Max Depth = 128
- Call Chain = nmea_atoi ⇒ strtol ⇒ _strtoul

[Calls]

- >> strtol
- >> __aeabi_memcpy

[Called By]

- >> nmea_scanf

nmea_atof (Thumb, 54 bytes, Stack size 56 bytes, gps.o(.text))

[Stack]

- Max Depth = 272
- Call Chain = nmea_atof ⇒ strtod ⇒ __strtod_int ⇒ _local_sscanf ⇒ _scanf_real

[Calls]

- >> __aeabi_memcpy
- >> strtod

[Called By]

- >> nmea_scanf

nmea_scanf (Thumb, 606 bytes, Stack size 64 bytes, gps.o(.text))

[Stack]

- Max Depth = 336
- Call Chain = nmea_scanf ⇒ nmea_atof ⇒ strtod ⇒ __strtod_int ⇒ _local_sscanf ⇒ _scanf_real

[Calls]

- >> nmea_atof
- >> nmea_atoi
- >> memchr
- >> __aeabi_memcpy
- >> __rt_ctype_table

[Called By]

- >> nmea_parse_GPRMC
- >> nmea_parse_GPGGA
- >> _nmea_parse_time
- >> nmea_parse_GPGSA
- >> nmea_parse_GPGSV
- >> ParserCellLocate

nmea_parse_GPGSV (Thumb, 152 bytes, Stack size 104 bytes, gps.o(.text))

[Stack]

- Max Depth = 440
- Call Chain = nmea_parse_GPGSV ⇒ nmea_scanf ⇒ nmea_atof ⇒ strtod ⇒ __strtod_int ⇒ _local_sscanf ⇒ _scanf_real

[Calls]

- >> nmea_scanf
- >> __aeabi_memclr4

[Called By]

- >> GPS_GetInfo

nmea_GPGSA2info (Thumb, 38 bytes, Stack size 0 bytes, gps.o(.text))

[Called By]

- >> GPS_GetInfo

nmea_parse_GPGSA (Thumb, 114 bytes, Stack size 80 bytes, gps.o(.text))

[Stack]

- Max Depth = 416
- Call Chain = nmea_parse_GPGSA ⇒ nmea_scanf ⇒ nmea_atof ⇒ strtod ⇒ __strtod_int ⇒ _local_sscanf ⇒ _scanf_real

[Calls]

- >> nmea_scanf
- >> __aeabi_memclr4

[Called By]

- >> GPS_GetInfo

nmea_GPGGA2info (Thumb, 136 bytes, Stack size 8 bytes, gps.o(.text))

[Stack]

- Max Depth = 8
- Call Chain = nmea_GPGGA2info

[Called By]

- >> GPS_GetInfo

_nmea_parse_time (Thumb, 128 bytes, Stack size 32 bytes, gps.o(.text))

[Stack]

- Max Depth = 368
- Call Chain = _nmea_parse_time ⇒ nmea_scanf ⇒ nmea_atof ⇒ strtod ⇒ __strtod_int ⇒ _local_sscanf ⇒ _scanf_real

[Calls]

- >> nmea_scanf

[Called By]

- >> nmea_parse_GPRMC
- >> nmea_parse_GPGGA

nmea_parse_GPGGA (Thumb, 130 bytes, Stack size 88 bytes, gps.o(.text))

[Stack]

- Max Depth = 456
- Call Chain = nmea_parse_GPGGA ⇒ _nmea_parse_time ⇒ nmea_scanf ⇒ nmea_atof ⇒ strtod ⇒ __strtod_int ⇒ _local_sscanf ⇒ _scanf_real

[Calls]

- >> _nmea_parse_time
- >> nmea_scanf
- >> strlen
- >> __aeabi_memclr4

[Called By]

- >> GPS_GetInfo

nmea_GPRMC2info (Thumb, 186 bytes, Stack size 24 bytes, gps.o(.text))

[Stack]

- Max Depth = 152
- Call Chain = nmea_GPRMC2info ⇒ __aeabi_dmul ⇒ _double_epilogue ⇒ _double_round

[Calls]

- >> __aeabi_dmul
- >> __aeabi_memcpy4

[Called By]

- >> GPS_GetInfo

nmea_parse_GPRMC (Thumb, 150 bytes, Stack size 88 bytes, gps.o(.text))

[Stack]

- Max Depth = 456
- Call Chain = nmea_parse_GPRMC ⇒ _nmea_parse_time ⇒ nmea_scanf ⇒ nmea_atof ⇒ strtod ⇒ __strtod_int ⇒ _local_sscanf ⇒ _scanf_real

[Calls]

- >> _nmea_parse_time
- >> nmea_scanf
- >> strlen
- >> __aeabi_memclr4

[Called By]

- >> GPS_GetInfo

GPS_GetInfo (Thumb, 446 bytes, Stack size 8 bytes, gps.o(.text))

[Stack]

- Max Depth = 464
- Call Chain = GPS_GetInfo ⇒ nmea_parse_GPRMC ⇒ _nmea_parse_time ⇒ nmea_scanf ⇒ nmea_atof ⇒ strtod ⇒ __strtod_int ⇒ _local_sscanf ⇒ _scanf_real

[Calls]

- >> nmea_parse_GPRMC
- >> nmea_GPRMC2info
- >> nmea_parse_GPGGA
- >> nmea_GPGGA2info
- >> nmea_parse_GPGSA
- >> nmea_GPGSA2info
- >> nmea_parse_GPGSV
- >> nmea_GPGSV2info

[Called By]

- >> GpsTask_Control

nmea_calc_crc (Thumb, 24 bytes, Stack size 8 bytes, gps.o(.text), UNUSED)

LPTMR_init (Thumb, 72 bytes, Stack size 16 bytes, tick.o(.text))

[Stack]

- Max Depth = 24
- Call Chain = LPTMR_init ⇒ NVIC_SetPriority

[Calls]

- >> NVIC_SetPriority

[Called By]

- >> main

GsmLedControl (Thumb, 120 bytes, Stack size 8 bytes, tick.o(.text))

[Stack]

- Max Depth = 16
- Call Chain = GsmLedControl ⇒ GprsTask_GetPhase

[Calls]

- >> GprsTask_GetPhase

[Called By]

- >> LedControl

GpsLedControl (Thumb, 72 bytes, Stack size 0 bytes, tick.o(.text))

[Called By]

- >> LedControl

LedControl (Thumb, 226 bytes, Stack size 8 bytes, tick.o(.text))

[Stack]

- Max Depth = 24
- Call Chain = LedControl ⇒ GsmLedControl ⇒ GprsTask_GetPhase

[Calls]

- >> GpsLedControl
- >> GsmLedControl

[Called By]

- >> LPTimerTask

ClearLastKeyStatus (Thumb, 10 bytes, Stack size 0 bytes, tick.o(.text))

[Called By]

- >> KeyTask_Control

KeyTask_Control (Thumb, 584 bytes, Stack size 8 bytes, tick.o(.text))

[Stack]

- Max Depth = 8
- Call Chain = KeyTask_Control

[Calls]

- >> Keys_Init
- >> ClearLastKeyStatus

[Called By]

- >> LPTimerTask

ChargerLedControl (Thumb, 148 bytes, Stack size 0 bytes, tick.o(.text))

[Called By]

- >> LPTimerTask

LPTimerTask (Thumb, 1130 bytes, Stack size 8 bytes, tick.o(.text))

[Stack]

- Max Depth = 32
- Call Chain = LPTimerTask ⇒ LedControl ⇒ GsmLedControl ⇒ GprsTask_GetPhase

[Calls]

- >> PlayAlarmWarningSound
- >> VoiceCallTask_GetPhase
- >> ChargerLedControl
- >> KeyTask_Control
- >> LedControl
- >> NVIC_SystemReset

[Called By]

- >> LLW_IRQHandler
- >> LPTimer_IRQHandler

LPTimer_IRQHandler (Thumb, 8 bytes, Stack size 8 bytes, tick.o(.text))

[Stack]

- Max Depth = 40
- Call Chain = LPTimer_IRQHandler ⇒ LPTimerTask ⇒ LedControl ⇒ GsmLedControl ⇒ GprsTask_GetPhase

[Calls]

- >> LPTimerTask

[Address Reference Count : 1]

- startup_mkl25z4.o(RESET)

UpdateRtcTime (Thumb, 28 bytes, Stack size 8 bytes, tick.o(.text))

[Stack]

- Max Depth = 140
- Call Chain = UpdateRtcTime ⇒ TIME_FromSec ⇒ gmtime_r ⇒ __aeabi_idivmod ⇒ __aeabi_uidivmod

[Calls]

- >> TIME_FromSec

[Called By]

- >> CMD_CfgParse
- >> TrackerTask
- >> GpsTask_Control

TICK_Init (Thumb, 50 bytes, Stack size 16 bytes, tick.o(.text))

[Stack]

- Max Depth = 28
- Call Chain = TICK_Init ⇒ __aeabi_uidivmod

[Calls]

- >> NVIC_SetPriority
- >> __aeabi_uidivmod

[Called By]

- >> SetLowPowerModes
- >> main

TICK_DeInit (Thumb, 8 bytes, Stack size 0 bytes, tick.o(.text), UNUSED)

GetKeyPressed (Thumb, 20 bytes, Stack size 0 bytes, tick.o(.text), UNUSED)

CheckKeyPressed (Thumb, 16 bytes, Stack size 0 bytes, tick.o(.text), UNUSED)

GetKeyPressTime (Thumb, 16 bytes, Stack size 0 bytes, tick.o(.text), UNUSED)

SysTick_Handler (Thumb, 30 bytes, Stack size 0 bytes, tick.o(.text))
[Address Reference Count : 1]

- startup_mkl25z4.o(RESET)

TICK_Get (Thumb, 6 bytes, Stack size 0 bytes, tick.o(.text))

[Called By]

- >> SmsTask_ClearAllSms
- >> GPRS_CmdRecvData
- >> InitTimeout
- >> DelayMs
- >> CheckTimeout
- >> APP_Read2FlashMem
- >> APP_Write2FlashMem
- >> TimerDelayms
- >> StrParserCtl

TICK_Get64 (Thumb, 8 bytes, Stack size 0 bytes, tick.o(.text), UNUSED)

DelayMs (Thumb, 24 bytes, Stack size 4 bytes, tick.o(.text))

[Stack]

- Max Depth = 4
- Call Chain = DelayMs

[Calls]

- >> TICK_Get

[Called By]

- >> VoiceSetup
- >> UploadConfig_Task
- >> MODEM_GetCSQ
- >> MODEM_CheckGPRSDataOut
- >> GetIMEI
- >> GPRS_CmdRecvData
- >> SendPowerCmd_GprsTask
- >> SendGpsData_GprsTask
- >> VoiceCall_Task
- >> Sms_Task
- >> SMS_Manage
- >> MODEM_SendCommand
- >> MODEM_Init
- >> Io_Task
- >> Gsm_Task
- >> AudioPlayFile
- >> main
- >> SysSleep
- >> SendSMS

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

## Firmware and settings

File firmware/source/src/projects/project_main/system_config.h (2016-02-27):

#ifndef __SYSTEM_CONFIG_H__
#define __SYSTEM_CONFIG_H__
#include <string.h>
#include <stdint.h>
#include <stdlib.h>

#define DEBUG_MODE	1

#define PAGE_SIZE                         (1024)    /* 4 Kbyte */
#define FLASH_SIZE                        (0x20000)  /* 128 KBytes */

#define CONFIG_AREA_SIZE		4096
#define CONFIG_AREA_START ((uint32_t)(FLASH_SIZE - PAGE_SIZE*(CONFIG_AREA_SIZE/PAGE_SIZE)))

#define POWER_OFF	0x0FF0FF0F
#define POWER_ON	0x01101101

#define FIRMWARE_VERSION	"4.0"

#define HARDWARE_V3



#define WARNING_SMS							4
#define WARNING_CALL						8


#define DEFAULT_BOSS_NUMBER	"+886975398002"
#define DEFAULT_SMS_PWD			"12345678"
#define DEFAULT_GPSR_APN		"internet"
#define DEFAULT_GPRS_USR		"mms"
#define DEFAULT_GPRS_PWD		"mms"
#define DEFAULT_SMS_MASTER_PWD	"ZOTA"

#define DEFAULT_DSERVER_NAME	"http://trackingatoz.vn"
#define DEFAULT_DSERVER_IP0		210
#define DEFAULT_DSERVER_IP1		71
#define DEFAULT_DSERVER_IP2		190
#define DEFAULT_DSERVER_IP3		170
#define DEFAULT_DSERVER_PORT	4051
#define DEFAULT_DSERVER_USEIP	1


#define DEFAULT_FSERVER_NAME	"http://atoztracking.vn"
#define DEFAULT_FSERVER_IP0		210
#define DEFAULT_FSERVER_IP1		71
#define DEFAULT_FSERVER_IP2		190
#define DEFAULT_FSERVER_IP3		170
#define DEFAULT_FSERVER_PORT	50000
#define DEFAULT_FSERVER_USEIP	1

#define DEFAULT_ISERVER_NAME	"http://atoztracking.vn"
#define DEFAULT_ISERVER_IP0		210
#define DEFAULT_ISERVER_IP1		71
#define DEFAULT_ISERVER_IP2		190
#define DEFAULT_ISERVER_IP3		170
#define DEFAULT_ISERVER_PORT	12345
#define DEFAULT_ISERVER_USEIP	1

#define DEFAULT_INFO_SERVER_NAME	"http://atoztracking.vn"
#define DEFAULT_INFO_SERVER_IP0		118
#define DEFAULT_INFO_SERVER_IP1		69
#define DEFAULT_INFO_SERVER_IP2		60
#define DEFAULT_INFO_SERVER_IP3		174
#define DEFAULT_INFO_SERVER_PORT	2802
#define DEFAULT_INFO_SERVER_USEIP	1


#define DEFAULT_REPORT_INTERVAL				10 	//min
#define DEFAULT_LONE_WORKER_INTERVAL	30 	//min
#define DEFAULT_ALARM_COUNTDOWN_TIME 	8		//sec
#define DEFAULT_NO_MOVEMENT_INTERVAL	60 	//min
#define DEFAULT_OPERATION_MODE				3

#define DEFAULT_CELL_NS								'N'
#define DEFAULT_CELL_EW								'E'
#define DEFAULT_GPS_NS								'N'
#define DEFAULT_GPS_EW								'E'

#define DEFAULT_CALL_ME_SMS						"Call Me!"
#define DEFAULT_SOS_RESPONDED_SMS			"Emergency call responded by %s."
#define DEFAULT_SOS_CANCELLED_SMS			"Emergency call is cancelled."

#define DEFAULT_SLEEP_TIMER		60


// system definitions
#define CONFIG_HW_VERSION			1
#define CONFIG_FW_VERSION			1
#define CONFIG_RELEASE_DATE			__TIMESTAMP__
#define CONFIG_MAX_USER			10


#define CONFIG_SIZE_GPRS_APN		16
#define CONFIG_SIZE_GPRS_USR		32
#define CONFIG_SIZE_GPRS_PWD		16
#define CONFIG_SIZE_SERVER_NAME		31
#define CONFIG_SIZE_SMS_PWD			16
#define CONFIG_SIZE_PLATE_NO		12
#define CONFIG_SIZE_USER_NAME		32
#define CONFIG_SIZE_PHONE_NUMBER	16
#define CONFIG_SIZE_SMS						80


#define FEATURE_GPS_AUTO_AIDING						0x0001
#define FEATURE_GPS_ASSISTNOW_OFFLINE			0x0002
#define FEATURE_GPS_ASSISTNOW_ONLINE			0x0004
#define FEATURE_GPS_ASSISTNOW_AUTONOMOUS	0x0008
#define FEATURE_LONE_WORKER_SET						0x0010
#define FEATURE_NO_MOVEMENT_WARNING_SET		0x0020
#define FEATURE_MAN_DOWN_SET							0x0040
#define FEATURE_SUPPORT_FIFO_MSG					0x0080
#define FEATURE_SMS_WARNING_ACTION_SET		0x0100
#define FEATURE_CALL_WARNING ACTION_SET		0x0200
#define FEATURE_AUTO_ANSWER								0x0400
#define FEATURE_DTMF_ON										0x0800

#define DEFAULT_MAN_DOWN_INTERVAL					30


#define CONFIG_SIZE_IP				32

#define FULL_RUNNING_MODE	0
#define GPS_ONLY_MODE			1
#define GSM_ONLY_MODE			2
#define STANDBY_MODE			3
#define SLEEPING_MODE			4

#define CONFIG_SPEED_STOP	5 //km/h

#define UPDATE_FIRMWARE_ENABLE	0xa5


typedef struct __attribute__((packed)){
	int8_t userName[CONFIG_SIZE_USER_NAME];
	int8_t phoneNo[CONFIG_SIZE_PHONE_NUMBER];
}USER_INFO;

typedef struct __attribute__((packed)){
	uint8_t geoFenceEnable;
	double lat;
	double lon;
	float radius;
	uint16_t time;
}GEO_FENCE_TYPE;

typedef struct __attribute__((packed))
{
	uint16_t size;
	int8_t imei[18];
	int8_t id[18];
	int8_t smsPwd[CONFIG_SIZE_SMS_PWD];					/**< SMS config password */
	int8_t whiteCallerNo[CONFIG_SIZE_PHONE_NUMBER];		/**< */
	// GPRS config
	int8_t gprsApn[CONFIG_SIZE_GPRS_APN];
	int8_t gprsUsr[CONFIG_SIZE_GPRS_USR];
	int8_t gprsPwd[CONFIG_SIZE_GPRS_PWD];
	uint16_t reportInterval; /*1 min to 30 mins or 1 hour to 24 hours*/
	// primary server config
	uint16_t priDserverIp[2];		/**< ip addr */
	uint8_t  priDserverName[CONFIG_SIZE_SERVER_NAME];	/**< domain name */
	uint16_t priDserverPort;	/**< port */	
	uint16_t secDserverIp[2];
	uint8_t  secDserverName[CONFIG_SIZE_SERVER_NAME];
	uint16_t secDserverPort;
	uint8_t  dServerUseIp;	/**<>**/
	// primary server config
	uint16_t priFserverIp[2];		/**< ip addr */
	uint8_t  priFserverName[CONFIG_SIZE_SERVER_NAME];	/**< domain name */
	uint16_t priFserverPort;	/**< port */	
	uint16_t secFserverIp[2];
	uint8_t  secFserverName[CONFIG_SIZE_SERVER_NAME];
	uint16_t secFserverPort;
	uint8_t  fServerUseIp;	/**<>**/
//  current use info
	uint8_t userIndex;
	USER_INFO userList[CONFIG_MAX_USER];
	
	GEO_FENCE_TYPE geoFence[10];
	
	uint16_t featureSet;			/**< feature set mapping 
														bit0: GPS Automatic local aiding
														bit1: GPS AssistNow offline
														bit2: GPS AssistNow online
														bit3: GPS AssistNow autonomous
														bit4: Lone Worker On/Off 
														bit5: No movement warning enable
														bit6: Man Down Enable
														nit7: FIFO Message enable
														bit8: Warning by Call action
														bit9: Warning by SMS action 
														bit10: Auto Answer
														bit11: DTMF On
														*/
	uint16_t loneWorkerInterval;	/*1 to 1000min*/
	uint8_t alarmCountdownTime; /*5s to 30s*/
	uint16_t noMovementInterval; /*1min to 1000min*/
	uint8_t operationMode; /*include: 
																	+0 = Full Running Mode GPS On, GSM On
																	+1 = GPS Only mode GPS on all time, GSM off.
																	+2 = GSM Only mode GSM on all time. GPS Off.
																	+3 = Standby mode	GSM Sleep,GPS in standby. GSM and GPS wake up by Report inverval time
																	+4 = Sleeping mode GSM Off, GPS Off  .GSM and GPS wake up by Report inverval time
																	*/
	uint8_t SOS_detection;
												/*
													0	Default, ( SOS off )
													1	SOS Key on
													2	Lone worker SOS
													3	No Movement SOS
													4	Man Down
												*/
	uint8_t geoFenceType;
												/*
												0	Default, No report on Geo fence
												1	Exclusion zone
												2	Inclusion zone
												*/
	uint8_t firmwareUpdateEnable;
	uint8_t language;
	uint8_t familyPalMode;
	
	uint8_t callMeSms[CONFIG_SIZE_SMS];
	uint8_t sosRespondedSms[CONFIG_SIZE_SMS];
	uint8_t	sosCancelledSms[CONFIG_SIZE_SMS];
	
	uint32_t crc;
}CONFIG_POOL;

extern CONFIG_POOL sysCfg;
extern uint8_t sysUploadConfig;

void CFG_Save(void);
void CFG_Load(void);
void CFG_Write(uint8_t *buff, uint32_t address, int offset, int length);
uint8_t CFG_CheckSum(CONFIG_POOL *sysCfg);
uint8_t CFG_Check(CONFIG_POOL *sysCfg);
#endif

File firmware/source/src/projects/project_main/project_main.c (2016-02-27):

/*
 * File:		usb_main.c
 * Purpose:		Main process
 *
 */

/* Includes */
#include "start.h"
#include "common.h"
#include "uart.h"
#include "usb.h"
#include "usbcfg.h"
#include "usbhw.h"
#include "usbcore.h"
#include "cdc.h"
#include "cdcuser.h"
#include "tick.h"
#include "dbg_cfg_app.h"
#include "system_config.h"
#include "spi.h"
#include "sst25.h"
#include "MKL25Z4.h"
#include "ff.h"
#include "diskio.h"
#include "project_common.h"
#include "audio.h"
#include "app.h"
#include "sysinit.h"
#include "lptmr.h"
#include "hw_config.h"
#include "modem.h"
#include "power_management.h"
#include "db.h"
#include "tracker.h"
#include "at_command_parser.h"
#include "dtmf_app.h"
#include "gprs_cmd_ctrl.h"
#include "accelerometer.h"
#include "gsm_gprs_tasks.h"
#include "sos_tasks.h"
#include "io_tasks.h"
#include "xl362_io.h"
#include "ambo_pedometer.h"
#include "pedometer_task.h"
#include "llwu.h"
#include "gps_task.h"

#define USER_FLASH_START		0x00002800
#define SMS_CHECK_TIMEOUT		300

void AppRun(void);

Timeout_Type tSMSCheckTimeout;
Timeout_Type tSleepTimeout;
extern uint8_t logEnable;
extern uint8_t incomingCall;
extern uint8_t powerOnLedFlash;
extern uint8_t ringing;
//extern uint8_t llwuInfoBuf[128];

uint8_t flagPwrOn = 0;
uint8_t flagPwrOff = 0;

uint8_t flagInitModem = 0,retryInitModemTimes = 0;
uint32_t mainCnt = 0;
uint32_t offset = 0;
uint8_t flagAutoAnswer = 0;

uint8_t ringingCount = 0;
uint8_t missCall = 0;

uint8_t pedometerEnable = 1;
uint8_t pedometerCntDownTime = 0;

void HardFault_Handler(void)
{
		NVIC_SystemReset();
}

void PIN_InterruptInit(void)
{

	// Configure CHG_DIS
  PORTB_PCR0 = ( PORT_PCR_MUX(1) |
									 PORT_PCR_IRQC(0x0A) | /* IRQ Falling edge */ 
                   PORT_PCR_PFE_MASK);
	// Configure ACCL_INT
  PORTC_PCR1 = ( PORT_PCR_MUX(1) |
									 PORT_PCR_IRQC(0x0A) | /* IRQ Falling edge */
                   PORT_PCR_PE_MASK |
                   PORT_PCR_PFE_MASK |
                   PORT_PCR_PS_MASK);
	// Configure PWR_KEY
  PORTC_PCR5 = ( PORT_PCR_MUX(1) |
									 PORT_PCR_IRQC(0x0A) | /* IRQ Falling edge */
                   PORT_PCR_PE_MASK |
                   PORT_PCR_PFE_MASK |
                   PORT_PCR_PS_MASK);
	
	// Configure SOS_KEY
  PORTC_PCR6 = ( PORT_PCR_MUX(1) |
									 PORT_PCR_IRQC(0x0A) | /* IRQ Falling edge */
                   PORT_PCR_PE_MASK |
                   PORT_PCR_PFE_MASK |
                   PORT_PCR_PS_MASK);
	
	// Configure GSM_RI
  PORTD_PCR4 = ( PORT_PCR_MUX(1) |
									 PORT_PCR_IRQC(0x0A) | /* IRQ Falling edge */
                   PORT_PCR_PE_MASK |
                   PORT_PCR_PFE_MASK |
                   PORT_PCR_PS_MASK);
	
	// Configure GPS_PULSE
//  PORTD_PCR6 = ( PORT_PCR_MUX(1) |
//									 PORT_PCR_IRQC(0x0A) | /* IRQ Falling edge */
//                   PORT_PCR_PE_MASK |
//                   PORT_PCR_PFE_MASK |
//                   PORT_PCR_PS_MASK);
	llwu_configure(0x0000, LLWU_PIN_FALLING, 0x1); //lpwtmr
	llwu_configure(0x0020, LLWU_PIN_FALLING, 0x1);
	llwu_configure(0x0040, LLWU_PIN_FALLING, 0x1);
	llwu_configure(0x0200, LLWU_PIN_FALLING, 0x1);
	llwu_configure(0x0400, LLWU_PIN_FALLING, 0x1);
	llwu_configure(0x4000, LLWU_PIN_FALLING, 0x1);
//	llwu_configure(0x8000, LLWU_PIN_FALLING, 0x1);
	NVIC_EnableIRQ(LLW_IRQn);
	NVIC_SetPriority(PORTD_IRQn, (1<< 0) - 1);
	NVIC_EnableIRQ(PORTD_IRQn);
}



void PORTD_IRQHandler (void)
{
	//GSM Ring PIN
	if(PORTD_ISFR == (1<<4))
	{
		//DIS_AU_CMU_EN_SET;
		PORTD_PCR4 |= PORT_PCR_ISF_MASK;
		AudioEnable();
		ringingFlag = 1;
		if (VoiceCallTask_GetPhase() == INCOMING_CALL)
		{
			ringingCount = 0;
			ringing = 1;
		}
	}
	//GPS_Pulse
	if(PORTD_ISFR == (1<<6))
	{
		PORTD_PCR6 |= PORT_PCR_ISF_MASK;
	}
}
#ifdef DEVICE_TESTING
extern uint32_t timer2Cnt;
#endif


void SysPwrOff(void)
{
	while(1)
	{
		SetLowPowerModes(LPW_LEVEL_3);
		SetLowPowerModes(LPW_NONE);
		if(llwuSource & LLWU_MWUF0)//LPWTMR
		{
			llwuSource &= ~LLWU_MWUF0;
			if(powerKeyHold3Sec)
			{
			PIN_InterruptInit();
			ledControlEnable = 1;
			USB_Init();                               // USB Initialization
			USB_Connect(TRUE);                        // USB Connect
			TPM0_Init(mcg_clk_hz,1000);
			powerKeyHold3Sec = 0;
			powerOnLedFlash = 1;			
			flagPwrOn = 1;
			flagPwrOff = 0;
			AudioStopAll();
			AudioPlayFile("1_1",TOP_INSERT);				// power on
			pwrStatus.value = POWER_ON;
			pwrStatus.oldValue = POWER_OFF;
				return;
			}
		}
	}
}

void SysSleep(void)
{
	uint32_t oldPedometer;
	uint32_t llpwWkTimes = 0;
	GSM_RTS_PIN_SET; /*Sleep module GSM*/
//	AudioStopAll();
//	AudioPlayFile("5_5", TOP_INSERT);
//	DelayMs(500);
	AudioStopAll();
	AUDIO_EN_CLR;
	SetLowPowerModes(LPW_NOMAL);
	PIN_InterruptInit();
	oldPedometer = Pedometer.stepCount;
	pedometerEnable = 0;
	while(1)
	{
		TPM0_DeInit();
		SetLowPowerModes(LPW_LEVEL_3);
		SetLowPowerModes(LPW_NONE);
		if(llwuSource & LLWU_WUF5) //CHG_DIS
		{
			llwuSource &= ~LLWU_WUF5;
			LLWU_F1 |= LLWU_F1_WUF5_MASK;	// write one to clear the flag
			break;
		}
		if(llwuSource & LLWU_WUF6)//ACCL_INT
		{
			llwuSource &= ~LLWU_WUF6;
			LLWU_F1 |= LLWU_F1_WUF6_MASK;	// write one to clear the flag
			pedometerEnable = 1;
			pedometerCntDownTime = 40; //10 second
		}
		else if(ACCEL_IN == 0 && pedometerEnable == 0)
		{
			pedometerEnable = 1;
			pedometerCntDownTime = 40; //10 second
		}
		if(pedometerCntDownTime)
		{
			//LED_BLUE_PIN_CLR;
			pedometerCntDownTime--;
		}
		else
		{
			//LED_BLUE_PIN_SET;
			pedometerEnable = 0;
		}
		
		if(llwuSource & LLWU_WUF9 || PWR_KEY_IN == 0)//PWR_KEY
		{
			InitTimeout(&tSleepTimeout,TIME_SEC(5));
			llwuSource &= ~LLWU_WUF9;
			LLWU_F2 |= LLWU_F2_WUF9_MASK;   // write one to clear the flag
			break;
		}
		if(llwuSource & LLWU_WUF10 || SOS_KEY_IN == 0)//SOS_KEY
		{
			InitTimeout(&tSleepTimeout,TIME_SEC(5));
			llwuSource &= ~LLWU_WUF10;
			LLWU_F2 |= LLWU_F2_WUF10_MASK;   // write one to clear the flag
			break;
		}
		if(llwuSource & LLWU_WUF14)//GSM_RI
		{
			llwuSource &= ~LLWU_WUF14;
			LLWU_F2 |= LLWU_F2_WUF14_MASK;   // write one to clear the flag
		//	DIS_AU_CMU_EN_SET;
			AudioEnable();
			ringingFlag = 1;
			if (VoiceCallTask_GetPhase() == INCOMING_CALL)
			{
				ringingCount = 0;
				ringing = 1;
			}
			break;
		}
//		if(llwuSource & LLWU_WUF15)//GPS_PULSE
//		{
//			llwuSource &= ~LLWU_WUF15;
//			LLWU_F2 |= LLWU_F2_WUF15_MASK;   // write one to clear the flag
//			if(GpsTask_GetPhase() == GPS_WAITING_FIX)
//				GpsTask_SetPhase(GPS_GET_LOCATION_PHASE);
//			break;
//		}
		if(llwuSource & LLWU_MWUF0)//LPWTMR
		{
			llwuSource &= ~LLWU_MWUF0;
			llpwWkTimes++;
			if(llpwWkTimes % 4 == 0)
			{
				TrackerTask();
				
				if(!((CHG_EN_IN == 0) &&
					(smsNewMessageFlag == 0) &&
					(VoiceCallTask_GetPhase() == NO_CALL) &&
					(SmsTask_GetPhase() == SMS_IDLE) &&
					(GprsTask_GetPhase() == TASK_SYS_SLEEP) &&
					(SosTask_IsAlarmActivated() == 0) && 
					(GpsTask_GetPhase() == GPS_IDLE)))
				{
					break;
				}
				
				if(Pedometer.updateReadyFlag)
				{
					Pedometer.updateReadyFlag = 0;
					//break;
				}
			}
			if(llpwWkTimes % 1200 == 0)
			{
				
				GSM_RTS_PIN_CLR; /*Wakeup module GSM*/ 
				DelayMs(100);
				MODEM_SendCommand(modemOk,modemError,1000,1,"AT+CBC\r"); //Batery check status)
				MODEM_SendCommand(modemOk,modemError,500,0,"AT+CCLK?\r"); //get rtc
				DelayMs(100);
				GSM_RTS_PIN_SET; /*Sleep module GSM*/
				
					// power off device if battery percent < 3%
				if (batteryPercent < 3)
				{
					break;
				}
			}
		}
	}
//	uart0_init(UART0_BASE_PTR,uart0_clk_khz,9600);
//	uart_init(UART1_BASE_PTR,periph_clk_khz,2400);
//	TICK_Init(1,mcg_clk_hz);
	TPM0_Init(mcg_clk_hz,1000);
//	SST25_Init();
//	AUDIO_Init();
	if(CHG_EN_IN)
	{
		USB_Init();
		USB_Connect(TRUE);                        // USB Connect
	}
}

/********************************************************************/
int main (void)
{
	uint32_t i;
	#ifdef DEVICE_TESTING
	uint8_t op_mode;
	#endif
	CFG_Load();
	
	#ifdef CMSIS  // If we are conforming to CMSIS, we need to call start here
	start();
	#endif
	SIM_SCGC5 |= (	SIM_SCGC5_PORTA_MASK
										| SIM_SCGC5_PORTB_MASK
										| SIM_SCGC5_PORTC_MASK
										| SIM_SCGC5_PORTD_MASK
										| SIM_SCGC5_PORTE_MASK );
	
	LED_RED_PIN_SET_OUTPUT;
	LED_BLUE_PIN_SET_OUTPUT;
	LED_GREEN_PIN_SET_OUTPUT;
	// turn all leds off
	LED_RED_PIN_SET;
	LED_GREEN_PIN_SET;
	LED_BLUE_PIN_SET;
	
	SIM_SOPT2 &= ~SIM_SOPT2_UART0SRC_MASK; // first clear the uart0 clk source field
	SIM_SOPT2 |= SIM_SOPT2_UART0SRC(0); // select the UART0 clock source

	SIM_SOPT2 &= ~SIM_SOPT2_TPMSRC_MASK; // first clear the TPM clk source field
	SIM_SOPT2 |= SIM_SOPT2_TPMSRC(1); // select the TPM clock source
	
	#ifdef DEVICE_TESTING
	PWR_EN_INIT;
	DIS_AU_CMU_EN_INIT;
	PWR_EN_SET;
	uart_init(UART1_BASE_PTR,periph_clk_khz,115200);
	PedometerTaskInit();
	PIN_InterruptInit();
	TICK_Init(1,mcg_clk_hz);
	TPM0_Init(mcg_clk_hz,1000);
	SST25_Init();
	AUDIO_Init();
	AudioPlayFile("1_1",TOP_INSERT);
	LPTMR_init(1000,LPTMR_USE_LPOCLK);
//	uart_putstr(UART1_BASE_PTR,"GT1022\r\n");
//	uart_putstr(UART1_BASE_PTR,"thienhaiblue\r\n");
//	sprintf((char *)mainBuf,"mcg_clk_khz:%d\r\n",mcg_clk_khz);
//	uart_putstr(UART1_BASE_PTR,mainBuf);
//	sprintf((char *)mainBuf,"core_clk_khz:%d\r\n",core_clk_khz);
//	uart_putstr(UART1_BASE_PTR,mainBuf);
//	sprintf((char *)mainBuf,"periph_clk_khz:%d\r\n",periph_clk_khz);
//	uart_putstr(UART1_BASE_PTR,mainBuf);
//	sprintf((char *)mainBuf,"pll_clk_khz:%d\r\n",pll_clk_khz);
//	uart_putstr(UART1_BASE_PTR,mainBuf);
	DelayMs(3000);
	//SST25_Write(0,"thienhaiblue",12);
//	SST25_Read(0,mainBuf,12);
		op_mode = what_mcg_mode();
		if (op_mode ==1) 
				DbgCfgPrintf("in BLPI mode now at %d Hz\r\n",mcg_clk_hz );
		if (op_mode ==2) 
				DbgCfgPrintf(" in FBI mode now at %d Hz\r\n",mcg_clk_hz );
		if (op_mode ==3) 
				DbgCfgPrintf(" in FEI mode now at %d Hz\r\n",mcg_clk_hz );
		if (op_mode ==4) 
				DbgCfgPrintf(" in FEE mode now at %d Hz\r\n",mcg_clk_hz );
		if (op_mode ==5) 
				DbgCfgPrintf(" in FBE mode now at %d Hz\r\n",mcg_clk_hz );
		if (op_mode ==6) 
				DbgCfgPrintf(" in BLPE mode now at %d Hz\r\n",mcg_clk_hz );
		if (op_mode ==7) 
				DbgCfgPrintf(" in PBE mode now at %d Hz\r\n",mcg_clk_hz );
		if (op_mode ==8) 
				DbgCfgPrintf(" in PEE mode now at %d Hz\r\n",mcg_clk_hz );
	while(1)
	{
		
	//	SIM_SOPT2 &= ~SIM_SOPT2_UART0SRC_MASK; // first clear the uart0 clk source field
	//	SIM_SOPT2 &= ~SIM_SOPT2_TPMSRC_MASK; // first clear the TPM clk source field
		LED_RED_PIN_SET;
	//	TICK_DeInit();
		TPM0_DeInit();
		SetLowPowerModes(LPW_LEVEL_3);
		SetLowPowerModes(LPW_NOMAL);
		LED_RED_PIN_CLR;
		//SetLowPowerModes(LPW_NONE);
		
		op_mode = what_mcg_mode();
	if (op_mode ==1) 
			DbgCfgPrintf("in BLPI mode now at %d Hz\r\n",mcg_clk_hz );
	if (op_mode ==2) 
			DbgCfgPrintf(" in FBI mode now at %d Hz\r\n",mcg_clk_hz );
	if (op_mode ==3) 
			DbgCfgPrintf(" in FEI mode now at %d Hz\r\n",mcg_clk_hz );
	if (op_mode ==4) 
			DbgCfgPrintf(" in FEE mode now at %d Hz\r\n",mcg_clk_hz );
	if (op_mode ==5) 
			DbgCfgPrintf(" in FBE mode now at %d Hz\r\n",mcg_clk_hz );
	if (op_mode ==6) 
			DbgCfgPrintf(" in BLPE mode now at %d Hz\r\n",mcg_clk_hz );
	if (op_mode ==7) 
			DbgCfgPrintf(" in PBE mode now at %d Hz\r\n",mcg_clk_hz );
	if (op_mode ==8) 
			DbgCfgPrintf(" in PEE mode now at %d Hz\r\n",mcg_clk_hz );
		
		
		TICK_Init(1,mcg_clk_hz);
	//	TPM0_Init(mcg_clk_hz,1000);
		//SST25_Init();
		//AUDIO_Init();
		//AudioPlayFile("1_1",TOP_INSERT);
		
//		
//		SIM_SOPT2 &= ~SIM_SOPT2_UART0SRC_MASK; // first clear the uart0 clk source field
//		SIM_SOPT2 |= SIM_SOPT2_UART0SRC(0); // select the UART0 clock source
//		
//		SIM_SOPT2 &= ~SIM_SOPT2_TPMSRC_MASK; // first clear the TPM clk source field
//		SIM_SOPT2 |= SIM_SOPT2_TPMSRC(1); // select the TPM clock source
		
//		mcg_clk_khz = mcg_clk_hz / 1000;
//		core_clk_khz = mcg_clk_khz;
//		periph_clk_khz = core_clk_khz / (((SIM_CLKDIV1 & SIM_CLKDIV1_OUTDIV4_MASK) >> 16)+ 1);
//		uart0_clk_khz = ((4000000 ) / 1000); // UART0 clock frequency will equal fast irc
		
//		uart_init(UART1_BASE_PTR,periph_clk_khz,115200);
//		uart_putstr(UART1_BASE_PTR,llwuInfoBuf);
		
//		sprintf((char *)mainBuf,"mcg_clk_khz:%d\r\n",mcg_clk_khz);
//		uart_putstr(UART1_BASE_PTR,mainBuf);
//		sprintf((char *)mainBuf,"core_clk_khz:%d\r\n",core_clk_khz);
//		uart_putstr(UART1_BASE_PTR,mainBuf);
//		sprintf((char *)mainBuf,"periph_clk_khz:%d\r\n",periph_clk_khz);
//		uart_putstr(UART1_BASE_PTR,mainBuf);
//		sprintf((char *)mainBuf,"pll_clk_khz:%d\r\n",pll_clk_khz);
//		uart_putstr(UART1_BASE_PTR,mainBuf);
//		sprintf((char *)mainBuf,"%d:%d:%d,%d,%d:%d:%02X:%d\r\n",mainCnt++,timer2Cnt,xl362.x,xl362.y,xl362.z,devicePosition,xl362.status,xl362.fifo_samples);
//		uart_putstr(UART1_BASE_PTR,mainBuf);
//		if(mainCnt % 4 ==0)
//			PedometerTask();
	//	sprintf((char *)mainBuf,"%d:%d:%d,%d,%d:%d:%02X:%d\r\n",mainCnt++,timer2Cnt,xl362.x,xl362.y,xl362.z,devicePosition,xl362.status,xl362.fifo_samples);
		//uart_putstr(UART1_BASE_PTR,mainBuf);
		
//		if(Pedometer.updateReadyFlag)
//		{
//			Pedometer.updateReadyFlag = 0;
//		//	sprintf((char *)mainBuf,"Pedometer.counter=%d\r\n",Pedometer.lastStepCount);
//			//uart_putstr(UART1_BASE_PTR,mainBuf);
//		}
		
		
		//DelayMs(3000);
	}
	#endif
	
	// turn all leds off
	LED_RED_PIN_SET;
	LED_GREEN_PIN_SET;
	LED_BLUE_PIN_SET;

	PWR_KEY_INIT;
	SOS_KEY_INIT;
	CHGB_STATUS_INIT;
	CHG_EN_PIN_SET_INPUT;
	PWR_EN_INIT;
	PWR_EN_SET;
	GPS_EN_INIT;
	DIS_AU_CMU_EN_INIT;
// 	GSM_DTR_PIN_SET_OUTPUT;
// 	GSM_DTR_PIN_SET; 
	
	SIM_SOPT2 &= ~SIM_SOPT2_UART0SRC_MASK; // first clear the uart0 clk source field
	SIM_SOPT2 |= SIM_SOPT2_UART0SRC(0); // select the UART0 clock source

	SIM_SOPT2 &= ~SIM_SOPT2_TPMSRC_MASK; // first clear the TPM clk source field
	SIM_SOPT2 |= SIM_SOPT2_TPMSRC(1); // select the TPM clock source
	
	GPSInit();
	PedometerTaskInit();
	//LOW POWER TIMER WAKEUP INIT
	llwu_configure(0x0000, LLWU_PIN_FALLING, 0x1); //lpwtmr
	NVIC_EnableIRQ(LLW_IRQn);
	//Tick init
	TICK_Init(1,mcg_clk_hz);
	//GPS uart0 init
	uart0_init(UART0_BASE_PTR,uart0_clk_khz,9600);
	//GSM uart1 Init
	uart_init(UART1_BASE_PTR,periph_clk_khz,115200);
	/// External Flash memory init
	SST25_Init();
	//Database init
	DB_FlashMemInit();
	//Audio Init
	AUDIO_Init();
	//Tracking init
	TrackerInit();
	//low power timer init
	LPTMR_init(250,LPTMR_USE_LPOCLK);
	Keys_Init();
	key.pwr.lastTime = 0;
	key.pwr.time = 0;
	key.pwr.status = KEY_UP;
	key.pwr.lastStatus = KEY_UP;
	if(pwrStatus.value == POWER_OFF)
	{
		//PWR_EN_INIT;
		//PWR_EN_CLR;
		while(pwrStatus.value == POWER_OFF)
		{
			if(CHG_EN_IN)
			{
				i = 3;
				GSM_RTS_PIN_SET_OUTPUT;
				GSM_RTS_PIN_CLR;
				DelayMs(200);
				while(i--)
				{
						if(MODEM_Init()==0)
							break;
				}
				GSM_RTS_PIN_SET;
				i = 30;
				while(CHG_EN_IN)
				{
					i++;
					if(i >= 30)//12.5s
					{
						i = 0;
						GSM_RTS_PIN_CLR;
						DelayMs(200);
						if(MODEM_SendCommand(modemOk,modemError,1000,0,"AT+CBC\r")) //Batery check status)
						{
							if(MODEM_Init())
								i = 20;
						}
						else
							MODEM_SendCommand(modemOk,modemError,500,0,"AT+CCLK?\r"); //get rtc
						GSM_RTS_PIN_SET;
					}
					SetLowPowerModes(LPW_LEVEL_3);
					SetLowPowerModes(LPW_NONE);
					if(powerKeyHold3Sec)
					{
						PIN_InterruptInit();
						ledControlEnable = 1;
						USB_Init();                               // USB Initialization
						USB_Connect(TRUE);                        // USB Connect
						TPM0_Init(mcg_clk_hz,1000);
						powerKeyHold3Sec = 0;
						powerOnLedFlash = 1;			
						flagPwrOn = 1;
						flagPwrOff = 0;
						AudioStopAll();
						AudioPlayFile("1_1",TOP_INSERT);				// power on
						pwrStatus.value = POWER_ON;
						pwrStatus.oldValue = POWER_OFF;
						break;
					}
				}
			}
			else
			{
				while(MODEM_PowerOff());
				SysPwrOff();
			}
		}
	}
	else
	{
		PIN_InterruptInit();
		ledControlEnable = 1;
		USB_Init();                               // USB Initialization
		USB_Connect(TRUE);                        // USB Connect
		TPM0_Init(mcg_clk_hz,1000);
		pwrStatus.value = POWER_ON;
		Keys_Init();
	}
	
	//PWR_EN_INIT;
//	PWR_EN_SET;
	
	sendFirstPacket = 1;
	//Task Init
	GpsTask_Init();
	GsmTask_Init();
	GprsTask_Init();
	SosTask_Init();
	VoiceCallTask_Init();
	SmsTask_Init();
	
	InitTimeout(&tSleepTimeout,TIME_SEC(5));
	
	AppRun();
	NVIC_SystemReset();
	while(1);
}

//Application
void AppRun(void)
{
	uint32_t temp = 0;
	logEnable = 3;
	GprsTask_StartTask(SEND_POWER_CMD_TASK);
	while(1)
	{
		// GSM process
		ModemCmd_Task();
		if((incomingCall == 0) && (inCalling == 0) && ModemCmdTask_IsIdle())
		{
			Gsm_Task();
		}
		
		Sos_Task();
		Io_Task();
		VoiceCall_Task();
		Sms_Task();
		Gprs_Task();
		if (SosTask_GetPhase() != SOS_END)
		{
			continue;
		}
		
		if(Pedometer.updateReadyFlag)
		{
			Pedometer.updateReadyFlag = 0;
			//AudioPlayFile("6_1", TOP_INSERT);
		}
		// Check incomming SMS
		if(
			 (GsmTask_GetPhase() == MODEM_SYS_COVERAGE_OK) &&
			 (SosTask_GetPhase() == SOS_END) &&
			 (SosTask_IsAlarmActivated() == 0) &&
			 (VoiceCallTask_GetPhase() == NO_CALL) &&
			 (SmsTask_GetPhase() == SMS_IDLE) &&
			 (ModemCmdTask_IsIdle())
		)
		{
			SetLowPowerModes(LPW_NOMAL);
			if(flagSaveTime)
			{
				flagSaveTime = 0;
				MODEM_SendCommand(modemOk,modemError,1000,1,"AT+CCLK=\"%02d/%02d/%02d,%02d:%02d:%02d+00\"\r",sysTime.year % 100,sysTime.month,sysTime.mday,sysTime.hour,sysTime.min,sysTime.sec);
			}
			if((smsNewMessageFlag || (CheckTimeout(&tSMSCheckTimeout) == TIMEOUT)))
			{
				InitTimeout(&tSMSCheckTimeout, TIME_SEC(SMS_CHECK_TIMEOUT));
				
				SMS_Manage(mainBuf,sizeof(mainBuf));
				
				if(smsNewMessageFlag)
				{
					smsNewMessageFlag = 0;
				}
			}
		}
		if(AudioStopCheck() &&
			(VoiceCallTask_GetPhase() == NO_CALL) &&
			(SosTask_IsAlarmActivated() == 0) &&
			(ringingDetectFlag == 0) && 
			(ringingFlag == 0) &&
			(smsNewMessageFlag == 0) &&
			(flagSaveTime == 0)
		)
		{
			AUDIO_EN_CLR;
		}
		pedometerEnable = 1;
		//System Sleep
		if(
			(VoiceCallTask_GetPhase() == NO_CALL) &&
			(SmsTask_GetPhase() == SMS_IDLE) &&
			(GprsTask_GetPhase() == TASK_SYS_SLEEP) &&
			(SosTask_IsAlarmActivated() == 0) &&
			(AudioStopCheck()) &&
			(PWR_KEY_IN) && 
			(smsNewMessageFlag == 0) &&
			(SOS_KEY_IN) &&
			(CheckTimeout(&tSleepTimeout) == TIMEOUT))
		{
			GSM_RTS_PIN_SET; //GSM sleep
			DIS_AU_CMU_EN_CLR;
			if(pwrStatus.value == POWER_OFF)
			{
				NVIC_SystemReset();
			}
			if((CHG_EN_IN == 0))
			{
				if((GpsTask_GetPhase() == GPS_IDLE))
					SysSleep();
			}
		}
		else
		{
			GSM_RTS_PIN_CLR;
			SetLowPowerModes(LPW_NOMAL);
		}
	}
}

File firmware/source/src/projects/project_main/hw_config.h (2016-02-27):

#ifndef __HW_CONFIG_H__
#define __HW_CONFIG_H__
#include "MKL25Z4.h"

#define PWR_KEY_PIN			5
#define PWR_KEY_INIT		PORTC_PCR5 |= PORT_PCR_MUX(1); \
												GPIOC_PDDR &= ~(1 << PWR_KEY_PIN)
#define PWR_KEY_IN			((GPIOC_PDIR & (1 << PWR_KEY_PIN)) >> PWR_KEY_PIN)

#define SOS_KEY_PIN			6
#define SOS_KEY_INIT		PORTC_PCR6 = PORT_PCR_MUX(1); \
												GPIOC_PDDR &= ~(1 << SOS_KEY_PIN)
#define SOS_KEY_IN			((GPIOC_PDIR & (1 << SOS_KEY_PIN)) >> SOS_KEY_PIN)

#define ACCEL_PIN				1
#define ACCEL_IN			(GPIOC_PDIR & (1 << ACCEL_PIN))

#define CHGB_STATUS_PIN			1
#define CHGB_STATUS_INIT		PORTD_PCR1 = PORT_PCR_MUX(1); \
														GPIOD_PDDR &= ~(1 << CHGB_STATUS_PIN)
#define CHGB_STATUS_IN			(GPIOD_PDIR & (1 << CHGB_STATUS_PIN))

#define CHG_EN_PIN		0
#define CHG_EN_PIN_SET_OUTPUT		PORTB_PCR0 = PORT_PCR_MUX(1);GPIOB_PDDR |= (1 << CHG_EN_PIN)
#define CHG_EN_PIN_SET_INPUT		PORTB_PCR0 = PORT_PCR_MUX(1);GPIOB_PDDR &= ~(1 << CHG_EN_PIN)
#define CHG_EN_IN								(GPIOB_PDIR & (1 << CHG_EN_PIN))
#define CHG_EN_SET							(GPIOB_PSOR = (1 << CHG_EN_PIN))
#define CHG_EN_CLR							(GPIOB_PCOR = (1 << CHG_EN_PIN))


#define PWR_EN_PIN		29
#define PWR_EN_SET		(GPIOE_PSOR = (1 << PWR_EN_PIN))
#define PWR_EN_CLR		(GPIOE_PCOR = (1 << PWR_EN_PIN))
#define PWR_EN_INIT		PORTE_PCR29 = PORT_PCR_MUX(1); \
											GPIOE_PDDR |= (1 << PWR_EN_PIN); \
											PWR_EN_CLR
											
#define GPS_EN_PIN		3
#define GPS_EN_SET		(GPIOD_PSOR = (1 << GPS_EN_PIN))
#define GPS_EN_CLR		(GPIOD_PCOR = (1 << GPS_EN_PIN))
#define GPS_EN_IN			(GPIOD_PDIR & (1 << GPS_EN_PIN))
#define GPS_EN_INIT		PORTD_PCR3 = PORT_PCR_MUX(1); \
											GPIOD_PDDR |= (1 << GPS_EN_PIN); \
											GPS_EN_CLR				

#define AUDIO_EN_PIN		0
#define AUDIO_EN_SET		(GPIOD_PSOR = (1 << AUDIO_EN_PIN))
#define AUDIO_EN_CLR		(GPIOD_PCOR = (1 << AUDIO_EN_PIN))
#define AUDIO_EN_IN		(GPIOD_PDIR & (1 << AUDIO_EN_PIN))
#define AUDIO_EN_INIT		PORTD_PCR0 = PORT_PCR_MUX(1); \
											GPIOD_PDDR |= (1 << AUDIO_EN_PIN); \
											AUDIO_EN_CLR			
											
											
#define DIS_AU_CMU_EN_PIN		7
#define DIS_AU_CMU_EN_SET		(GPIOC_PSOR = (1 << DIS_AU_CMU_EN_PIN))
#define DIS_AU_CMU_EN_CLR		(GPIOC_PCOR = (1 << DIS_AU_CMU_EN_PIN))
#define DIS_AU_CMU_EN_IN		(GPIOC_PDIR & (1 << DIS_AU_CMU_EN_PIN))
#define DIS_AU_CMU_EN_INIT		PORTC_PCR7 = PORT_PCR_MUX(1); \
											GPIOC_PDDR |= (1 << DIS_AU_CMU_EN_PIN); \
											DIS_AU_CMU_EN_CLR			
											
											
//#define DIS_AU_CMU_EN_PIN		30
//#define DIS_AU_CMU_EN_SET		(GPIOE_PSOR = (1 << DIS_AU_CMU_EN_PIN))
//#define DIS_AU_CMU_EN_CLR		(GPIOE_PCOR = (1 << DIS_AU_CMU_EN_PIN))
//#define DIS_AU_CMU_EN_IN		(GPIOE_PDIR & (1 << DIS_AU_CMU_EN_PIN))
//#define DIS_AU_CMU_EN_INIT		PORTE_PCR30 = PORT_PCR_MUX(1); \
//											GPIOE_PDDR |= (1 << DIS_AU_CMU_EN_PIN); \
//											DIS_AU_CMU_EN_CLR														


#define GSM_POWER_PIN	3
#define GSM_POWER_PIN_SET_OUTPUT	PORTB_PCR3 = PORT_PCR_MUX(1);GPIOB_PDDR |= (1 << GSM_POWER_PIN)
#define GSM_POWER_PIN_SET_INPUT		PORTB_PCR3 = PORT_PCR_MUX(1);GPIOB_PDDR &= ~(1 << GSM_POWER_PIN)
#define GSM_POWER_PIN_SET					GPIOB_PSOR = (1 << GSM_POWER_PIN)
#define GSM_POWER_PIN_CLR					GPIOB_PCOR = (1 << GSM_POWER_PIN)


#define GSM_RESET_PIN	0
#define GSM_RESET_PIN_SET_OUTPUT	PORTC_PCR0 = PORT_PCR_MUX(1);GPIOC_PDDR |= (1 << GSM_RESET_PIN)
#define GSM_RESET_PIN_SET_INPUT		PORTC_PCR0 = PORT_PCR_MUX(1);GPIOC_PDDR &= ~(1 << GSM_RESET_PIN)
#define GSM_RESET_PIN_SET					GPIOC_PSOR = (1 << GSM_RESET_PIN)
#define GSM_RESET_PIN_CLR					GPIOC_PCOR = (1 << GSM_RESET_PIN)

#define GSM_RTS_PIN	2
#define GSM_RTS_PIN_SET_OUTPUT	PORTC_PCR2 = PORT_PCR_MUX(1);GPIOC_PDDR |= (1 << GSM_RTS_PIN)
#define GSM_RTS_PIN_SET_INPUT		PORTC_PCR2 = PORT_PCR_MUX(1);GPIOC_PDDR &= ~(1 << GSM_RTS_PIN)
#define GSM_RTS_PIN_IN					(GPIOC_PDIR & (1 << GSM_RTS_PIN))
#define GSM_RTS_PIN_SET					GPIOC_PSOR = (1 << GSM_RTS_PIN)
#define GSM_RTS_PIN_CLR					GPIOC_PCOR = (1 << GSM_RTS_PIN)

#define GSM_DTR_PIN 21
#define GSM_DTR_PIN_SET_OUTPUT	PORTE_PCR21 = PORT_PCR_MUX(1); GPIOE_PDDR |= (1 << GSM_DTR_PIN)
#define GSM_DTR_PIN_SET_INPUT		PORTE_PCR21 = PORT_PCR_MUX(1); GPIOE_PDDR &= ~(1 << GSM_DTR_PIN)
#define GSM_DTR_PIN_SET					GPIOE_PSOR 	= (1 << GSM_DTR_PIN)
#define GSM_DTR_PIN_CLR					GPIOE_PCOR 	= (1 << GSM_DTR_PIN)


#define LED_GREEN_PIN	1
#define LED_BLUE_PIN		1
#define LED_RED_PIN	2


#define LED_GREEN_PIN_SET_OUTPUT		PORTA_PCR1 = PORT_PCR_MUX(1);GPIOA_PDDR |= (1 << LED_GREEN_PIN)
#define LED_GREEN_PIN_SET_INPUT		PORTA_PCR1 = PORT_PCR_MUX(1);GPIOA_PDDR &= ~(1 << LED_GREEN_PIN)
#define LED_GREEN_PIN_SET					GPIOA_PSOR = (1 << LED_GREEN_PIN)
#define LED_GREEN_PIN_CLR					GPIOA_PCOR = (1 << LED_GREEN_PIN)

#define LED_BLUE_PIN_SET_OUTPUT	PORTB_PCR1 = PORT_PCR_MUX(1);GPIOB_PDDR |= (1 << LED_BLUE_PIN)
#define LED_BLUE_PIN_SET_INPUT		PORTB_PCR1 = PORT_PCR_MUX(1);GPIOB_PDDR &= ~(1 << LED_BLUE_PIN)
#define LED_BLUE_PIN_SET					GPIOB_PSOR = (1 << LED_BLUE_PIN)
#define LED_BLUE_PIN_CLR					GPIOB_PCOR = (1 << LED_BLUE_PIN)
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
